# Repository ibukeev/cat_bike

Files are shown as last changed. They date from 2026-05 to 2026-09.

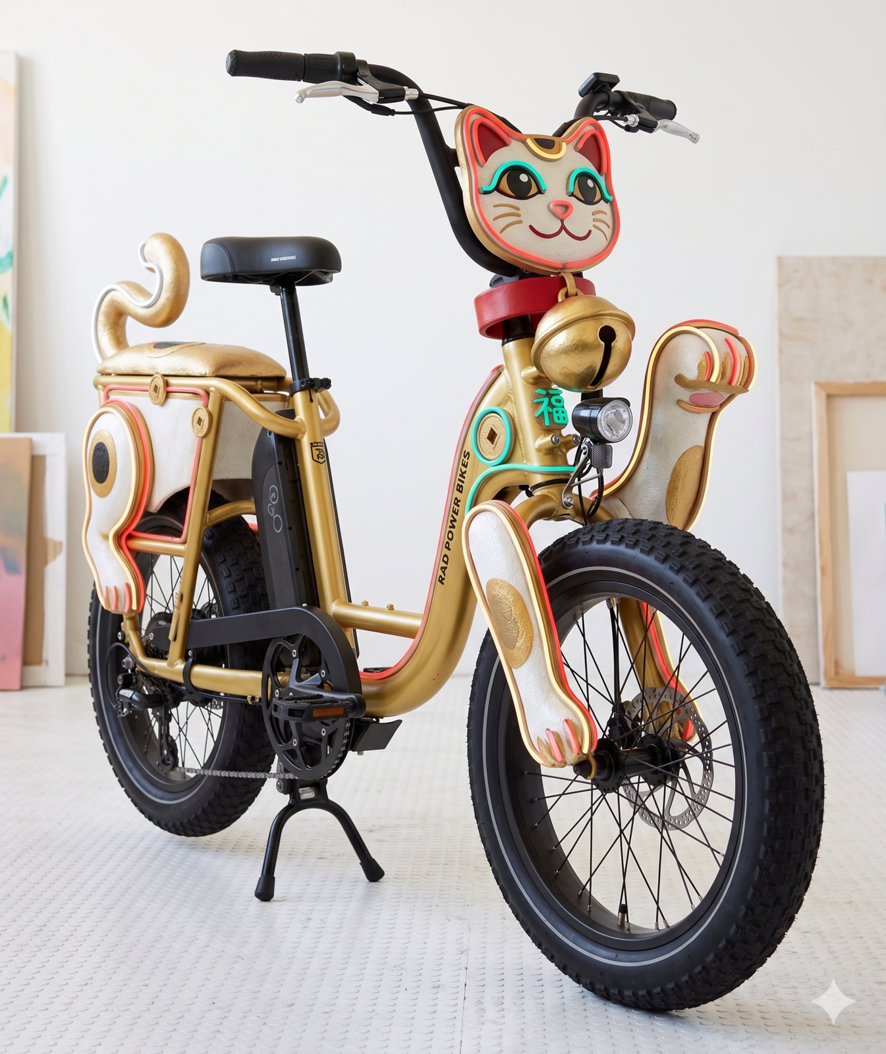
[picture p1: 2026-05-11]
assets/photos/Concepts/Other/Neon Maneki-Neko/Gemini_Generated_Image_xtucf9xtucf9xtuc.png

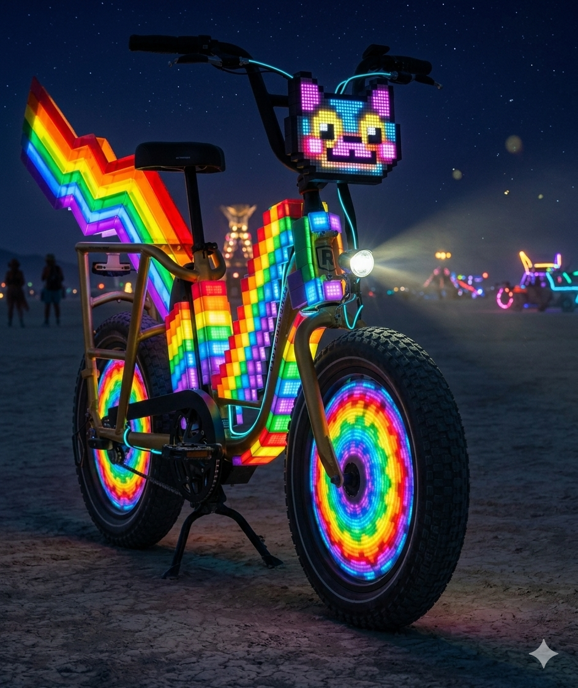
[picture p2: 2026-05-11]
assets/photos/Concepts/Other/16-Bit Nyan Astro-Cat/Gemini_Generated_Image_bhqeyjbhqeyjbhqe.png

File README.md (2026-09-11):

# Cat Bike LED Installation

Hardware project for a Burning Man electric bike LED installation.

## Getting the retained CAD and print files

Install [Git LFS](https://git-lfs.com/) before cloning this repository, then run:

```bash
git lfs install --local
git lfs pull
```

Selected mechanical CAD, meshes and slicer projects are stored with Git LFS.
Most generated output stays ignored; the curated build milestones are explicitly
tracked. A pointer-only checkout is not a usable CAD backup. Git history was not
rewritten when LFS was introduced, and retained working-file bytes are unchanged.

The repository tracks electrical design, Pixelblaze controller patterns, LED layout, battery/power notes, wiring, mechanical mounting ideas, and build documentation.

## Structure

- `hardware/electrical/` - battery, Pixelblaze controller, LEDs, and wiring.
- `hardware/mechanical/` - mounts, enclosures, and bike attachment parts.
- `software/pixelblaze-patterns/` - exported or source Pixelblaze patterns.
- `software/tools/` - helper scripts for mapping, validation, or exports.
- `docs/` - assembly notes, BOM, safety notes, and design logs.
- `assets/` - photos, diagrams, references, and visual documentation.
- `tests/` - manual and automated checks.

## Current build records

- [Lighting: mapper, patterns, setup, and validation](software/pixelblaze-patterns/mvp-bike/README.md).
- [Retained fabrication packages](hardware/mechanical/fabrication/3d-print/README.md): tiny prototypes, midsize Burning Man head, and controller enclosure.
- [Cleanup record and verified GitHub backup](docs/PROJECT_CLEANUP_PLAN.md).
- [Large-head working print files](hardware/mechanical/fabrication/3d-print/cat-head-full-size-v1/working/README.md): selected left/right lower-shell STL and slicer packages.

The large head has been reduced to [selected rebuild references](hardware/mechanical/fabrication/3d-print/cat-head-full-size-v1/README.md).
The rejected-output and cleanup-recovery archives were permanently deleted on
2026-09-10 after verifying the retained files in an independent GitHub download.
Only their inventories remain; deleted archive contents are not in the new backup.
No new whole-head print release was approved. The reports folder is empty.

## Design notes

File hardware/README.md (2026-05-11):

# Hardware

Use this area for electrical and mechanical design files.

- `electrical/battery/` - battery pack specs, charging notes, fuses, switches, and power budget.
- `electrical/controller-pixelblaze/` - Pixelblaze wiring, pinout, configuration, and controller mounting.
- `electrical/leds/` - LED strip or pixel specs, counts, layout, and power injection points.
- `electrical/wiring/` - cable plans, connector pinouts, harness drawings, and routing notes.
- `mechanical/mounts/` - brackets, clips, ties, and bike attachment parts.
- `mechanical/enclosures/` - controller, battery, and weather protection designs.

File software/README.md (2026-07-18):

# Software

Use this area for Pixelblaze patterns and helper scripts.

- `pixelblaze-patterns/` - pattern source, exports, and notes about palette, segment mapping, and controls.
- `tools/` - scripts for LED mapping, pattern export/import, validation, or documentation generation.

The 330 mm head-local pixel map and development patterns are under
`pixelblaze-patterns/cat-head/`.

Keep hardware-specific constants documented near the pattern or tool that uses them.

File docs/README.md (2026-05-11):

# Documentation

Use this area for build instructions, design decisions, safety notes, and field notes.

- `assembly/` - step-by-step installation and maintenance instructions.
- `bom/` - parts lists, vendor links, quantities, and alternates.
- `safety/` - power limits, fusing, waterproofing, strain relief, and Burning Man readiness checks.
- `notes/` - rough notes, measurements, and decision records.

## Current References

- `bom/cat-mask-ready-made-options.md` - ready-made cat mask purchase options and STL leads.

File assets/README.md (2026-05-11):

# Assets

Use this area for project media and reference material.

- `photos/` - installation photos, progress shots, and final build documentation.
- `diagrams/` - wiring diagrams, layout sketches, and exported schematics.
- `references/` - datasheets, vendor screenshots, inspiration, and external build references.

Prefer source files when possible, and export review-friendly images when useful.

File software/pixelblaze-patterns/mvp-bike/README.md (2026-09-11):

# MVP Bike Pixelblaze Pattern Set

This folder contains ten playa-riding patterns for the current 111-pixel bike
installation. Every visual pattern uses the same physical 2D mapper and also
includes a 1D fallback for editor preview.

## One-time Pixelblaze setup

1. Set **Settings > Pixels** to `111`.
2. Open the Mapper editor and paste `mvp-bike-spatial-map.js`.
3. Select **Contain** so the photographed bike proportions are preserved.
4. Save the mapper, then create one Pixelblaze pattern for each `*-2d.js` file.

The current mapper covers only the three established MVP body runs. It does not
yet include the later cat-head, whisker, eye, tail, panel, or wheel zones.

## Suggested saved order

| Order | Pixelblaze name | Source | Feel | Role |
|---:|---|---|---|---|
| 01 | Bike Aurora Front to Back | `aurora-front-to-back-2d.js` | Smooth | Flowing ambient color |
| 02 | Playa Techno Scanner | `playa-techno-scanner-2d.js` | Techno | Bouncing scanner and synthetic kick pulses |
| 03 | Ukrainian Flag Gentle Wave | `ukrainian-flag-gentle-wave-2d.js` | Smooth | Calm flag colors with restrained motion |
| 04 | Bioelectric Fur | `bioelectric-fur-2d.js` | Organic | Fine filaments and rear-to-front nerve impulses |
| 05 | Night Ride Beacon | `night-ride-beacon-2d.js` | Smooth | Continuous riding visibility and spatial orientation |
| 06 | Abyssinian Rosettes | `abyssinian-rosettes-2d.js` | Organic | Signature copper, aqua, and magenta cat identity |
| 07 | Playa Starfield | `playa-starfield-2d.js` | Smooth/show | Twinkling field with front-to-rear comets |
| 08 | Low Power Breath | `low-power-breath-2d.js` | Smooth | Simple continuously visible reserve mode |
| 09 | Neon Circuit Packets | `neon-circuit-packets-2d.js` | Techno | Beat-quantized, lane-switching data packets |
| 10 | Laser Lattice Techno | `laser-lattice-techno-2d.js` | Techno | Sliding laser grid with localized beat punches |

Each source exports its own Pixelblaze sliders. Defaults are starting points,
not calibrated electrical limits.

## Bench and bike testing

- Start physical commissioning with Pixelblaze global brightness at 15-25%.
- Verify the mapper with a one-pixel chase before judging spatial direction.
- Confirm that low `x` is the front and high `x` is the rear.
- Watch the 5 V supply, injection wiring, connectors, and strips for heating.
- Measure actual current before raising the global brightness limit.
- Keep the bike's independent headlight, taillight, and reflectors in service;
  these decorative patterns are not replacements for required safety lighting.

Run the off-device syntax and render-math check from the repository root:

```bash
node tests/automated/validate_mvp_bike_patterns.js
```

The local check catches parse errors, missing render entry points, non-finite
color output, out-of-range RGB/SV output, mapper count errors, and failures at
slider endpoints. Pixelblaze preview, visual quality, current draw, and thermal
behavior still require physical review.

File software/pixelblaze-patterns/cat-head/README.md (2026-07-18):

# Cat Head Pixelblaze Development Files

These files implement the head-local 52-pixel map defined by the formal
cat-head lighting development plan.

## Files

- cat-head-pixel-map.json: machine-readable wiring and optical allocation.
- cat-head-commissioning.js: isolated-head pixel and zone test pattern.
- cat-head-modes.js: riding, parked/show, and reserve behavior scaffold.

## Bench Setup

Configure Pixelblaze for 52 WS2812/SK6812-compatible RGB pixels and connect the
head or coupon as an isolated chain starting at pixel zero.

The physical data order is:

1. Left whisker carrier, including masked pixel H07.
2. Left eye.
3. Fourteen glow panels in Gate 1 pair order, left then right.
4. Right eye.
5. Right whisker carrier, including masked pixel H51.

Power the modules in parallel. Do not route the complete head current through
the first pixel module or through a long strip-copper path.

## Whole-Bike Integration

The patterns in this folder use head-local indices 0-51. When the head is
integrated into the whole-bike S5 range, apply the final S5 start offset before
using the same segment logic. Keep the head last on the initial single
Pixelblaze data output so removing it does not interrupt earlier zones.

The two reserved carrier pixels, H07 and H51, must remain black in every normal
pattern.

## Physical Calibration

These patterns are development scaffolds, not evidence that an optical gate has
passed. After Gate L1:

- Calibrate per-whisker brightness only if measured coupling variation requires
  it.
- Tune eye brightness after diffuser material and setback are locked.
- Tune each facet pair after the production cassettes are installed.
- Record measured current and final brightness caps in the validation report.

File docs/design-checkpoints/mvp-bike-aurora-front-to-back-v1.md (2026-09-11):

# MVP Bike Aurora Front-to-Back v1 Checkpoint

## Current output

- Pattern source: `software/pixelblaze-patterns/mvp-bike/aurora-front-to-back-2d.js`
- Spatial map: `software/pixelblaze-patterns/mvp-bike/mvp-bike-spatial-map.js`
- Reference pattern: `~/Projects/BM_personal_LED-projects /LED Hat Small/LED_hat_small/firmware/patterns/Archive/1D Aurora Borealis.epe`

## Accepted behavior

- Aurora curtains move from the bike front at low normalized `x` toward the rear at high normalized `x`.
- The effect uses both `x` and `y`: `x` controls travel and `y` bends and shimmers the curtains.
- The inherited palette character is green, chartreuse, turquoise, pink, and purple.
- Controls cover speed, curtain width, shimmer, brightness, saturation, palette weighting, and curtain count.
- A faint teal ambient floor maintains nighttime bike readability between curtains.

## Validation

- Source was evaluated in a Pixelblaze-compatible local harness.
- The pattern rendered 111 mapped coordinates across repeated frames without non-finite RGB output.
- Direction was checked against the current spatial-map contract: front is low `x`, rear is high `x`.
- On-device appearance and current draw remain unverified.

## Rejected or unsafe variants

- Do not use `index/pixelCount` as the primary position; it follows wiring rather than bike space.
- Do not run initial commissioning at unrestricted global brightness.
- The ambient floor is intentionally dim and is not a substitute for legally required bicycle lighting.

## Regeneration

The source is hand-authored and authoritative; there is no generator command.

## Next physical review

1. Paste the source into a new Pixelblaze pattern and save it as `01 Bike Aurora Front to Back`.
2. Confirm the mapper is saved and Pixelblaze is configured for 111 pixels.
3. Begin with the Pixelblaze global brightness limit at 15-25%.
4. Verify visible travel begins at the front and reaches the rear.
5. Tune speed, curtain width, shimmer, palette, and brightness with the pattern controls.
6. Observe the 5 V supply, wiring, and connectors for heating before increasing brightness.

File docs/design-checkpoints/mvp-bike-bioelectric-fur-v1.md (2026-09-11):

# MVP Bike Bioelectric Fur v1 Checkpoint

## Current output

- Pattern: `software/pixelblaze-patterns/mvp-bike/bioelectric-fur-2d.js`
- Spatial mapper: `software/pixelblaze-patterns/mvp-bike/mvp-bike-spatial-map.js`
- Target: the current 111-pixel MVP bike installation

## Accepted behavior

- Render fine, organic cyan-to-violet filaments over the whole bike.
- Send periodic electrical impulses from the rear (high x) toward the front
  (low x).
- Keep the effect internally timed; do not require a Sensor Expansion Board.
- Provide controls for motion speed, fur density, fur contrast, impulse rate,
  impulse strength, impulse width, color, and master brightness.
- Include a 1D fallback so the pattern remains visible before a 2D mapper is
  selected.

## Validation

- Static JavaScript syntax check: passed with Node's module parser.
- Render-math harness: passed 79,920 samples across 720 frames and all 111
  normalized mapper coordinates; every HSV output was finite and saturation and
  value remained within 0-1.
- Observed simulated value range with defaults: 0.020329-0.785307.
- 1D fallback render: passed with finite output.
- Pixelblaze 2D preview: pending user review.
- Physical 111-pixel bike review: pending.

## Rejected or deferred variants

- Do not synchronize the cat-head eyes, facets, or whiskers in this version;
  the current output targets only the established 111-pixel MVP bike map.
- Do not require sound input or the Sensor Expansion Board.
- Avoid full-frame white flashes; bright sparks remain localized around the
  traveling impulse.

## Exact regeneration command

This pattern is hand-authored and has no generation step. To perform the local
syntax check from the repository root:

```bash
node --input-type=module --check < software/pixelblaze-patterns/mvp-bike/bioelectric-fur-2d.js
```

## Next physical review

1. Configure Pixelblaze for 111 pixels.
2. Load `mvp-bike-spatial-map.js` as the mapper and select `Contain`.
3. Paste `bioelectric-fur-2d.js` into a new Pixelblaze pattern.
4. Confirm that each impulse travels from the rear toward the front.
5. Start with the default brightness, then tune it against the installed power
   limit and nighttime viewing distance.
6. Report whether the fur should be calmer, sharper, denser, or more colorful
   before starting the next pattern.

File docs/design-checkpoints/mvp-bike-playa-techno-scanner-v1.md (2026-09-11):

# MVP Bike Playa Techno Scanner v1 Checkpoint

## Current output

- Pattern source: `software/pixelblaze-patterns/mvp-bike/playa-techno-scanner-2d.js`
- Spatial map: `software/pixelblaze-patterns/mvp-bike/mvp-bike-spatial-map.js`
- Hat references: `Tunnel Scanner.epe` and `Riot Pulse.epe` in the LED Hat Small archive.

## Accepted behavior

- A hard scanner bounces across normalized bike space.
- Each internally generated techno kick launches an additional pulse from front to rear.
- The effect uses `y` for spatial tilt and moving grit, preventing the three physical runs from behaving as duplicated 1D strips.
- No audio sensor is required.
- Controls cover BPM, scanner speed, width, trail, kick strength, color, spatial tilt, grit, and brightness.
- Beat energy remains spatially localized rather than using continuous full-frame strobing.

## Validation

- Source was evaluated in a Pixelblaze-compatible local harness.
- The pattern rendered 111 mapped coordinates across repeated frames without non-finite color output.
- On-device appearance and current draw remain unverified.

## Rejected or unsafe variants

- The original hat references rely on Sensor Expansion Board data; this MVP version does not.
- Avoid continuous full-frame high-frequency strobing because of rider distraction and photosensitivity risk.
- Do not commission at unrestricted global brightness.

## Regeneration

The source is hand-authored and authoritative; there is no generator command.

## Next physical review

1. Paste the source into Pixelblaze and save it as `02 Playa Techno Scanner`.
2. Start with global brightness limited to 15-25%.
3. Confirm the kick pulse always travels from the bike front toward the rear.
4. Tune BPM near 120-135 for the intended techno feel.
5. Verify wiring and connectors remain cool before increasing brightness.

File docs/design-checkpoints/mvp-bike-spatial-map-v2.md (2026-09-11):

# MVP Bike Spatial Map v2 Checkpoint

## Current output

- Mapper source: `software/pixelblaze-patterns/mvp-bike/mvp-bike-spatial-map.js`
- Review overlay: `software/pixelblaze-patterns/mvp-bike/mvp-bike-spatial-map-review.svg`
- Review generator: `software/tools/generate_mvp_bike_spatial_map_review.js`
- Source photo: `assets/photos/Original_bike/pixed LAYAOUT.jpg`

## Accepted interpretation

- Configure 111 pixels.
- The three numbered red arrows are the centerlines and data directions.
- Section 1 is pixels 1-31, following the upper rear frame toward the rack.
- Section 2 is pixels 32-59, following the lower rear frame from the rear axle toward the crank.
- Section 3 is pixels 60-111, starting at the seat/battery edge, descending through the step-through curve, and rising toward the front stem.
- The handwritten numerals are labels rather than illuminated geometry.

## Validation

- The mapper returns exactly 111 finite 2D coordinates.
- Counts are 31, 28, and 52.
- The SVG overlays every generated pixel on the annotated photograph and labels each section start and end.
- Pixelblaze preview and a physical one-pixel chase remain pending.

## Rejected variants

- V1 reduced the arrows to generic straight runs and omitted important bends.
- V1 incorrectly started section 3 near the crank.
- Do not treat the handwritten numerals or arrowheads as extra LED branches.

## Exact regeneration command

From the repository root:

```bash
node software/tools/generate_mvp_bike_spatial_map_review.js
```

## Next physical review

1. Open the SVG and confirm each colored line follows the corresponding red arrow.
2. Paste the mapper into Pixelblaze with 111 pixels and `Contain` selected.
3. Run a one-pixel chase to confirm starts, ends, and increasing-index direction.
4. Record any installed pixels whose spacing differs from uniform spacing along the arrows.

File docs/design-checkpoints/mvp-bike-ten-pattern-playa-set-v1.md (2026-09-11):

# MVP Bike Ten-Pattern Playa Set v1 Checkpoint

## Current outputs

- Collection guide: `software/pixelblaze-patterns/mvp-bike/README.md`
- Spatial mapper: `software/pixelblaze-patterns/mvp-bike/mvp-bike-spatial-map.js`
- Off-device validator: `tests/automated/validate_mvp_bike_patterns.js`
- Target: current 111-pixel MVP bike body installation

| Pattern source | Character |
|---|---|
| `aurora-front-to-back-2d.js` | Smooth traveling aurora curtains |
| `playa-techno-scanner-2d.js` | Techno scanner and synthetic kick pulses |
| `ukrainian-flag-gentle-wave-2d.js` | Calm blue/yellow fabric motion |
| `bioelectric-fur-2d.js` | Organic filaments and nerve impulses |
| `night-ride-beacon-2d.js` | Restrained continuous riding glow |
| `abyssinian-rosettes-2d.js` | Copper, aqua, and magenta signature rosettes |
| `playa-starfield-2d.js` | Smooth twinkle and traveling comets |
| `low-power-breath-2d.js` | Simple dim reserve breathing |
| `neon-circuit-packets-2d.js` | Beat-quantized circuit lanes and packets |
| `laser-lattice-techno-2d.js` | Crossing laser grid and localized beat punches |

## Accepted behavior and constraints

- Preserve a varied ten-pattern set with smooth, organic, functional, and
  techno choices rather than tuning one effect before hardware review.
- Use the established 111-pixel 2D mapper for physical motion. Low normalized
  `x` is the bike front and high `x` is the rear.
- Keep every source self-contained with Pixelblaze sliders and a 1D editor
  fallback.
- Generate all beat timing internally; no Sensor Expansion Board is required.
- Keep techno impacts spatially localized. Do not add rapid full-frame white
  strobing.
- Treat brightness sliders as visual controls, not calibrated electrical power
  limits.

## Validation performed

- Node module syntax checks passed for all six sources created or recovered in
  this continuation.
- The complete local harness passed the mapper and all ten patterns.
- The mapper returned exactly 111 finite normalized coordinates.
- Each pattern rendered 240 frames at 30 FPS, all 111 mapped pixels, its 1D
  fallback, and every slider at `0`, `0.5`, and `1`.
- Total checked color samples per pattern ranged from 28,749 to 29,748.
- No non-finite colors or out-of-range RGB, saturation, or value outputs were
  detected.
- Pixelblaze preview, physical appearance, current draw, and thermal behavior
  remain unverified.

## Rejected, unsafe, or deferred variants

- No full-frame high-frequency strobe mode was added because it can distract
  the rider and create a photosensitivity hazard.
- No pattern depends on sound input because the current MVP does not require a
  Sensor Expansion Board.
- Cat-head eyes, facets, whiskers, tail, panels, and wheels remain out of this
  mapper; their absolute whole-bike offsets are not yet established.
- These decorative LEDs do not replace the bike's independent headlight,
  taillight, or reflectors.
- No pattern was uploaded to the physical Pixelblaze in this work session.

## Exact validation command

The patterns are hand-authored and have no generation command. From the
repository root, rerun the collection validator with:

```bash
node tests/automated/validate_mvp_bike_patterns.js
```

## Next physical review

1. Configure Pixelblaze for 111 pixels and save the mapper with **Contain**.
2. Run a one-pixel chase to verify all three path directions before evaluating
   the spatial effects.
3. Load the ten sources using the saved names and order in the collection
   README.
4. Start at 15-25% Pixelblaze global brightness.
5. Review the smooth group first, then the three techno patterns, and note which
   effects are too fast, too sparse, or visually confused on the real strip
   geometry.
6. Measure supply current and inspect the converter, injection wiring,
   connectors, and strips for heating before increasing brightness.
7. Record favorite patterns and slider settings for the next tuning pass.

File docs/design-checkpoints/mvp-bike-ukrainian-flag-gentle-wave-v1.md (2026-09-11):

# MVP Bike Ukrainian Flag Gentle Wave v1 Checkpoint

## Current output

- Pattern source: `software/pixelblaze-patterns/mvp-bike/ukrainian-flag-gentle-wave-2d.js`
- Spatial map: `software/pixelblaze-patterns/mvp-bike/mvp-bike-spatial-map.js`
- Hat reference: `Ukrainian Flag.epe` in the LED Hat Small archive.

## Accepted behavior

- The visual remains predominantly a static Ukrainian flag: blue above and yellow below.
- A small boundary ripple and mild fabric shading move from the bike front toward the rear.
- No strobe, blink, or Sensor Expansion Board behavior is included.
- Controls cover band boundary, boundary softness, ripple amount, motion speed, fabric shading, and brightness.
- Default motion is intentionally slow and restrained.

## Validation

- Source was evaluated in a Pixelblaze-compatible local harness.
- The pattern rendered 111 mapped coordinates across repeated frames without non-finite or out-of-range RGB output.
- On-device color appearance and current draw remain unverified.

## Rejected or unsafe variants

- The hat pattern's strobe and blink modes are intentionally omitted.
- Do not use rapid full-frame flashes during riding.
- Do not commission at unrestricted global brightness.

## Regeneration

The source is hand-authored and authoritative; there is no generator command.

## Next physical review

1. Paste the source into Pixelblaze and save it as `03 Ukrainian Flag Gentle Wave`.
2. Start with global brightness limited to 15-25%.
3. Confirm upper spatial pixels are blue and lower spatial pixels are yellow.
4. Confirm the gentle fold motion travels from front to rear.
5. Adjust the blue/yellow boundary if the sparse bike geometry favors one band.

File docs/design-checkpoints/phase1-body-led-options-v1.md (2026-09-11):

# Phase 1 body LED option set — resumable checkpoint

## Current review files

- Comparison: `assets/photos/Concepts/Selected/Bio-Luminescent Abyssinian/Phase_1_LED_References/body-strip-design-options-v1/00-comparison-sheet.jpg`
- Individual options: `01-minimal-feline-silhouette.png`, `02-bioluminescent-dashes.png`, `03-feline-ribcage.png`, and `04-geometric-facet-echo.png` in the same folder.
- Option descriptions and fabrication implications: `body-strip-design-options-v1/README.md`.
- Exact built-in image-generation sequence: `body-strip-design-options-v1/generation-prompts.md`.

## Status and accepted constraints

- No visual direction is selected yet.
- Options use removable 12 V LED strips rather than permanent illuminated panels.
- Fork, wheel, tire, spoke, brake rotor, chain, crank, steering, cable, and moving-component lighting is excluded.
- The cat head should remain the main focal point; body lighting should support rather than overpower it.

## Validation

- Four distinct directions were generated from the real side-profile bike geometry.
- The labeled comparison sheet was visually checked after correcting its original label order.
- Options 1 and 2 mostly use existing tubes; options 3 and 4 require removable backing bars and more fabrication.

## Rejected/unsafe variants

- The earlier fork-mounted strip was rejected.
- Generated strip placement is not clearance proof and must not be used as a cutting template.

## Regeneration

Use the built-in `image_gen` edit flow and follow `body-strip-design-options-v1/generation-prompts.md` in order. The sequence uses the latest image as the sole edit input (`num_last_images_to_include: 1`).

## Next physical review

1. User selects option 1–4 or names elements for a hybrid.
2. Produce a refined selected-side visual, then a mirrored opposite-side visual.
3. Measure only the selected paths and create the cut-length, connector, data-direction, power-injection, and zip-tie map.

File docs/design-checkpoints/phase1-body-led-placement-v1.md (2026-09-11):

# Phase 1 body LED placement — resumable checkpoint

## Current review output

- `assets/photos/Concepts/Selected/Bio-Luminescent Abyssinian/Phase_1_LED_References/phase1-body-strip-placement-proposal-v1.png`
- Base geometry reference: `assets/photos/Original_bike/front_back/02-bike-side-profile-wide.jpg`
- Aesthetic reference: `assets/photos/Concepts/Selected/Bio-Luminescent Abyssinian/Gemini_Generated_Image_5en5a65en5a65en5.png`

## Proposed decisions shown

- Phase 1 uses exposed/removable 12 V addressable strips rather than illuminated body panels.
- The strongest visual line follows the fixed lower frame and step-through/belly curve.
- Secondary strips describe the upper rear haunch/rack, one rear support, the forward edge of the battery/torso area, and the underside of the basket.
- Cyan/teal is illustrative; Pixelblaze color and animation remain programmable.
- The proposal is a visual-placement study, not yet a cut-length or pixel-index drawing.

## Validation performed

- Compared the concept, the existing Phase 1 reference, and the real side-profile photograph.
- Corrected the first generated variant after it incorrectly placed LEDs on the front fork.
- Confirmed the retained routes visually sit on fixed frame/rack members and avoid wheels and spokes in this side view.

## Rejected or unsafe variants

- No LED strips on front fork legs, wheels, spokes, tires, or brake rotors.
- No fabricated glowing side panels in Phase 1.
- Do not treat the generated glow as proof of clearance; chain, crank, battery-removal, cable, and tire clearances require physical measurement before cutting.

## Exact regeneration recipe

Built-in `image_gen` edit flow:

1. Load the real side-profile photograph, the current Phase 1 LED reference, and the selected bioluminescent concept.
2. Generate a dusk placement mockup with narrow cyan/teal LED-node strips on the fixed lower belly/frame, upper rear haunch/rack, rear support, forward torso/battery edge, and basket underside.
3. Run a correction edit with the latest generated image as the only input and this instruction:

   `Remove the entire cyan LED strip from the front fork leg. There must be no LEDs on either fork leg, wheel, spokes, tire, brake rotor, or steering/moving component. Preserve the strips on the fixed lower frame and step-through belly curve, lower horizontal frame tube, rear upper haunch/rack tube, rear support strut, forward torso/battery edge, and basket underside. Preserve everything else unchanged.`

## Next physical-review steps

1. User reviews the silhouette and chooses which proposed lines to keep or remove.
2. Measure retained paths directly on the bike with a flexible tape.
3. Record segment lengths, LED counts, data directions, connectors, power injection, and zip-tie locations.
4. Produce left/right/front/rear fabrication overlays before cutting the waterproof strip.

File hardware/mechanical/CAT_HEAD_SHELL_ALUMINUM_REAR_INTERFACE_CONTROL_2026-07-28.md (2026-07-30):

# Cat Head Shell / Aluminum Rear Interface Control

**Date:** 2026-07-28
**Status:** V0.5-M2 rear-interface digital correction passed; receipt, coupon,
complete-head correction, fabrication, final ASA-print, and riding release
gates remain held
**Integration authority:** User

## 1. Purpose

This document coordinates the separate cat-head shell and aluminum-mount work
sessions. It is the authority for geometry or behavior shared by those two
workstreams. It does not replace either workstream checkpoint:

- Shell defects and required validation:
  `hardware/mechanical/CAT_HEAD_MOUNT_AND_SHELL_PHYSICAL_FIT_REVIEW_2026-07-28.md`
- Aluminum V0.5-M2 coordinated interface state:
  `hardware/mechanical/fabrication/metal/cat-head-frame-fixed-mount-v0/V05_M2_COORDINATED_BOTTOM_M5_CHECKPOINT_2026-07-29.md`

The aluminum V0.5-M2 files are the tracked handoff authority. V0.4-M2 remains immutable history. The shell session must consume but not edit the aluminum-owned config, generator, summary, or checkpoint. The aluminum session must not edit Gate 3,
Gate 5, or Gate 8 shell sources while their existing partial state is under
review.

## 2. Coordination rule

No session may independently change or release a shared-interface parameter.
A proposed change must be recorded here with its affected shell and metal
files, reviewed in both workstreams, and approved by the user before either
session regenerates shared geometry or releases material for fabrication.

This coordination freeze is not a fabrication approval. It preserves a common
reference while the physical-feedback pass remains open.

## 3. Workstream ownership

| Area | Primary workstream | Coordination requirement |
|---|---|---|
| Bike boss plate, side webs, compact adapter, metal tether | Aluminum mount | May not move the head rear plane without shared approval. |
| Aluminum head backplate and lower angle connectors | Aluminum mount | M2 owns the retained plate centers, angle bases, uprights, cheeks, plugs, taper pads, compound rail cuts, and lower M5 stack; the shell must consume their exact envelope. |
| Exterior head shape, shell partitioning, reinforcement, mirror-panel seats | Printed shell | Must preserve the coordinated rear plane and rail system unless a shared change is approved. |
| Upper/front printed rail sockets and M4 retention paths | Shared | Must be generated from the same rail-axis and socket-roll revision as the aluminum backplate and rails. |
| Rear ASA frame, rear shell facets, removable rear cassette | Printed shell | Proposed architecture only; attachment and load transfer are shared. |
| Backplate perimeter fasteners, rail pass-throughs, wiring, drainage, tool access | Shared | Neither session may finalize independently. |
| Final assembly and service sequence | Shared | Must be validated with complete shell, aluminum, rail, fastener, and tool envelopes. |

## 4. Retained shared geometry baseline

The following values are the current V0.2 coordination baseline. They are
frozen against unilateral changes but remain review-only and are not released
for cutting:

**Active aluminum integration review artifact:**
`hardware/mechanical/fabrication/metal/cat-head-frame-fixed-mount-v0/output/review-model/frame-fixed-mount-v02-review.blend`

The user is currently reviewing this BLEND and confirmed that the aluminum
work remains review-only. No physical backplate has been ordered or cut. The
parallel aluminum work began under the assumption that the printed ASA rear
structure would not be redesigned; that assumption is now explicitly open
because physical findings F-04 and F-29 require a rear-interface and
printability correction.

The user accepts the overall V0.2 aluminum architecture as the direction to
retain. This is concept acceptance, not a cutting release. The current printed
ASA rear base conflicts with that metal envelope and must be revised. Possible
movement of the lower rail targets toward center remains TBD.

| Interface parameter | Provisional baseline |
|---|---|
| Mount architecture | Frame-fixed, no weld, and no printed polymer in the primary bike-connector load path. |
| Head coordinate bounds | X `-151.915..151.915`, Y `0..269.345`, Z `0..330` mm. |
| Rear interface plane center | Head coordinates `[0, 264.01125, 171.74025]` mm. |
| Rear interface outward normal | `[0, 0.990996, 0.133894]`. |
| Rear-plane mating pitch | `-18.894665°` relative to the estimated boss plane. |
| Aluminum head backplate | 3 mm 6061 trapezoid; 60 mm top, 120 mm bottom, 79.663819 mm high. |
| Adapter-to-backplate pattern | Four 6.6 mm paths at X `±22` mm and local V `±20` mm. |
| Internal rail stock | Nominal 19.05 mm square aluminum tube. |
| Lower rail targets | Head coordinates `[-40, 267.336, 147.132]` and `[40, 267.336, 147.132]` mm. |
| Rail orientation | Pitch `17.662°`, yaw `5.595°`; upper M4 axes approximately `5.333°` from head-horizontal. |
| Upper retention | One transverse M4 bolt per blind printed upper socket. |

Any need to change one of these values must be raised here before either model
is edited.

### 4A. Lower rail-target inward-shift assessment

At the current lower target, local backplate V is approximately `-24.832` mm
and the trapezoid half-width is approximately `54.351` mm. With a 19.05 mm
tube centered at X `±40`, the nominal tube/pass-through envelope leaves about
`4.826` mm to the sloped plate edge. The nearest lower 6.6 mm adapter-hole
center is about `18.637` mm away.

Moving a rail center to X `±35` improves nominal edge clearance to about
`9.826` mm, but reduces center distance to the lower adapter hole to about
`13.869` mm. The raw tube half-width plus M6-hole radius already consume about
`12.825` mm of that distance, leaving only about `1.044` mm before accounting
for the rail shoe, bolt head, washer, nut, manufacturing tolerance, or tool
access.

Therefore a simple inward shift is not approved. The user accepted X `±40` as
the baseline for the first coordinated ASA rear-structure revision. If rail
movement is still needed after full collision review, optimize rail X/V
position, adapter holes, backplate outline, lower-shoe envelope, and upper
socket axes as one shared interface change.

## 5. V0.4-M2 historical baseline and open shared interfaces

The V0.4-M2 baseline below remains immutable history. Its bottom shell M5 pair is superseded by the coordinated V0.5 delta in Section 5A; do not fabricate from V0.4.

The user ordered Randall Manufacturing `1.5 x 1.5 x 0.125 inch` 6063-T6
equal angle and authorized the aluminum workstream to incorporate it without
changing the accepted rail axes, X `+/-40` targets, 21 mm sockets, backplate
outline, adapter holes, or six-plus-six M5 plate-hole centers. The M2 authority
is `hardware/mechanical/interfaces/cat-head-shell-aluminum-interface-v04.json`
and the M2 checkpoint dated 2026-07-29. No plate is ordered or cut. The angle
is ordered but not yet received or measured.

Historical V0.4 details, superseded only where Section 5A says so and never released for fabrication:

1. six backplate-to-shell M5 centers: local X/V `(-10,30)`, `(10,30)`,
   `(-20,0)`, `(20,0)`, `(-10,-30)`, and `(10,-30)` mm;
2. six angle-base M5 centers, three per side, using right centers `(36,-30)`,
   `(47.4,-30)`, `(38,-9)` mm and mirrored left X;
3. one 45 mm primary angle per rail with full 38.1 mm upright and 29 mm
   trimmed base, plus one `45 x 25 x 3.175 mm` outer cheek per rail;
4. a matched 14.7 mm nominal solid plug, two hand-fit aluminum taper pads, and
   two M5 x 40 lower crossbolts per rail at 14 and 29 mm from the compound
   bearing centerline;
5. rail centerline length `152.476123 +/-0.25 mm`, 160 mm rough cuts,
   compound edge range `147.0677..157.8845 mm`, and upper M4 station
   133.776123 mm from the lower bearing datum; and
6. no backplate rail cutout and no external shell pass-through; service remains
   through the open rear aperture.

The M1 monolithic CNC shoes and 149.672 mm square-ended rails are superseded.
The generator plate-local V basis was also corrected to match the shared
interface; the earlier reversed M1 visualization must not be used for shell
integration.

Still open and held:

1. receipt inspection of the ordered angle's leg widths, thickness, inside
   radius, straightness, and alloy/temper marking;
2. actual rail inside dimensions/corner radii and fitted-plug machining;
3. one physical rear-interface/angle coupon proving flush countersinks,
   compound bearing contact, taper pads, M5 access, clamp behavior, and repeatable
   assembly;
4. shell/rear-cassette and six ASA pad integration around the exact M2 metal
   and tool envelope, followed by complete A-39 validation;
5. rear cassette seam, overlap, sealing, removal, wiring, and drainage;
6. actual headlight housing, beam, steering, and cable clearance; and
7. tether, proof-load, vibration, and progressive ride validation.

The regenerated M2 collision matrix records no intersection between the nine
checked metal parts and the current V6.1 fixed shells, bezel, or bottom keel.
This is a useful baseline, not a shell release: any new shell revision must
preserve or improve that clearance and rerun the complete assembly/service
matrix.

### 5A. V0.5 coordinated bottom-center delta

Shell coordination commit `0077da2330c0eeae403ab8698c6c1db58bd1b22f` proved that the V0.4 bottom shell M5 centers at X `+/-10`, V `-30` cannot carry a safe printed boss through the required preassembled-M2 motion: the largest clear circular boss was 11 mm, leaving only 0.5 mm outside the 10 mm washer. No plate had been ordered or cut, so the shared change was accepted.

V0.5 changes only the bottom pair to X `+/-7.4`, V `-30` and specifies `14 x 36 x 12 mm` bottom ASA pads. The top and middle shell centers, all six angle-base holes, plate outline, adapter holes, rail axes, X `+/-40` targets, 21 mm sockets, M4 retention, rail lengths, and compound datums are unchanged. The authoritative shared file is `hardware/mechanical/interfaces/cat-head-shell-aluminum-interface-v05.json`.

The V0.5 aluminum generator passes every check. Recorded margins are 7.0819 mm hole-to-plate edge, 4.8319 mm washer-to-edge, 2.8319 mm 14 mm tool-to-edge, 0.8 mm between opposing 14 mm tools, and 7.3963 mm from a bottom tool envelope to the nearest adapter-hole edge. The coordinated bottom pads also pass washer bearing, tool containment, opposing-pad, seated-metal, and pad-specific sampled-motion checks.

The full V7 shell candidate is not released. Its coordinated rerun still finds non-bottom blockers: middle-M5 nut-tool interference with lower crossbolts, preassembled lower-crossbolt sweep into the upper shells, socket-cap overlap with the receiver shells, and a root-recess validator sign/definition defect. These are recorded in `hardware/mechanical/fabrication/3d-print/cat-head-full-size-v1/review/gate9-v7-v05-coordinated-interface-validation.json`.

### 5B. V0.5 shell-consumer correction

The Gate 9 V7 shell consumer has now closed all four non-bottom failures from
the historical coordinated rerun without changing aluminum-owned CAD or any
locked V0.5 datum. The correction uses pre-installed shell-side captive M5
nylocs, exact 31 mm lower-crossbolt service tunnels cut only through new
internal truss material, 0.3 mm-relieved removable socket-cap receivers, and a
root validator that separately measures controlled shell overlap and cavity
reach.

All 15 rear-interface geometry checks pass. The complete M2 module clears 14
sampled socket-withdrawal positions and four rear-clearance positions, and
insertion is the exact reverse. All eight modified printed parts also have real
Prusa MK4 Generic ASA support/brim slices with at least 10 mm XY margin; the
minimum is 11.935 mm on `left_lower_face`.

This is a digital rear-interface pass, not a complete-head or fabrication
release. Physical angle/rail receipt, a rear-interface coupon, the remaining
F-07 through F-29 shell/insert/eye/panel work, lamp and steering clearance, and
physical safety validation remain held. The authoritative closure record is
`hardware/mechanical/fabrication/3d-print/cat-head-full-size-v1/review/gate9-v7-v05-shell-correction-validation.json`.

## 6. Rear cassette proposal C-001

**Status:** Proposed for coordinated evaluation; not accepted and not modeled.

To correct physical-fit findings F-04 and F-29 without shrinking the complete
head, evaluate a removable rear cassette that:

- moves the lower-face shell seams forward and transfers the aft shell facets
  to a rear-loaded printed module;
- incorporates or attaches to the shallow printed rear frame around the
  aluminum backplate;
- preserves the current rear plane, adapter hole pattern, and rail targets if
  practical;
- installs and removes from behind after the front and side shells are joined;
- makes each lower-face STL comfortably printable with its required brim and
  supports;
- leaves the aluminum backplate and rail structure as the primary mount load
  path; and
- treats the exterior rear facets as replaceable shell/finish parts rather
  than primary bike-mount structure.

The preferred implementation is not a permanent fusion of cosmetic ASA to the
aluminum plate. It is a mechanically attached printed rear module that may be
removed with, or separately from, the aluminum backplate according to the
approved service sequence.

## 7. Required comparison before accepting C-001

After the user closes the feedback pass, compare at least these three variants
without releasing fabrication:

| Variant | Required evidence |
|---|---|
| Existing lower-face partition and difficult rotation | Saved PrusaSlicer orientation, brim/support footprint, support volume, print time, and surface-risk review. |
| Uniform head scale reduction | Smallest scale that creates an acceptable orientation, plus impact on every mount, fastener, eye, insert, panel, and rear-plane interface. |
| Rear cassette / moved seam | Lower-face and cassette bed margins, support volumes, complete assembly collision test, backplate/rail integration, and service sequence. |

Acceptance of a variant requires the user to review the exterior appearance,
assembly sequence, printer evidence, and aluminum-interface impact together.

## 8. Shared release gates

No rear-interface metal or replacement structural shell is released until:

1. the user declares the physical-feedback pass complete;
2. both workstreams use the same rear-plane and rail-target revision;
3. the full shell and aluminum assembly has zero collision through insertion,
   seated, fastened, and removal states;
4. the rear cassette or retained partition passes the complete build-plate test
   in A-37;
5. all backplate, angle-connector, cassette, washer, nut, and tool envelopes are validated;
6. a physical rear-interface and angle-connector coupon passes;
7. actual headlight and steering clearance is validated;
8. an independent metal safety tether is specified; and
9. the stationary proof-load, vibration, and progressive ride-test plan is
   approved.

## 9. Cross-session change log

| ID | Date | Proposal or change | Status | Affected workstreams |
|---|---|---|---|---|
| C-001 | 2026-07-28 | Evaluate rear-loaded cassette incorporating aft shell facets to improve lower-face printability and rear service. | Proposed; no CAD action | Shell and aluminum |
| C-002 | 2026-07-28 | Use `frame-fixed-mount-v02-review.blend` as the active aluminum integration-review artifact. | User review in progress; no fabrication approval inferred | Shell and aluminum |
| C-005 | 2026-07-28 | Record aluminum fabrication commitment state: no plates ordered; only rectangular aluminum rail stock purchased. | Confirmed by user; rail dimensions still require physical verification | Shell and aluminum |
| C-003 | 2026-07-28 | Preserve the V0.2 aluminum rear-plane pose, plate outline, adapter pattern, and rail targets where practical while redesigning the printed ASA rear structure around that baseline. | Preferred coordination target; integrated validation required | Shell and aluminum |
| C-004 | 2026-07-28 | Rebuild the upper/front printed sockets to the coordinated V0.2 compound rail axes and socket roll; do not reuse pre-correction upper-shell G-code. | Required shared correction; regeneration held until feedback closes | Shell and aluminum |
| C-006 | 2026-07-28 | Retain the overall V0.2 aluminum architecture and redesign the conflicting printed ASA rear base/shell around its complete envelope. | Concept accepted by user; interface details and fabrication remain open | Shell and aluminum |
| C-007 | 2026-07-28 | Keep lower rail targets at X `±40` for the first ASA rear redesign; evaluate inward movement only if the complete collision review still requires it, including adapter-hole, backplate-edge, shoe/tool, upper-socket, and shell impacts. | Accepted baseline; conditional study deferred | Shell and aluminum |
| C-008 | 2026-07-29 | Authorize the aluminum workstream to finalize lower shoes, anti-crush paths, rail cut/drill stations, and backplate perimeter/shoe holes from V0.4 without changing the 21 mm socket geometry. | Authorized and completed as V0.4-M1 | Aluminum, then shell integration |
| C-009 | 2026-07-29 | Adopt the V0.4-M1 six-plus-six plate pattern and CNC-shoe handoff. | Superseded by C-010 before metal fabrication | Shell and aluminum |
| C-010 | 2026-07-29 | Use the ordered Randall 38.1 x 38.1 x 3.175 mm 6063-T6 angle for hand-fabricated M2 lower connectors; retain the six-plus-six plate centers, frozen axes/targets/sockets, add compound-cut 152.476123 mm rails, solid plugs, taper pads, outer cheeks, and matched M5 x 40 crossbolts. | M2 digital preflight passed; angle ordered but not received; no plate ordered or cut; coupon and shell A-39 pending | Aluminum, then shell integration |
| C-011 | 2026-07-29 | Move only the bottom shell M5 pair from X `+/-10` to X `+/-7.4` at V `-30` and use `14 x 36 x 12 mm` bottom ASA pads. | Accepted and generated as V0.5-M2; aluminum PASS; bottom pads PASS; full V7 shell candidate held on non-bottom issues; no fabrication or ASA-print release | Shared |
| C-012 | 2026-07-29 | Resolve the four non-bottom V7 shell-consumer failures with pre-installed captive M5 nylocs, service tunnels through only new truss material, relieved removable socket-cap receivers, and corrected root-overlap semantics. | Digital rear-interface PASS; real Prusa ASA feasibility PASS; physical coupon, complete-head correction, fabrication, and final ASA release held | Printed shell consuming locked V0.5 |

## 10. Next synchronization action

No backplate is ordered or cut. The rectangular 19 x 19 x 2 mm rail stock is
purchased. The Randall 6063-T6 equal angle is ordered but not received; its
actual section remains a receipt gate.

The shell workstream now has a digital PASS for the V0.5-M2 rear interface and
its complete modeled A-39 insertion, seated, fastened, tool, and removal phases.
Its next action is to preserve that locked interface while correcting the
remaining complete-head physical-fit findings, then validate an
angle/rail/rear-interface coupon with the received hardware. The final ASA head
print remains prohibited until those broader gates pass.

When the angle arrives, the aluminum workstream records the received dimensions
before cutting even a coupon. Final plate or bracket cutting remains held until
the receipt inspection, shell integration review, and physical angle-interface
coupon plan are accepted.

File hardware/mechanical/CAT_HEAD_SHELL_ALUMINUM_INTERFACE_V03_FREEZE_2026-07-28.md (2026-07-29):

# Cat Head Shell / Aluminum Interface V0.3 Freeze

**Date:** 2026-07-28
**Revision:** `CAT-HEAD-SHELL-ALUMINUM-V0.3`
**Status:** Frozen for coordinated rear-architecture comparison; not a print,
cut, drilling, or riding release
**Supersedes:** the unmeasured nominal-rail assumption in C-005 and the active
shared dimensions duplicated in the Gate 8 and aluminum V0.2 configs

## 1. Authority

The machine-readable authority is:

`hardware/mechanical/interfaces/cat-head-shell-aluminum-interface-v03.json`

Both new workstreams resolve that file rather than treating their historical
configs as shared-interface authorities:

- shell:
  `hardware/mechanical/fabrication/3d-print/cat-head-full-size-v1/config/gate9-coordinated-asa-candidate-v1.json`
- aluminum:
  `hardware/mechanical/fabrication/metal/cat-head-frame-fixed-mount-v0/config/frame-fixed-mount-v03-interface.json`

Gate 8 and aluminum V0.2 remain immutable historical/review baselines. Their
generated outputs are not relabeled as V0.3.

## 2. Measured rail stock

The user physically measured and confirmed:

| Property | V0.3 value |
|---|---:|
| Outside width | 19.0 mm |
| Outside height | 19.0 mm |
| Wall thickness | 2.0 mm |
| Derived inside width/height | 15.0 x 15.0 mm |
| Available stock length | 36 in = 914.4 mm |
| Dimensional consistency | Reported the same along the stock |
| Corner radius | Not measured |
| Alloy/temper | Not confirmed |

Final rail cut lengths remain deferred until the lower shoes, solid plugs,
socket seating depth, rear cassette, and complete fit-up are fixed.

## 3. Frozen comparison interface

- Preserve the 330 mm full-size head exterior for the primary comparison.
- Rear plane center: `[0, 264.01125, 171.74025]` mm.
- Rear plane outward normal: `[0, 0.990996, 0.133894]`.
- Aluminum backplate: 3 mm 6061-T6 trapezoid, 60 mm top, 120 mm bottom,
  79.663819 mm high.
- Adapter pattern: four 6.6 mm paths at X `±22` and local V `±20` mm.
- Lower rail targets: X `±40`, Y `267.336`, Z `147.132` mm.
- Accepted rail axes:
  - left `[-0.09294, -0.94874, 0.30208]`;
  - right `[0.09294, -0.94874, 0.30208]`.
- Rail pitch `17.662°`; yaw `5.595°`.
- Socket roll: head X projected perpendicular to each rail axis.
- Socket opening: 20.5 x 20.5 mm.
- Nominal clearance from measured stock: 1.5 mm total, 0.75 mm per side.
- Socket insertion depth: 30 mm.
- Upper retention: one 4.5 mm M4 clearance path 10 mm inside the mouth.
- Expected M4-axis deviation from head X: `5.333°`.
- Primary bike connector load path remains metal only.
- Rear service direction remains rear-loaded after joining the main shells.

Changing any frozen value requires one coordinated revision affecting the
shell, backplate, lower shoes, rails, sockets, validation, and checkpoints.

## 4. Validation performed

The standalone interface validator passed:

- rear-plane normal unit error within `0.0001`;
- lower-target plane error `0.0000831` mm, below the `0.01` mm limit;
- rail-axis unit and symmetry checks;
- measured-wall derivation of the 15 x 15 mm inside profile;
- 0.75 mm nominal socket clearance on every side, within the frozen 0.5–1.0
  mm review range;
- 914.4 mm stock covers two 158.172 mm modeled routes before final fit/cut
  allowance;
- raw 19 mm tube envelope leaves approximately 4.851 mm to the sloped
  backplate edge at each X `±40` lower target.

The 4.851 mm value covers only the raw tube. It is not clearance approval for
the lower shoe, flange, bolt, washer, nut, manufacturing tolerance, hand, or
tool envelope.

Both consumer preflights passed and reported the identical revision:

- `PASS - GATE 9 SHARED INTERFACE PREFLIGHT`;
- `PASS - METAL V0.3 SHARED INTERFACE PREFLIGHT`.

Python compilation and JSON parsing passed. Blender, STL export, drawing
export, rendering, PrusaSlicer, and physical coupon tests were intentionally
not run.

## 5. Generation holds

V0.3 geometry generation remains disabled because:

1. the rear cassette, retained partition, and scale alternatives have not been
   compared and selected;
2. Gate 8 append-only structural mesh joins still violate the required
   single-body topology contract;
3. lower shoes and anti-crush plugs are not detailed;
4. rail pass-throughs and backplate perimeter/shoe holes are not released;
5. the complete shell/aluminum/hardware/tool collision matrix does not exist;
6. a matching Gate 9 shell validation report does not exist; and
7. physical rear-interface and socket coupons have not passed.

## 6. Rejected or unsafe variants

- Do not restore the nominal 19.05 mm active-stock assumption.
- Do not resize the 20.5 mm socket solely from nominal catalog dimensions; use
  a full-scale coupon to account for ASA shrinkage and printer variation.
- Do not move the X `±40` rail targets independently.
- Do not treat raw tube-to-plate edge clearance as lower-shoe clearance.
- Do not overwrite or relabel Gate 8 or aluminum V0.2 outputs as V0.3.
- Do not cut rails to the 158.172 mm modeled reference length.
- Do not release backplate or shoe holes before the rear architecture and
  complete service sequence are selected.

## 7. Exact preflight commands

Run from the repository root:

```bash
python3 hardware/mechanical/interfaces/cat_head_interface.py
python3 hardware/mechanical/fabrication/3d-print/cat-head-full-size-v1/source/prepare_gate9_shared_interface.py
python3 hardware/mechanical/fabrication/metal/cat-head-frame-fixed-mount-v0/source/prepare_frame_fixed_mount_v03_interface.py
```

There is intentionally no V0.3 Blender regeneration command yet. The next
versioned generators must consume the preflight loaders, write the V0.3
revision and interface hash into their validation reports, and use the new
Gate 9/V0.3 output namespaces before generation is enabled.

Historical commands remain documented in the Gate 8 and aluminum V0.2
checkpoints but are not V0.3 release commands.

## 8. Next review steps

1. Build review-only geometry for the retained partition, smallest-useful
   uniform scale, and full-size rear-cassette/moved-seam alternatives.
2. Include complete backplate, rail, raw lower-shoe allowance, hardware, and
   tool envelopes in every comparison.
3. Slice each alternative with the required brim/support policy and record
   actual bed margin, support volume, time, supported exterior area, and
   removal risk.
4. User selects the architecture and service sequence.
5. Repair the single-body topology and validation foundation before detailed
   subsystem geometry or any full structural print.

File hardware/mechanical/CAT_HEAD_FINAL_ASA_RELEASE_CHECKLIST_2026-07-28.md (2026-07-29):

# Cat Head Final ASA Candidate Release Checklist

**Date:** 2026-07-28
**Status:** Draft execution checklist; awaiting physical-feedback closure and
rear-architecture decision
**Target:** One production-candidate black-ASA structural head set for the
Prusa MK4S, followed by full physical acceptance before riding

## 1. Authority and scope

This is the execution and go/no-go checklist for the next full structural
print. It consolidates, but does not replace:

- `hardware/mechanical/CAT_HEAD_MOUNT_AND_SHELL_PHYSICAL_FIT_REVIEW_2026-07-28.md`
  — authoritative findings F-01 through F-29 and tests A-01 through A-39;
- `hardware/mechanical/CAT_HEAD_SHELL_ALUMINUM_REAR_INTERFACE_CONTROL_2026-07-28.md`
  — authoritative shared shell/aluminum interface and decisions C-001 through
  C-007; and
- the relevant Gate 3, Gate 5, Gate 8, mirror-panel, and aluminum resumable
  checkpoints.

Checking an item here does not override a more specific acceptance condition
in either authority document. This checklist does not itself authorize CAD
regeneration, metal cutting, or a full ASA print.

## 2. Current decisions and holds

- [x] Use black ASA for the final opaque structural head shell.
- [x] Retain the overall frame-fixed, no-weld V0.2 aluminum architecture.
- [x] Keep the lower rail targets at X `±40` for the first coordinated shell
  revision.
- [x] Keep printed polymer out of the primary bike-connector load path.
- [x] No aluminum plate has been ordered or cut; only rectangular rail stock
  has been purchased.
- [x] Treat current Gate 8 generated outputs and pre-correction upper-head
  G-code as potentially stale or obsolete.
- [x] Do not regenerate while physical feedback remains open.
- [ ] User explicitly declares the physical-feedback pass complete.
- [ ] User selects the rear-shell architecture for the next version.

**Recommended rear-shell choice:** preserve the approved full head scale and
evaluate a rear-loaded cassette/moved rear seam around the V0.2 aluminum
envelope. Do not accept the existing difficult lower-face orientation as the
production solution. Use global scaling only if a documented slicer comparison
shows that a genuinely small reduction solves the problem without compromising
the complete interface set.

## 3. Gate 0 — Close requirements and freeze the shared interface

- [ ] Confirm there are no additional physical defects to record.
- [ ] Select rear cassette/moved seam, retained partition, or uniform scaling.
- [ ] Record the selected architecture in the interface-control change log.
- [ ] Physically measure purchased rail outside width, wall thickness, length,
  corner radius, straightness, and alloy/temper if known.
- [ ] Freeze one shared interface revision containing:
  - rear plane center and normal;
  - aluminum-backplate outline and thickness;
  - adapter-to-backplate hole pattern;
  - lower rail targets and axes;
  - upper socket pitch, yaw, roll, depth, and M4 retention path;
  - rail stock dimensions; and
  - intended assembly and service direction.
- [ ] Give that revision one identifier used by both shell and aluminum
  validation reports.
- [ ] Confirm that neither session is about to order, cut, drill, or regenerate
  shared-interface parts independently.

**Gate 0 pass:** feedback is closed, rear architecture is selected, actual rail
stock is measured, and both sessions share one frozen interface revision.

## 4. Gate 1 — Recover and freeze a trustworthy source state

- [ ] Inventory every current Gate 3, Gate 5, and Gate 8 uncommitted change.
- [ ] Map each retained change to one or more findings F-01 through F-29.
- [ ] Identify the source/config revision and command that produced every
  existing STL, BLEND, report, render, and G-code intended for comparison.
- [ ] Mark outputs with unknown or mismatched provenance as stale; do not use
  them as regeneration inputs or acceptance evidence.
- [ ] Review the incomplete rear-base work and failed regeneration without
  resetting or discarding user/session changes.
- [ ] Select one traceable source baseline for the corrective iteration.
- [ ] Select a new versioned output location for the final-ASA candidate so
  Gate 8 physical-test artifacts remain available for comparison.
- [ ] Record exact generation, rendering, validation, and slicing commands in
  the resumable checkpoint before geometry edits begin.

**Gate 1 pass:** every retained source change and comparison output has known
provenance, and the corrective iteration starts from one traceable state.

## 5. Gate 2 — Lock the global shell and rear architecture

- [ ] Import the accepted V0.2 aluminum review geometry and unchanged approved
  exterior shell into one integration assembly.
- [ ] Generate a collision map for aluminum plate, adapter hardware, lower
  shoes, rails, upper sockets, rear base, and all adjacent shells.
- [ ] Produce review-only comparisons for:
  - existing lower-face partition and difficult orientation;
  - smallest useful uniform scale reduction; and
  - rear cassette/moved rear seam at unchanged exterior scale.
- [ ] For each comparison, report shell part count, bed margin including brim,
  support volume, print time, seam count, assembly order, service access, and
  aluminum-interface changes.
- [ ] User approves the selected exterior scale, shell partition, rear seam,
  rear service opening, and assembly sequence.
- [ ] Verify that the selected rear module itself fits the MK4S bed in a stable,
  support-efficient orientation.
- [ ] Preserve X `±40` lower rail targets unless the collision study proves a
  coordinated rail/plate/socket change is required.

**Gate 2 pass:** the shell architecture is approved visually and mechanically,
and every production section has a credible print orientation before detailed
connectors or reinforcement are added.

## 6. Gate 3 — Repair the geometry-generation foundation

- [ ] Replace append-only overlapping structural meshes with true dependable
  unions or an equivalent single-body construction.
- [ ] Reject every production STL with more than one connected component unless
  a removable part is deliberately exported separately.
- [ ] Retain closed-manifold, boundary-edge, and nonmanifold-edge checks.
- [ ] Add finished-exterior deviation checks against the approved clean faceted
  baseline.
- [ ] Clip all ribs, gussets, pads, flange roots, and connectors to the interior
  envelope before union.
- [ ] Add complete seated-state and insertion-path collision checks.
- [ ] Add slicer checks for floating islands, unsupported first extrusions,
  brim/support boundary fit, and saved production orientation.
- [ ] Fail generation when any required check fails; no report-only warnings
  for production blockers.

**Gate 3 pass:** validation can no longer accept the disconnected, protruding,
colliding geometry classes seen in the PLA prototype.

## 7. Gate 4 — Correct every subsystem

### 7A. Rear shell and aluminum interface

- [ ] Rear structure installs from behind after the main shells are joined.
- [ ] No rail, plate, shoe, bolt, washer, nut, tool, or insertion envelope
  intersects the ASA rear structure or adjacent shells.
- [ ] Backplate holes have real bolt, washer, nut, finger, and tool clearance.
- [ ] Structural pads have broad shell roots and adequate bearing area.
- [ ] Wiring and drainage paths are defined and remain serviceable.
- [ ] Upper sockets match the frozen V0.2 rail axes and socket roll.
- [ ] Requirements A-01 through A-06 and A-38 through A-39 pass digitally.

### 7B. Main shell seams, reinforcement, and exterior

- [ ] Opposing shell reinforcements have complementary non-overlapping
  envelopes.
- [ ] Every shell pair closes to its intended gap without cutting, melting,
  bending, or force.
- [ ] No internal connector or reinforcement protrudes through an exterior or
  mirror-cap landing plane.
- [ ] Each body-shell export is one connected printable component.
- [ ] Requirements A-33 through A-36 pass digitally.

### 7C. Lower-face printability

- [ ] Lower-face or replacement sections use a stable orientation with required
  brim and support entirely inside the printable area.
- [ ] At least 10 mm remains to each XY printable boundary after required brim,
  unless the user approves a different margin from a physical printer test.
- [ ] Support volume, print time, supported exterior area, and removal access
  are reviewed before release.
- [ ] Requirement A-37 passes in the saved PrusaSlicer project.

### 7D. Eyes

- [ ] Eye front frame, bezel, chamber, and structural roots form one dependable
  connected body.
- [ ] No front-frame feature begins as a floating printable island.
- [ ] Remove the long thin eye-mount cantilever and use short broadly rooted
  supported attachments.
- [ ] Eye installs and removes without colliding with any shell, reinforcement,
  glow panel, skirt, fastener, or tool envelope.
- [ ] Retain the eye at separated upper and lower locations.
- [ ] Place one eye back-plate connector high and one low.
- [ ] Requirements A-23 through A-26 and A-28 through A-32 pass digitally.

### 7E. Ears and under-ear insert

- [ ] Replace opposing printed ear pins with two accessible M3 bolt paths using
  one round clearance hole and one tolerance slot.
- [ ] Under-ear insert clears both upper corners and lower center and seats by
  hand without scraping or bending.
- [ ] Insert planes align before fastener tightening and do not slide under
  clamp load.
- [ ] Use two or three short tolerance-friendly retention points.
- [ ] Enlarge and broadly root under-ear flanges with direct hardware/tool
  access.
- [ ] Add the outer anti-flap ear tie without loading an illuminated region.
- [ ] Requirements A-07 through A-12, A-18, and A-27 pass digitally.

### 7F. Glow panels and skirts

- [ ] Preserve useful light-control skirts while relieving every real shell,
  reinforcement, corner, flange, and fastener collision.
- [ ] Central panel has at least three separated retention points, including a
  strong lower connection on the vertical nose-side structure.
- [ ] Front nose-side and side panels each use two larger connectors broadly
  rooted into the panel body, not the skirt.
- [ ] All fasteners and tools remain accessible in the documented sequence.
- [ ] Requirements A-13 through A-22 pass digitally.

## 8. Gate 5 — Digital production-candidate release

- [ ] All findings F-01 through F-29 have an implemented disposition.
- [ ] All acceptance tests A-01 through A-39 have recorded digital results.
- [ ] Every production STL is single-component, closed manifold, and free of
  unintended internal loose bodies.
- [ ] Complete assembly and insertion collision matrices report zero unintended
  intersections.
- [ ] Exterior-deviation report shows zero unintended positive protrusions.
- [ ] Review renders show exterior, interior, seams, eyes, ears, glow panels,
  rear cassette, rails, backplate, hardware, tools, and service sequence.
- [ ] Every production STL has a named saved PrusaSlicer orientation.
- [ ] Slicer preview contains no floating islands or unsupported first
  extrusions.
- [ ] Required brim and supports fit on the bed with the approved margin.
- [ ] Support volumes, print times, filament estimates, and supported visible
  areas are documented.
- [ ] User approves the review package before any full structural part is
  printed.

**Gate 5 pass:** the complete digital candidate is approved and only targeted
physical coupons are authorized.

## 9. Gate 6 — Full-scale physical coupons before the full ASA set

- [ ] Actual rail in revised upper-socket coupon: insertion, clearance, rattle,
  drilling, M4 retention, bridge quality, and removal.
- [ ] Rear interface coupon: aluminum plate, rail pass-through, lower shoe,
  representative ASA structure, M5/M6 hardware, and tool access.
- [ ] Representative upper/lower shell seam coupon: closure, reinforcement
  clearance, round/slot alignment, and fastener access.
- [ ] Ear two-bolt round/slot coupon.
- [ ] Eye bezel/chamber/frame coupon: print continuity and hand-load strength.
- [ ] Under-ear retention and corner-clearance coupon.
- [ ] Representative glow-panel skirt/connector corner coupon.
- [ ] Black-ASA exterior and mirror-cap landing coupon.
- [ ] PETG cap to black-ASA adhesion coupon using selected 3M 9474LE/300LSE:
  surface preparation, 72-hour dwell, heat exposure, and peel/shear check.
- [ ] Repeat or revise every failed coupon; do not waive a failure because the
  full print is expensive or time-sensitive.

**Gate 6 pass:** all high-risk interfaces pass at full scale in production
materials with actual stock and hardware.

## 10. Gate 7 — Final ASA print authorization

- [ ] Black ASA is received, dry, and qualified on the enclosed MK4S.
- [ ] Build sheet, adhesive/release practice, enclosure, ventilation, nozzle,
  and slicer profile are documented and proven by the coupons.
- [ ] All exact fasteners, rails, inserts/nuts, washers, and tools are on hand.
- [ ] Final STLs, 3MFs, validation reports, renders, BOM, and assembly sequence
  share the same version identifier.
- [ ] No source/config file is newer than the released STL/3MF/report package.
- [ ] No known stale G-code is present in the release package.
- [ ] Print the smallest or least expensive structural section first and verify
  dimensions before starting the longest lower/upper section.
- [ ] Inspect every completed part before authorizing the next expensive print.

**Gate 7 pass:** user authorizes the versioned production-candidate ASA print.

## 11. Gate 8 — Physical assembly and ride release

- [ ] Complete shell assembles with no cutting, melting, bending, or forced
  fastener alignment.
- [ ] Eyes, ears, inserts, glow panels, mirror caps, rear cassette, rails, and
  backplate install and remain serviceable in the documented order.
- [ ] All seams close and exterior mirror-panel seats remain clean.
- [ ] Complete head mounts to the bike without steering, lamp, beam, cable,
  control, or rider-sightline interference.
- [ ] Independent metal safety tether is installed.
- [ ] Stationary multidirectional proof load passes with no slip, crack, creep,
  permanent deformation, or fastener movement.
- [ ] Vibration test and progressive low-speed rides pass before normal use.

The first ASA print is a production candidate, not ride approval. Gate 8 must
pass before the assembly is treated as final.

## 12. Exact next step

The next step is **Gate 0**, not CAD regeneration.

The user must confirm:

1. the physical-feedback pass is complete; and
2. the rear cassette/moved-rear-seam direction at unchanged head scale is
   approved for the comparison study.

After those confirmations, the shell session performs Gate 1 as a read-only
audit, then produces the Gate 2 collision and printability comparison package.
No production geometry is edited until the audit establishes a trustworthy
source baseline and the aluminum session confirms the same interface revision.

## 13. Resume checkpoint

Current review files:

- `hardware/mechanical/CAT_HEAD_MOUNT_AND_SHELL_PHYSICAL_FIT_REVIEW_2026-07-28.md`
- `hardware/mechanical/CAT_HEAD_SHELL_ALUMINUM_REAR_INTERFACE_CONTROL_2026-07-28.md`
- `hardware/mechanical/CAT_HEAD_FINAL_ASA_RELEASE_CHECKLIST_2026-07-28.md`

Accepted decisions are recorded in Section 2. No corrective CAD, STL, G-code,
or metal fabrication change was made while creating this checklist.

Next physical-review action: finish any remaining observations, declare the
feedback pass closed, and approve or reject the recommended rear-cassette
comparison direction.

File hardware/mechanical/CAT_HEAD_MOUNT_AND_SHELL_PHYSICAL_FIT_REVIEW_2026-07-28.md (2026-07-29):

# Cat Head Mount and Shell Physical-Fit Review

**Review date:** 2026-07-28
**Status:** Open — physical feedback collection in progress; corrective CAD and
regeneration on hold
**Review basis:** Physical bike measurements, bike photographs, printed-part test
fitting, and direct user feedback
**Affected designs:** Gate 8 full-size cat head and frame-fixed aluminum bike
mount V0.2

## 1. Purpose

This document is the formal source of truth for the user’s feedback on the
current cat-head body shells, seams and reinforcement, rear base,
under-left-ear translucent insert, ear attachment, glow panels, eye assemblies,
and bike connector. It distinguishes measured inputs from observed physical
failures and from proposed engineering responses. This merged revision records
findings F-01 through F-29 and acceptance tests A-01 through A-39.

No affected STL, G-code, or fabrication drawing is approved for another
production print or metal cut until the user closes the feedback pass and the
applicable acceptance tests in Section 11 pass.

## 2. Accepted interface decisions and measured inputs

| ID | Requirement or measurement | Status |
|---|---|---|
| D-01 | The cat head is frame-fixed and does not rotate with handlebar steering. | Accepted |
| D-02 | A purchased front rack is not required. The frame connector may be custom manufactured. | Accepted |
| D-03 | Retain the existing fork-mounted front light; relocation is not assumed. | Accepted |
| D-04 | Use a no-weld aluminum mount. | Accepted |
| D-05 | Head-tube boss pattern is 30 mm horizontal center-to-center and 90 mm vertical center-to-center. | User measured |
| D-06 | Boss outside diameter is 18 mm. | User measured |
| D-07 | Available bolt dimension under the head is 14 mm. | User measured |
| D-08 | Raise the head approximately 60 mm relative to the earlier concept to clear the existing light. | User direction; final lamp-envelope check still required |

## 3. Bike-to-head connector feedback

### F-01 — Rail path is blocked by the head shell

**User observation:** The proposed rails cannot connect to the front/top head
portals because the plastic shell lies in the path.

**Failure:** The concept showed a load path that was not physically insertable
through the finished shell.

**Required correction:** The rail/socket interface must be accessible from
inside the shell or through a deliberately modeled opening. The finished shell
must not require cutting to reach or install the rail ends.

### F-02 — Portal axis is not aligned with the conceptual rail axis

**User observation:** The portal angle is visibly unusual and must be rotated or
explicitly accounted for.

**Failure:** A nominal straight or orthogonal rail assumption does not match the
actual portal direction.

**Required correction:** Derive and document the socket pitch and yaw from the
head geometry. Validate rail insertion along the complete socket axis, not only
at the endpoint. The final upper/front sockets must match the coordinated V0.2
aluminum baseline: lower rail targets at head X `±40`, Y `267.336`, Z `147.132`
mm, rail pitch `17.662°`, yaw `5.595°`, and socket roll that leaves the M4 axes
approximately `5.333°` from head-horizontal. These are shared interface values
and may not be changed by the shell or aluminum session independently.

**Output-state warning:** Gate 8 source contains the V0.2 portal revision, but
the current source/configuration are newer than the generated upper-shell STLs.
Upper-head G-code produced before the socket-axis and roll correction is
explicitly obsolete. No existing STL or G-code is approved as the final shared
portal geometry until both sessions regenerate and validate from one frozen
interface revision.

### F-03 — Existing light interference

**User observation:** The earlier head/mount concept interfered with the front
light.

**Required correction:** Preserve the existing light and raise the head by
roughly 60 mm as the initial correction. Final approval requires a measured
three-dimensional light-housing envelope and steering-sweep check.

## 4. Rear base and aluminum backplate feedback

### F-04 — Rear base is not installable without cutting printed material

**User observation:** Flanges and reinforcement connecting the upper and lower
head sections blocked the rear base. Printed material had to be cut away to
install it. The later full-shell assembly confirmed the same failure:
`rear_base.stl` collided with surrounding reinforcement and could not seat
until reinforcement material was cut away.

**Severity:** Blocking.

**Failure:** The rear base was modeled as a deep undercut component whose
installation sequence conflicts with the already assembled shell and internal
reinforcement.

**Required correction:** The rear base must load from the rear after the four
main body shells are assembled. Installation and removal must not require
cutting, bending, or destructive modification of the shell, flanges, or ribs.
The complete rear-base insertion sweep must include all adjacent shell
reinforcement, not only the nominal rear opening.

**Cross-session update:** The user accepts the V0.2 aluminum mount concept but
observes that its backplate/rail assembly conflicts with the current printed
rear base and may conflict with adjacent shell geometry. The printed ASA rear
structure must be redesigned around the coordinated aluminum envelope. Moving
the lower rail targets inward remains a shared TBD and is not an approved
substitute for correcting the shell.

### F-05 — Horizontal backplate holes are too close to corners

**User observation:** The holes in the horizontal pieces are too close to the
corners, preventing the bolt from being fitted. This clearance problem had been
reported previously and must not recur.

**Severity:** Blocking.

**Failure:** Hole-center placement was checked geometrically but not against the
real bolt-head, washer, nut, finger, and tool envelope.

**Required correction:** Move the lower horizontal attachment holes away from
the corners and validate the complete hardware/tool envelope. The current
engineering response moves the lower pair from `x = ±30 mm` to `x = ±15 mm`;
this remains subject to physical-fit approval.

### F-06 — Rear-base mounting flanges are too small and flimsy

**User observation:** The mounting flanges are too small to place a nut and are
too weak for a primary structural connection.

**Severity:** Blocking and structural.

**Failure:** The original tabs did not provide adequate bearing area, nut
seating area, washer clearance, wrench/socket access, or load distribution.

**Required correction:** Replace the small tabs with large structural pads
sized around the actual fastener and tool envelope. The current engineering
response uses six rear-loaded M5 paths, a minimum 14 mm nut/tool envelope, and
nominal 28 × 36 × 10 mm shell-side pads. These dimensions are provisional until
CAD validation and a physical coupon pass.

## 5. Under-left-ear translucent insert feedback

**Likely affected part:** `glow_insert_left_ear_root_cluster.stl`, also described
in the print set as the left under-ear panel. Confirm against the physical part
label or a photo before releasing a replacement print.

### F-07 — Upper corner collisions

**User observation:** Both corners of the translucent piece fight shell
material, including reinforcement.

**Failure:** The insert perimeter and/or hidden return occupies the same volume
as the shell rim, reinforcement, or flange-root geometry.

**Required correction:** Add explicit local relief at both reported corner
regions and validate the insert against the final reinforced shell, not against
the nominal exterior surface alone.

### F-08 — Lower-center collision

**User observation:** The lower center of the translucent piece also fights the
head.

**Failure:** The lower insert body, cap, flange, or connector does not have a
valid insertion/seating path.

**Required correction:** Add local lower-center relief and verify the complete
insertion sweep. The visible illuminated area should be preserved where
possible, but assembly clearance takes priority over a hidden overlap.

### F-09 — Insert is globally too snug

**User observation:** The translucent piece is too snug to the head and cannot
be seated reliably.

**Failure:** Nominal CAD clearance does not cover printed-part tolerance, shell
distortion, reinforced-edge variation, and the non-planar insertion path.

**Required correction:** Increase the deep-body perimeter clearance while
keeping any tight visual seam limited to a shallow, non-structural cap. Do not
use force-fitting as the assembly method.

### F-10 — Plane mismatch and lateral sliding under flange clamping

**User observation:** When the connecting flanges are brought together, the
overall planes of the translucent piece do not align with the rest of the head
and the part slides to one side. The lower part appears misaligned and fights
the head.

**Severity:** Blocking.

**Failure:** The current retention geometry over-constrains a multi-plane part
and converts fastener clamping into lateral displacement/twist.

**Required correction:** The seated exterior planes must be defined by broad,
repeatable datum surfaces. Fasteners must retain the already seated part rather
than pull it into position. Add lead-in and lateral tolerance so tightening
cannot cam the insert sideways.

### F-11 — One long connector over-constrains the insert

**User observation:** Two or three smaller connectors would be preferable to
one connector that prevents force fitting.

**Required correction:** Replace any continuous or long constraining connector
with two or three short, spatially separated retention points. Each point must
permit assembly tolerance; together they must prevent rattle without forcing
the insert out of plane.

### F-12 — Under-ear flange access and structural weakness

**User observation:** The under-ear connecting flanges are difficult to access
with the bolt and are too flimsy.

**Failure:** A nominally aligned fastener hole is not sufficient when the bolt,
washer, nut, fingers, or installation tool cannot approach and engage it. The
small flange body and narrow shell connection also create a likely flexing and
breakage point.

**Required correction:** Enlarge the under-ear flange body, connect it to the
main printed piece with a broad continuous root, and reposition the fastener as
needed to provide a direct installation path. Validate the complete bolt,
washer/nut, hand, and tool-access envelope against the final reinforced shell.

## 6. Left ear attachment feedback

### F-13 — Outer ear remains unsupported and flaps

**User observation:** After the main connecting flanges are screwed together,
the outside portion of the ear flaps and appears partly disconnected.

**Failure:** The existing ear flange concentrates restraint near one region and
does not control rotation at the outer ear root.

**Required correction:** Add a small, separated anti-flap connection near the
outer edge of the under-ear translucent region.

### F-14 — Requested outer grounding point through the under-ear insert

**User request:** Add a relatively small connector to the semi-transparent
piece to ground the ear on the outer side, because adding another direct
connection to the main head shell is difficult.

**Engineering interpretation:** Add a reinforced hidden lug beneath the opaque
border of the translucent insert and a matching short tab inside the ear shell,
retained by one internal M2.5 bolt with washers and a nyloc nut. This is an
anti-flap locator only; the primary ear loads must remain on the larger M3 ear
flange connection. The illuminated 1.5 mm diffuser skin must not be treated as
the primary structural load path.

## 7. Central glow-panel feedback

**Affected part:** Central translucent/glowing panel, including its continuous
rear skirt and shell-side retention features.

### F-15 — Continuous back-skirt collides with the head interior

**Positive feedback:** Adding a continuous rear skirt is a good design
direction because it closes the former holes/gaps.

**User observation:** The skirt fights the head interior, including
reinforcement pieces and other surrounding shell material. Installation
required cutting both the printed head and the skirt.

**Severity:** Blocking.

**Failure:** The back-skirt was evaluated as an isolated panel feature rather
than against the final reinforced head and its real insertion path. A
closed-manifold or visually gap-free result does not establish physical
installability.

**Required correction:** Preserve the useful continuous back-skirt concept, but
reshape and locally relieve it against the final shell, reinforcement, flange,
and fastener geometry. Validate the entire insertion sweep and final seated
position. Installation must not require cutting either the head or the panel.

### F-16 — Two upper connecting flanges do not prevent panel flapping

**User observation:** The central panel has only two connecting flanges at the
top and remains free to flap.

**Failure:** Two retention points concentrated along the same upper region do
not adequately constrain the lower portion of the panel.

**Required correction:** Add at least one spatially separated lower retention
point. The preferred location is the lower vertical piece near the nose. The
adjacent horizontal piece is too small and must not be used merely for
geometric convenience.

**Engineering interpretation:** The additional point should retain an already
seated panel rather than pull it into shape. Its flange, nut/washer area, tool
access, and surrounding shell clearance must be checked against the final
reinforced assembly.

**Additional structural requirement:** Make the new flange substantially larger
and connect it to the main printed piece through a broad, continuous root. It
must not be a small cantilevered tab or depend on a narrow neck.

**Failure risk:** An undersized or weakly rooted flange is likely to crack or
tear away during tightening, vibration, panel movement, or repeated service.

## 8. Front nose-side glow-panel feedback

**Affected part:** Front translucent/glowing panel near the nose. Confirm the
exact STL identifier against the physical part before revising or releasing a
replacement.

### F-17 — Skirt interference and immediate connector detachment

**Positive feedback:** The rear-skirt concept is useful and should be preserved
because it closes unwanted openings and light gaps.

**User observation:** The skirt does not physically fit the surrounding head
geometry. The attachment is also flimsy and detached almost immediately.

**Severity:** Blocking and structural.

**Failure:** The connector load appears to enter through a thin skirt or another
weak secondary feature rather than the main structural body of the glow panel.
The skirt is simultaneously over-sized for its available internal envelope and
under-strength for use as an attachment root.

**Required correction:** Treat the skirt only as a non-structural light-control
feature. Root the attachment geometry directly into the main structural body of
the glow panel. Use two larger, spatially separated connectors instead of one
small or weakly rooted connector.

**Fit requirement:** Reshape and locally relieve the skirt against the complete
final head, reinforcement, flange, and fastener geometry. Validate both the
insertion path and final seated position without cutting or force-fitting.

**Structural requirement:** Each connector must have a larger load-bearing body
and broad continuous root into the main glow-panel structure. Connector
tightening must not bend, peel, or load the skirt.

## 9. Side glow-panel feedback

**Affected part:** Side translucent/glowing panel. The exact side and STL
identifier must be confirmed against the physical part before revision.

### F-18 — Single weak connector and skirt collision around the perimeter

**User observation:** The side glow panel has one flimsy connector. Its skirt
fights the head around all corners and collides with reinforcement and flange
geometry.

**Severity:** Blocking and structural.

**Failure:** One small attachment point does not adequately constrain the panel
or distribute service loads. The skirt was not validated against the complete
internal corner, reinforcement, flange, and fastener envelope.

**Required correction:** Use two larger, spatially separated connectors rooted
directly into the main structural body of the side glow panel. The skirt must
remain non-structural. Add local relief at every affected corner and around all
reinforcement and flange regions.

**Validation requirement:** Check the complete insertion path and final seated
position against the finished reinforced shell. The panel must install without
cutting, scraping, bending, force-fitting, or using connector tension to pull it
into position.

## 10. Eye socket and eye back-plate feedback

**Affected parts:** Eye socket/module, its head-side mounting flanges, and its
back plate/rear cap. Confirm the eye side and exact STL identifiers against the
physical parts before revision.

### F-19 — Eye assembly collides with multiple internal head elements

**User observation:** The eye fights multiple elements inside the head and
cannot be installed without severe cutting.

**Severity:** Blocking.

**Failure:** The eye was not validated against the complete final internal
assembly or through its real insertion path. Shell reinforcement, flange roots,
glow-panel skirts/connectors, or other internal features occupy the required
installation and seated envelopes.

**Required correction:** Validate the complete eye assembly, not only its visible
front boundary, against every final internal head feature. Reshape or relocate
the conflicting hidden features and verify a non-destructive insertion path.
Installation must not require cutting the eye or head.

### F-20 — Eye-to-head retention lacks an upper connection

**Positive feedback:** The existing lower connecting flange is acceptable in
principle.

**User request:** Enlarge the lower flange for improved strength and add a
separate connection between the upper side of the eye and the head.

**Failure:** A lower-only attachment leaves the upper eye edge free to separate,
rotate, or flap. An undersized lower flange also concentrates load at its root.

**Required correction:** Retain the lower attachment location but enlarge its
load-bearing body and structural root. Add a spatially separated upper
eye-to-head connector with usable fastener and tool access. The connectors must
retain an already seated eye rather than pull it through interference.

### F-21 — Both eye back-plate connectors are on the lower side

**User observation:** The eye back plate is connected by two connectors, but
both sit on the lower side.

**Required correction:** Relocate one of the two back-plate connectors to the
top so the back plate is retained at separated upper and lower positions. Keep
both connectors attached to structurally substantial portions of the eye
module, with usable fastener and tool access.

**Failure risk:** Two lower connectors provide poor rotational and peel
restraint at the top of the back plate even when both fasteners are tight.

## 10A. Additional full-size PLA shell findings from the active review

The following findings merge the physical feedback captured in the active
full-size PLA assembly review. They are requirements only; they do not
authorize regeneration while the user is still providing feedback.

### F-22 — Ear connector presents printed pin against printed pin

**User observation:** On the printed left-side ear connection, both mating
parts carry male alignment pins. Assembly therefore presents pin against pin
rather than pin into a receiving hole.

**Severity:** Blocking.

**Failure:** The two sides of the interface are not complementary. No print
tolerance or assembly force can make two opposing solid pins occupy the same
space.

**Required correction:** Remove the printed alignment pins and use two
accessible M3 bolt paths through the mating flanges. Use one nominal 3.4 mm
round clearance hole and one short nominal 3.4 × 5 mm tolerance slot, subject
to a printed coupon, so the joint is constrained without over-constraining
normal print variation. Use washers and either locking nuts or captive threaded
hardware. Audit the mirrored ear interface before release.

### F-23 — Eye front frame is a disconnected printable island

**User observation:** The top/front eye frame disintegrated during printing.
PrusaSlicer preview showed the front frame disconnected from the rest of the
eye bucket and beginning in mid-air.

**Severity:** Blocking and printability-critical.

**Failure:** The STL can be manifold while still containing multiple closed,
disconnected components. The current generation path appends overlapping
objects without creating a true boolean union, and validation did not reject
multiple connected components. Inspection reported six slicer parts for each
of the left and right eye-bucket exports.

**Required correction:** Rebuild the eye bucket as one true geometric union.
The selected print orientation must provide layer-by-layer support from the
build plate into the entire front frame; no front-frame extrusion may begin as
a floating island. Manifold status alone is not an adequate pass condition.

### F-24 — Eye head-mount tab is a long, fragile, interfering cantilever

**User observation:** A thin flying connector on `left_lower_face` immediately
fought the neighboring pieces, had to be cut off to assemble the shells, and
was visibly too flimsy for Burning Man service. The mirrored side must be
treated as suspect until checked.

**Severity:** Blocking and structural.

**Failure:** The head-side eye attachment uses an approximately 21 mm bridge
with a nominal 4 × 2 mm section. It is simultaneously inside the neighboring
assembly envelope and cantilevered far enough to flex or snap under assembly
and vibration loads.

**Required correction:** Remove the long cantilever. Carry the eye load through
a short, broad, supported ledge or flange rooted directly into substantial
shell structure. The complete eye must install and be serviced without cutting
the mount, colliding with adjacent shells, or using a fastener to pull the eye
through interference.

### F-25 — Internal connectors and reinforcement protrude through the exterior

**User observation:** Connector and reinforcement features visibly stick out
on the exterior surface of `left_lower_face`. The same exterior contamination
is present on `left_upper_head`.

**Severity:** Blocking for appearance, mirror-panel fit, and shell assembly.

**Failure:** Geometry intended to remain internal crosses the approved faceted
outer surface. It creates visible bumps and obstructs the landing surface for
wrapped mirror panels. Mathematical offsets in the generator were not
validated against the actual finished exterior mesh.

**Required correction:** Restore the original clean faceted exterior. Clip all
ribs, flange roots, pads, and connectors to the interior envelope before true
union with the shell. Audit the right-side mirror parts as well. No hidden
feature may create an unintended positive deviation on a visible or panel-seat
surface.

### F-26 — Production shell exports contain many disconnected components

**Observed evidence:** PrusaSlicer reported 61 parts in `left_lower_face`, 61
in `right_lower_face`, and 41 in `left_upper_head`. This is consistent with
ribs, gussets, tabs, or pads being appended as separate closed meshes instead
of becoming one printable shell body.

**Severity:** Blocking and systemic.

**Failure:** Existing validation can accept boundary-clean meshes without
checking that each production STL is one connected body. Disconnected internal
objects can print poorly, detach, poke through an exterior plane, or occupy a
mating part envelope.

**Required correction:** Each production shell STL must contain exactly one
connected printable component unless a removable part is deliberately exported
as its own separately named STL. Boolean-union reinforcement into its parent
shell and add connected-component count to generation validation.

### F-27 — Opposing shell reinforcements occupy the same assembly volume

**User observation:** The left lower and left upper shell sections could not be
joined because reinforcement on the opposing shells collided before the
flanges met. Considerable PLA had to be cut or melted away. The rear-base joint
showed the same class of conflict, as recorded in F-04.

**Severity:** Blocking.

**Failure:** Both sides of a mating seam were reinforced independently without
reserving complementary, non-overlapping envelopes for the other side or for
the assembly motion.

**Required correction:** Assign one explicit reinforcement envelope to every
seam and build complementary geometry on the opposite shell. Digitally assemble
every pair and the complete shell at final coordinates, then test both the
seated state and the actual insertion path for collision. No seam may require
cutting, bending, or melting printed structure.

### F-28 — Eye bezel and chamber have an inadequate structural connection

**User observation:** The eye-socket front section separated completely from
the lower chamber/body because the connection surface between them was very
small.

**Severity:** Blocking and structural.

**Failure:** The nominal front bezel is only weakly overlapped with the chamber
geometry and was not made into a dependable continuous union. A tiny local
intersection is not an acceptable structural root even after the floating-part
failure in F-23 is corrected.

**Required correction:** Join the bezel to the chamber with a broad continuous
perimeter shoulder and a true boolean union. Provide enough overlap depth and
root thickness, with fillets or gussets where appropriate, to survive printing,
handling, assembly, and vibration. Validate the joint as both a single
connected body and a physical structural coupon.

### F-29 — Lower-face shell sections leave inadequate build-plate margin

**User observation:** One of the full-size shell pieces barely fit the Prusa
build plate and was extremely difficult to place and print successfully.

**Severity:** Blocking for repeatable fabrication.

**Observed evidence:** The existing automated orientation report marks both
lower-face sections as fitting, but reports a limiting-envelope utilization of
approximately 97.0% for `right_lower_face` and 96.9% for `left_lower_face`.
That binary result does not reserve practical space for the required brim,
supports, placement tolerance, slicer exclusion zones, or a safe distance from
the plate edge.

**Failure:** Printer-envelope validation treated a barely contained bounding
box as a fabrication pass. It did not validate the complete sliced job in its
documented orientation or require a usable XY margin after brim and support
generation. A part that fits only with exact edge placement is not a robust
production part.

**Required correction:** Repartition the affected lower-face shell geometry or
move its structural seam without changing the approved full-head exterior
scale. Every resulting production STL must have a documented PrusaSlicer
orientation in which the complete object, brim, supports, and travel-safe
placement fit comfortably inside the printable area. Target at least 10 mm
clearance from every XY printable-area boundary after the required brim unless
a later physical printer test establishes a different approved margin.

**Cross-session dependency:** A rear-cassette solution would change the shared
shell/aluminum interface and must follow
`hardware/mechanical/CAT_HEAD_SHELL_ALUMINUM_REAR_INTERFACE_CONTROL_2026-07-28.md`.
It is a coordinated proposal, not an accepted CAD change.
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

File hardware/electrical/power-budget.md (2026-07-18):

# Power Budget

## Purpose

Estimate LED current, battery needs, fuse sizing, and runtime for the Cat Bike LED installation.

## Current Assumptions

- Controller: Pixelblaze or Pixelblaze-compatible setup.
- Main visual palette: cyan/aqua/magenta/violet with brightness limits.
- Bike use case: Burning Man night riding with a lower-power riding mode and brighter parked/show mode.
- Electrical decision: use 5 V addressable RGB LEDs as the primary LED system.
- Electrical decision: use a dedicated LED battery only. Do not tap or modify the bike traction battery.
- Phase 1 should include independent LED zones and reserved interfaces for later head, tail, panel, and wheel zones.
- Battery and power distribution should be sized for the likely whole-bike build, not just the first installed Phase 1 zones.
- Phase 1 should reserve fused branch capacity and connectors for later cat head, tail, and body panel loads.
- The 330 mm cat head uses fourteen individually controlled side-glow fibers, eight eye pixels, and twenty-eight facet pixels; see the [formal lighting development plan](leds/cat-head-lighting-development-plan.md).

## Phase 1 LED Count Estimate

| Zone | Estimated Pixels | Notes |
|---|---:|---|
| Lower frame segmented spine | 60-120 | Main Phase 1 visual zone. |
| Fork gill accents | 24-60 | Short segments on both fork legs. |
| Rear rack rib accents | 40-100 | Repeated short segments on rack supports. |
| Basket underside glow | 30-80 | Hidden glow under basket bottom edge. |
| Ground underglow | 30-80 | Downward-facing visibility/glow; may share physical LEDs with lower frame/rack zones. |

Initial Phase 1 installed planning range: 184-440 pixels before cat head, tail, body panels, or wheels. This is intentionally broad until actual LED density and measured path lengths are selected.

## Future Whole-Bike LED Count Estimate

The power system should support later expansion without rebuilding the main battery, fuse, switch, and distribution architecture.

| Phase | Zone | Low Pixels | Nominal Pixels | High Pixels | Notes |
|---|---|---:|---:|---:|---|
| Phase 1 | Lower frame segmented spine | 60 | 90 | 120 | Active first build. |
| Phase 1 | Fork gill accents | 24 | 40 | 60 | Active first build. |
| Phase 1 | Rear rack rib accents | 40 | 70 | 100 | Active first build. |
| Phase 1 | Basket underside glow | 30 | 50 | 80 | Active first build. |
| Phase 1 | Ground underglow | 30 | 50 | 80 | Active first build; may overlap with frame/rack LEDs. |
| Phase 2A | Cat head facets | 28 | 28 | 28 | Locked: two pixels behind each of fourteen approved facets. |
| Phase 2A | Eyes | 8 | 8 | 8 | Locked: four pixels behind each uniform eye diffuser. |
| Phase 2A | Fiber-optic whisker light engines | 16 | 16 | 16 | Locked: two eight-pixel sticks, fourteen direct-coupled fibers, two masked pixels. |
| Phase 2B | Tail | 30 | 80 | 160 | Depends on length and density. |
| Phase 3 | Body panels | 80 | 180 | 360 | Depends heavily on panel geometry and diffuser strategy. |
| Phase 4 | Optional wheels | 0 | 0 | 240 | Deferred; do not size baseline requirement around this unless explicitly included. |

| Scenario | Included Scope | Total Pixels |
|---|---|---:|
| Phase 1 low | Installed starter zones only | 184 |
| Phase 1 nominal | Installed starter zones only | 300 |
| Phase 1 high | Installed starter zones only | 440 |
| Whole bike low, no wheels | Phase 1 + head + eyes + fiber whiskers + tail + modest panels | 346 |
| Whole bike nominal, no wheels | Phase 1 + locked 52-pixel head + tail + panels | 612 |
| Whole bike high, no wheels | Phase 1 + locked 52-pixel head + tail + dense panels | 972 |
| Whole bike high, with wheels | High whole-bike build plus optional wheels | 1,212 |

## Current Estimate Formula

For WS2812-style 5 V pixels, worst-case current is commonly estimated as:

```text
max_current_amps = pixel_count * 0.06
```

For practical animation use, plan a brightness-limited estimate:

```text
typical_current_amps = max_current_amps * brightness_limit * pattern_factor
```

Initial planning values:

- `brightness_limit`: 0.25 to 0.50
- `pattern_factor`: 0.35 to 0.70
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

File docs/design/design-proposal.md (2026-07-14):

# Design Proposal

## Purpose

Define how the Bio-Luminescent Abyssinian concept should translate into a real, rideable bike build.

The concept images are the visual north star, not literal fabrication drawings. The build should preserve the strongest identity cues while simplifying anything that would make the first version fragile, heavy, hard to mount, or impossible to finish iteratively.

## Design Position

Build toward a polished faceted bio-luminescent cat bike, but do not copy the AI concept exactly.

The concept is strongest when it reads as:

- A gold/yellow utility bike transformed into a cat.
- A faceted copper or rose-gold cat face at the front.
- Bright cyan/aqua eyes.
- Fiber-optic whiskers.
- Cyan, aqua, magenta, and violet glow.
- A curled illuminated tail at the rear.
- Organic body glow that can become more sculptural in later phases.

The concept is weakest where it invents impractical or over-busy details:
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

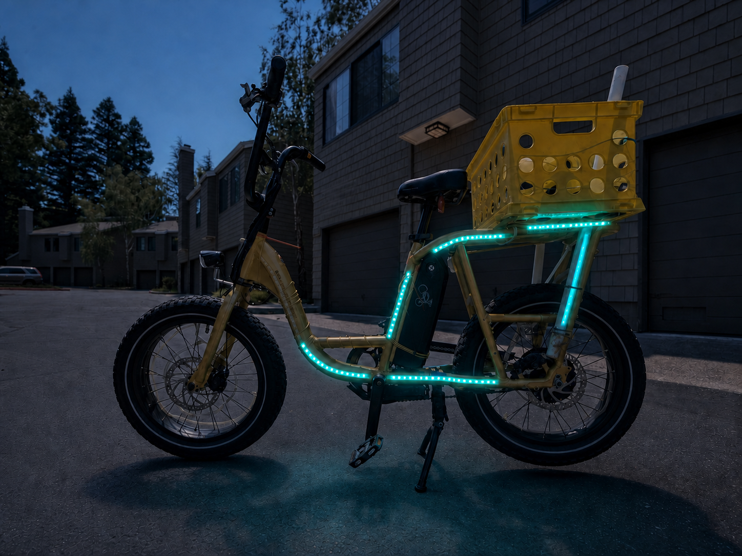
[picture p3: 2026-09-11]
assets/photos/Concepts/Selected/Bio-Luminescent Abyssinian/Phase_1_LED_References/phase1-body-strip-placement-proposal-v1.png

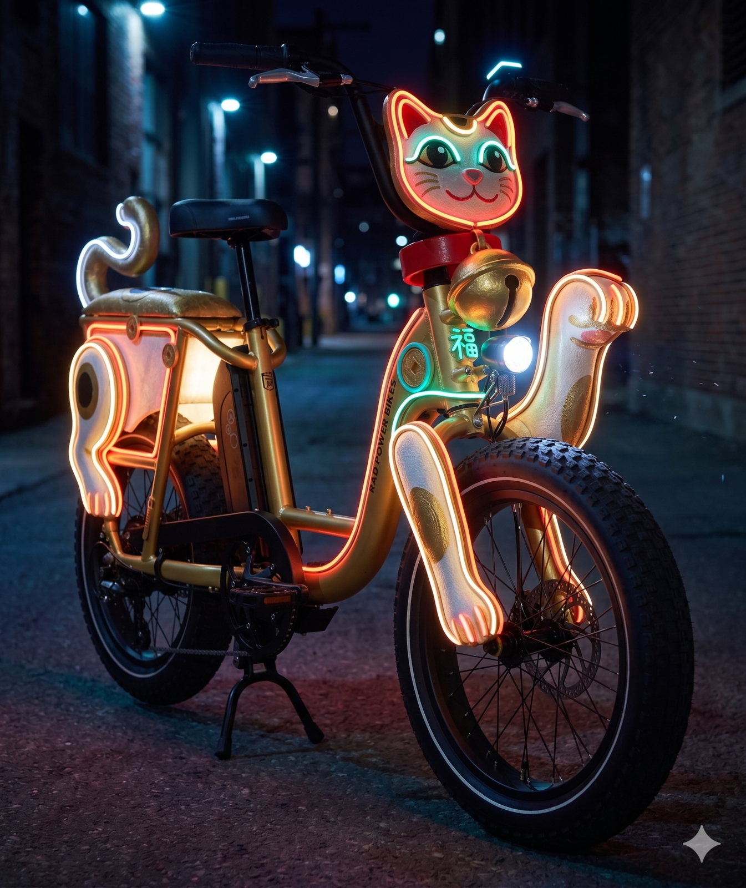
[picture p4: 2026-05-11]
assets/photos/Concepts/Other/Neon Maneki-Neko/Gemini_Generated_Image_x2ytbtx2ytbtx2yt.png

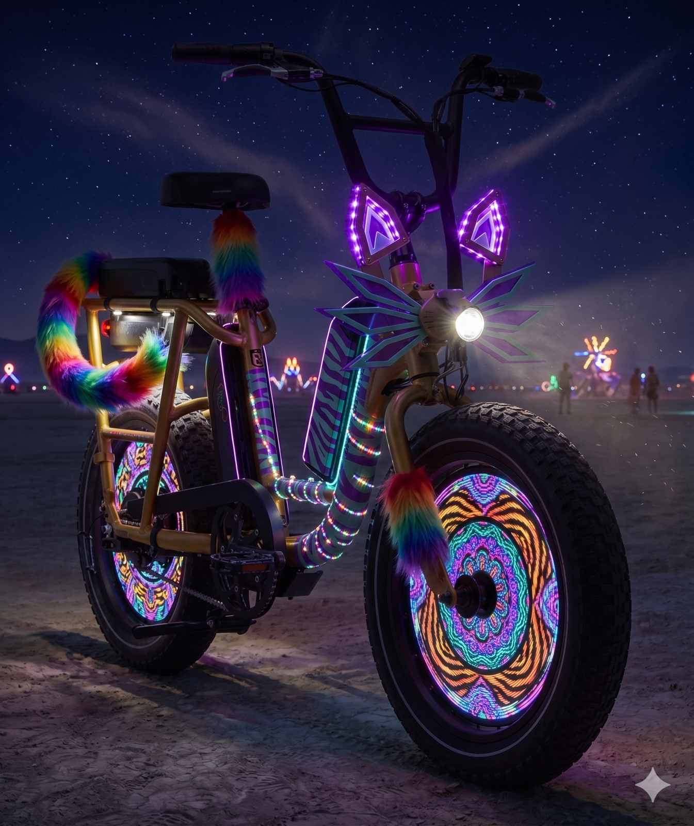
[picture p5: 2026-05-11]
assets/photos/Concepts/Other/Galactic Tiger/Gemini_Generated_Image_89b02b89b02b89b0.png

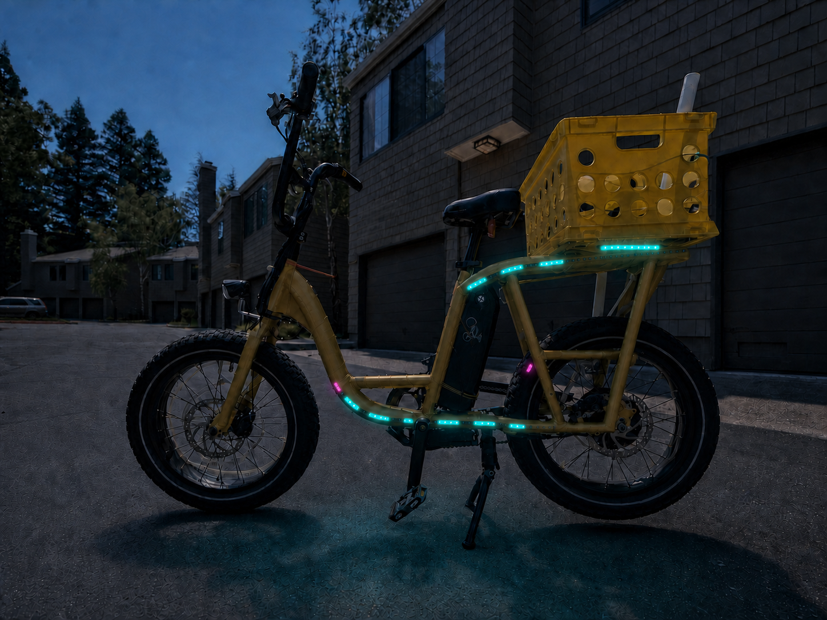
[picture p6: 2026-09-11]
assets/photos/Concepts/Selected/Bio-Luminescent Abyssinian/Phase_1_LED_References/body-strip-design-options-v1/02-bioluminescent-dashes.png

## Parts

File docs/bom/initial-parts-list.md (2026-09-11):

# Initial Parts List

## Purpose

Track candidate parts for the Bio-Luminescent Abyssinian Cat Bike. This is a planning list, not a final purchase list.

## Electronics

| Item | Qty | Status | Notes |
|---|---:|---|---|
| Pixelblaze V3 Pico plus V3 Standard spares | 1 + 2 | Pico in hand; Standards ordered | Use Pico for Phase 1. Universal box fits either model; one central controller and one data output. |
| Cat-head addressable LEDs | 52 | Inventory check | 5 V RGB WS2812/SK6812-compatible: 16 whisker, 8 eye, and 28 facet pixels. Existing parts may be used when protocol and voltage match. |
| 12 V LiFePO4 battery | 1 | Recommended | Baseline: 20 Ah / about 256 Wh. Consider 30 Ah / about 384 Wh if mounting works. |
| 12 V LiFePO4 charger | 1 | Recommended | Use charger intended for 12 V / 4S LiFePO4 batteries, typically 14.4-14.6 V output. 5 A is a practical default for 20 Ah. |
| Magnolora 12 V to 5 V, 3 A converter | 1 controller unit plus spares | In hand | Dedicate one unit to controller power. Do not power 12 V body LEDs through it or parallel converter outputs. Use a separate head converter/branch. |
| Fuse holder and fuses | TBD | Needed | Size after power estimate. |
| Master switch or emergency disconnect | 1 | Needed | Must be reachable. |
| XT60 connector pair | TBD | Needed | Battery/main 12 V connector decision. |
| Cat-head M12 A-coded 4-pin connector pair and cap | 1 set | Selected / buy after coupons | IP67 and at least 4 A/contact; temporary connectors are acceptable for bench work. |
| Wire | TBD | Needed | Gauge depends on current and run length. |
| Heat shrink and sleeving | TBD | Needed | Dust and strain relief. |

## Sculpture and Lighting Materials

| Item | Qty | Status | Notes |
|---|---:|---|---|
| Cat mask/head base | 1 | Needed | Ready-made or fabricated. |
| Copper/rose-gold finish material | TBD | Needed | Paint, film, or metallic panels. |
| Frosted PETG diffuser samples | 1.0 and 1.5 mm | Needed for Gate L1 | Compare sheet and printed samples at 20, 25, and 30 mm setback. |
| Bare 2.0 mm side-emitting PMMA fiber | 9 m | Ordered; due 2026-07-16 | User-confirmed order. Reserve one sacrificial coupon length before cutting fourteen 320 mm development strands. |
| Eight-pixel RGB whisker light engines | 2 | Inventory check | One 5 V WS2812/SK6812-compatible stick per cheek; seven direct-coupled fibers and one masked pixel. |
| Tail structure material | 1 | Needed | Flexible or rigid TBD. |
| Mounting brackets | TBD | Needed | For cat head, tail, controller, battery, LEDs. |

## Cat Head Lighting Prototype

Use existing parts when they meet the listed interface. Record manufacturer,
part number, measured dimensions, and quantity before Gate L1 approval.

| Prototype Item | Qty | Timing | Notes |
|---|---:|---|---|
| Bare 2.0 mm side-glow PMMA fiber | 9 m | Ordered; due 2026-07-16 | Critical-path material secured for the first one-pixel/one-fiber coupon, cheek coupon, final strands, and repair stock. |
| Optional 1.5 mm and 3.0 mm side-glow samples | 1 m each | Optional now | Compare flexibility and brightness without delaying the 2.0 mm baseline. |
| 5 V addressable RGB pixel modules or strip | At least 16 pixels | Verify now | Existing WS2812/SK6812/NeoPixel parts are acceptable for whisker coupons. |
| Dense 5 V RGB eye pixels | 8 pixels | Verify before eye coupon | Four pixels per eye. |
| 5 V RGB facet pixels | 28 pixels | Verify before facet cassettes | Two pixels per approved glow panel. |
| Current-limited 5 V bench supply | 2 A coupon / 5 A full head | Verify now | Temporary USB or bench power is acceptable for the first optical coupon. |
| 1,000 uF capacitor, at least 10 V | 1 plus spare | Before full-head wiring | Install across 5 V and ground at the head entrance. |
| Temporary 3-wire connectors | As needed | Use existing | Bench-only 5 V, ground, and data connections; M12 is not required for Gate L1. |
| Black heat-shrink or opaque coupling tube | Assorted | Before fiber arrives | Blocks light leakage around temporary LED-to-fiber couplers. |
| Fresh razor or POF cutter and fine abrasive | 1 set | Before fiber arrives | Produce square input faces and safely rounded external tips. |
| TPU/silicone grommet and clear tip-cap samples | Assorted | During Gate L1 | Validate port abrasion protection and non-pokey external tips. |
| IP67 M12 A-coded 4-pin connector and cap | 1 set | After optical coupons | Purchase only after confirming cable gauge, routing, and panel-mount geometry. |
## Mechanical and Safety

| Item | Qty | Status | Notes |
|---|---:|---|---|
| Rubber-lined clamps | TBD | Needed | Protect frame paint and reduce vibration. |
| Zip ties or reusable cable ties | TBD | Needed | Use with strain relief. |
| Fasteners | TBD | Needed | Stainless preferred. |
| Safety tether material | TBD | Needed | For cat head and other removable sculpture. |
| Weather/dust enclosure | TBD | Needed | Controller and power distribution. |

## Spares and Repair Kit

| Item | Qty | Status | Notes |
|---|---:|---|---|
| Spare LEDs | TBD | Later | Match final LED type. |
| Spare connectors | TBD | Later | Match final harness. |
| Spare fuses | TBD | Later | Match final fuse rating. |
| Tape and heat shrink | TBD | Later | Field repairs. |
| Small tools | TBD | Later | Bike and electrical repair basics. |

## Decisions Needed Before Purchase

- Final LED type and voltage.
- Dedicated LED battery vs bike battery tap. Decision: dedicated LED battery only; do not touch bike battery.
- Battery type. Recommendation: standalone 12 V LiFePO4, one main battery, 20 Ah baseline or 30 Ah if mounting works.
- Battery/main connector. Decision: XT60.
- Cat-head connector. Decision: IP67 M12 A-coded four-pin, at least 4 A/contact; purchase after optical coupons and routing confirmation.
- Cat head construction method.
- Whisker lighting method. Decision: fourteen individually addressable 2.0 mm side-glow fibers, one pixel per fiber.
- Whether wheel lighting is first phase or deferred.

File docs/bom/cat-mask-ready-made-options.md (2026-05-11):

# Ready-Made Cat Mask Options

Reference list for buying a cat mask instead of fabricating the mask body from scratch. Prices, availability, shipping, and customization options can change; re-check before ordering.

## Shortlist

| Option | Vendor | Approx. price seen | Why it may fit | Fit / integration notes |
| --- | --- | ---: | --- | --- |
| [Hexa Cat Mask - Masquerade Macabre Collection](https://fusionlayer3d.com/products/hexa-cat-mask-masquerade-macabre-collection-3d-printed-geometric-cat-halloween-cosplay-mask-with-glow-sticks-in-3-sizes) | Fusion Layer 3D | $69.99 | Strongest match for a geometric/futuristic cat face. Already includes glow-stick whisker accents, so the shape is LED-friendly. | 3D printed PLA, available in small/medium/large. Confirm face fit, strap/mounting method, and whether glow-stick channels can be reused for LED tubing or fiber optic whiskers. |
| [White Cat Mask / Cosplay Mask for Woman](https://3dplanet-props.com/products/white-cat-mask) | 3D Planet Props | $69.00+ | Full cat-mask silhouette with ears and whiskers; available as raw, finished, or painted variants. | Good candidate if we want a clean base to repaint or add LEDs. Confirm dimensions, finish option, lead time, and whether drilling/modification is acceptable. |
| [Low Poly Mirror Plastic Cat Mask](https://www.etsy.com/listing/1737040361/1-pc-low-poly-mirror-plastic-cat-mask) | MirrorLEDCostumes on Etsy | $300.00 + shipping | Ready-to-wear geometric full-head mask in gold or silver mirror plastic. Strong visual match for a Burning Man night-bike theme without needing paint. | Listed as waterproof, adjustable, and made from two layers of durable plastic. High cost and ships from Ukraine; confirm eye visibility, ventilation, shipping date, return policy, and whether the mirror surface will fight or enhance nearby LEDs. |
| [Low Poly Mirror Plastic Cat Mask with Smart LED](https://www.etsy.com/listing/4368752479/1-pc-low-poly-mirror-plastic-cat-mask) | MirrorLEDCostumes on Etsy | $550.00 + shipping | Same general mirror-cat concept, but with built-in smart LED option. Directly relevant if we want to buy the face effect instead of integrating LEDs ourselves. | Power bank not included. Listed as gold/silver mirror plastic with smart LED, optional mesh, adjustable internal head ring, waterproof plastic, and 3-4 week production. Confirm controller type, LED serviceability, runtime, brightness, power input, and whether the built-in LEDs can sync with the bike system. |
| [Black Leather Cat Mask](https://www.etsy.com/listing/598117531/black-leather-cat-mask-masquerade-mask) | StarSightMasks on Etsy | $32.00 | Lightweight, flexible masquerade-style option with a simple cat profile. | Better as a wearable costume accent than a structural LED mount. Could work if LEDs are mounted on a separate frame or around the bike rather than on the mask. |
| [Handmade Leather Cat Mask](https://www.etsy.com/listing/1567467538/handmade-leather-cat-mask-masquerade) | NeDlyaSkuki on Etsy | $24.00+ | Leather cat mask with color choices; lower-cost ready-made option. | Check shipping timing and actual color/finish. Likely needs a separate rigid backer if attaching electronics. |
| [Handmade Paper Mache Cat Mask](https://www.etsy.com/listing/1008694698/handmade-paper-mache-cat-mask-fantasy) | MacheAnimalMasksFX on Etsy | $38.33+ | More sculptural, theatrical cat face. | Paper mache is easy to modify but less weather/dust resistant. Would need sealing and careful reinforcement for Burning Man use. |
| [Handmade Caracal Cat Mask](https://www.etsy.com/listing/497103221/cat-caracal-cat-mask-neko-animal-costume) | HawkEyeMasks on Etsy | $242.34+ | High-detail animal mask, closer to an art-piece look. | Expensive and likely overkill for a base part, but useful as a visual reference for feline proportions and ears. Confirm fit and customization before considering purchase. |

## Nearby Visual References

These are not cat masks, but the form language, reflective materials, or construction may be useful for the cat-bike direction.

| Option | Vendor | Approx. price seen | Why it may fit | Fit / integration notes |
| --- | --- | ---: | --- | --- |
| [Mirror Husky Mask: 3D Geometric Rave Costume](https://www.etsy.com/listing/1744881588/mirror-husky-mask-3d-geometric-rave) | CraftsByXiaoxiao on Etsy | $253.97 + shipping | Full-head geometric mirror animal mask with a rave/festival visual language close to the project. Useful reference for faceted chrome/gold surface treatment even though it is canine rather than cat. | Custom made; seller requests head circumference, face width, face length, and cutout needs. Listed production is 7-14 days plus 5-7 days shipping within the US. Consider only if the husky/fox silhouette can be acceptable or customized toward feline. |

## Papercraft / Low-Poly Build Leads

These are closer to DIY templates than ready-made purchases. They may still be useful for quick visual prototyping, shape tests, or a low-cost base if we reinforce and seal the finished mask.

| Option | Source | Approx. price seen | Notes |
| --- | --- | ---: | --- |
| [3D Papercraft Cat Mask](https://www.papercraft-3d.com/en/produit/3d-papercraft-cat-mask/) | Papercraft-3D | $8.00 | Original collected link appears to redirect or has moved; current matching listing is a 3D origami cat mask digital kit. Search result describes a 250 mm high x 200 mm wide x 150 mm deep finished mask with 15 pages to assemble. |
| [Papercraft Cat Mask in 3D Origami](https://papercraft-3d.com/en/produit/papercraft-cat-mask-halloween/) | Papercraft-3D | $8.00 | Similar Papercraft-3D cat mask listing. Search result describes a 30 cm tall mask requiring 12 sheets, with digital kit or complete box options. |
| [Cat Mask Digital PDF - Low Poly Papercraft Animal Mask Template](https://www.etsy.com/listing/689042206/cat-mask-digital-pdf-low-poly-papercraft) | IVYpaperArt on Etsy | $5.50 PDF | Instant digital download with 4 PDF files / 16 pages. Requires printer, paper or cardstock, tape/glue, scissors, ruler, and scoring tool. Compatible with A4 and US letter paper; seller recommends 180-200 gsm paper. |
| [Big Cat Low Poly Mask Pattern for Cardboard or EVA Foam](https://www.etsy.com/listing/727280868/big-cat-low-poly-mask-pattern-for) | PaleoPanthera on Etsy | $9.00 PDF | Digital pattern for a low-poly big-cat mask, with printable PDF instructions and at-size pieces. Supports cardboard or EVA foam and includes paw-glove pattern notes. | Personal-use-only listing. Moderately difficult; finished back opening is listed around 7.5-8 inches wide. Needs cardboard or EVA foam, elastic, hot glue/contact cement, and paint. Good candidate for a stronger DIY prototype than paper-only papercraft. |

## STL / Print-Service Leads

These are not ready-to-wear purchases by themselves, but may be useful if we decide to outsource printing instead of modeling from scratch.

| Option | Source | Approx. price seen | Notes |
| --- | --- | ---: | --- |
| [Masquerade Half Cat Mask](https://cults3d.com/en/3d-model/fashion/masquerade-half-cat-mask) | Cults | $1.99 STL | Maine Coon-inspired half-mask STL. Would still need print, finish, straps, and any LED integration. |
| [Cat Masquerade Mask Fantasy 3D Model](https://cults3d.com/en/3d-model/fashion/cat-masquerade-mask-fantasy-3d-model-for-party-cosplay-and-3d-printing) | Cults | $1.67 STL | Fantasy cat mask STL/OBJ. Useful if we want to print locally or send to a print service. |
| [Cat Masquerade Mask - Perihelion Prints](https://3dgo.app/models/cults3d/cat-masquerade-mask-perihelion-prints/) | 3D Go / Cults listing mirror | STL listing | Adult-scaled mask file reference. Verify original source/license before using. |

## Decision Criteria

- **Best buy-first candidate:** Fusion Layer 3D Hexa Cat Mask. It already has a geometric cat shape and glow-accent concept close to the project direction.
- **Best showpiece ready-made option:** MirrorLEDCostumes Low Poly Mirror Plastic Cat Mask, if the budget and shipping risk are acceptable.
- **Best buy-the-LED-effect option:** MirrorLEDCostumes smart LED mirror cat mask, if its controller, runtime, and power setup work with the bike.
- **Best modifiable rigid base:** 3D Planet Props White Cat Mask, especially if the raw or primed option is available.
- **Best cheap shape prototype:** Papercraft PDF options, but only for mockups unless reinforced and sealed.
- **Best stronger DIY template:** PaleoPanthera big-cat low-poly pattern in cardboard or EVA foam.
- **Lowest-cost wearable fallback:** Etsy leather cat masks, but treat them as costume pieces rather than electronics mounting surfaces.
- **Avoid unless intentionally building around it:** paper mache or high-detail art masks, because dust, weather, and repairability may become project risks.

## Questions Before Ordering

- Does the mask fit the rider comfortably with goggles, dust mask, and helmet/hat setup?
- Is there enough rigid surface for LED diffusion, wiring strain relief, and serviceable attachment points?
- Can it survive playa dust, bumps, UV, and transport without cracking or delaminating?
- Are there existing channels, whiskers, holes, or edge features that can hide LED wires?
- What is the real shipping lead time and return policy?

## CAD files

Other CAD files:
hardware/mechanical/fabrication/3d-print/cat-head-full-size-v1/output/10-design-gates/gate7-glow-panel-inserts/small-model-100mm/gate7_grouped_glow_inserts_visual_assembly.stl
hardware/mechanical/fabrication/3d-print/cat-head-full-size-v1/output/10-design-gates/gate7-small-test-print-100mm/cat_head_100mm_visual_assembly.stl
hardware/mechanical/fabrication/3d-print/cat-head-full-size-v1/output/FINAL_PRINT_SET/02-lower-right-connectors/lower-right-connector-integration-v4/LOWER_RIGHT_COMPLETE_OPAQUE_INTEGRATION_PRINT_PART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
hardware/mechanical/fabrication/3d-print/cat-head-full-size-v1/output/FINAL_PRINT_SET/03-lower-left-connectors/left-lower-manual-master-v1/LEFT_LOWER_COMPLETE_OPAQUE_UNION_WITH_CONNECTORS_V1-Compound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

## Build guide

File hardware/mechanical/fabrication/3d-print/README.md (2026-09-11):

# Retained fabrication packages

Use these entries to find the useful prototypes and Burning Man build records.

| Package | Retained milestones |
| --- | --- |
| [Tiny cat-head prototypes](cat-head-tiny-prototypes/README.md) | The 100 mm single shell and 100 mm modular assembly. |
| [Midsize Burning Man head](cat-head-midsize-bm-2026/README.md) | The 190 mm head, eyes, merged mouth, user-edited source, and slicer projects. |
| [Large-head rebuild references](cat-head-full-size-v1/README.md) | V6/V5/V2 working assemblies, selected print records, manual masters and frozen shape references. |
| [Controller V1 printed base](controller-box-v1-printed-base/README.md) | Physically successful base, saved 3MF, and CAD. Its historical generator depends on the user-deleted V0 package. |

The 2026-09-09 cleanup excluded the large-head tree, its rejected-work archive,
metal interfaces, scale projections, whisker carrier, and shared template
inputs. The user later authorized large-head cleanup for a rebuild on 2026-09-10.
Only selected states and shared dependencies remain inside cat-head-full-size-v1;
The separate rejected-work archive and cleanup-recovery folder were subsequently
permanently deleted after the retained work was backed up and independently
download-verified from GitHub. The other excluded packages remain unchanged.

The old `cat-head-small-v1/` directory contains compatibility links. All
`reports/` contents and its four aliases were retired on 2026-09-10.
Midsize contracts now use the retained package directly. Original generator
authorization pins intentionally fail closed after those path-only edits;
regeneration needs a fresh authorized preflight and reviewed pin update.

Cleanup details, verified backup and preserved inventories are in
[the cleanup record](../../../../docs/PROJECT_CLEANUP_PLAN.md).

The user deleted controller-box-v0 and controller-box-v1-complete-enclosure-proposal
on 2026-09-10. They were not restored. The printed base was renamed without
changing its CAD or slicer bytes; original internal filenames remain historical.

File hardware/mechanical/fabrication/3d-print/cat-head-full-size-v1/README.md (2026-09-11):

# Large head — rebuild references

Cleaned on 2026-09-10 at the user's request: the large head will be rebuilt.
Only selected working states, physical-print records, frozen shape references,
and shared/tested tooling remain. Retention is not approval to print or a choice
of the next canonical CAD baseline. No geometry was opened, resaved, or regenerated.

## Start here

| Need | Retained files |
| --- | --- |
| Latest documented working snapshot | [Working assembly V6](output/70-freecad-pilots/opposite-side-flange-pilot-v1/right-upper-as-printed-working-assembly-v1/RIGHT_UPPER_AS_PRINTED_WORKING_ASSEMBLY_V6.FCStd) |
| Missing-socket recovery source | [Working assembly V5](output/70-freecad-pilots/opposite-side-flange-pilot-v1/right-upper-as-printed-working-assembly-v1/RIGHT_UPPER_AS_PRINTED_WORKING_ASSEMBLY_V5.FCStd) |
| Editable source for selected lower prints | [Working assembly V2](output/70-freecad-pilots/opposite-side-flange-pilot-v1/right-upper-as-printed-working-assembly-v1/RIGHT_UPPER_AS_PRINTED_WORKING_ASSEMBLY_V2.FCStd) |
| Selected left/right lower STL and 3MF packages | [Working print records](working/README.md) |
| Eye release and manual lower masters | [Selected print set](output/FINAL_PRINT_SET/README.md) |
| Separate manual lower-front states and sector recovery | [User-edited lower-front files](output/70-freecad-pilots/review-only/lower-front-bilateral-feedback-cleanup-review-v4/) |
| Latest right-upper slicer setup | [10 mm brim layout](output/50-slicer-projects/right-upper-as-printed-10mm-brim-layout-v1/README.md) |
| Frozen original whole-head visual reference | [Blender V10](output/00-current-review/ear-root-marked-relocation-m3-through-bolt-review-v10.blend) |
| Accepted fit-body reference | [Ear fit V3](output/60-ear-root-reviews/ear-root-insertion-fit-review-v3/ear-root-insertion-fit-review-v3.blend) |
| Rear-cassette ownership reference | [Rear cassette V5](output/20-rear-cassette/current-baseline-v5/rear-cassette-lossless-repartition-review-v5.blend) |
| Earlier frozen recovery context | [FreeCAD V34](output/70-freecad-pilots/opposite-side-flange-pilot-v1/right-upper-c009-deletion-review-v34/CAT_HEAD_RIGHT_UPPER_C009_DELETION_REVIEW_V34.FCStd) |

Original filenames and retained output paths are intentional: shared inputs,
existing contracts and tiny/midsize links depend on them. The old review trees
are not being retained as another active archive.

## Rebuild cautions

- V6 is unfinished working CAD, not a print-ready whole head. V5 is important
  because a prior V6 cleanup lost the right socket/root; see the
  [recovery checkpoint](REAR_INTERFACE_V06_V8_RIGHT_SOCKET_RECOVERY_CHECKPOINT_2026-08-23.md).
- RIGHT_TOP_PRINT.3mf was the stopped missing-socket trial and has been retired.
  RIGHT_TOP_PRINT_2.3mf and assembly.3mf remain as user records with unconfirmed status.
- The selected lower meshes retain their recorded multi-shell and slicer-repair
  limitations. Do not infer structural validation from a saved STL or 3MF.
- Reuse the measured fit feedback and aluminum interface records; do not
  reconstruct a new baseline by mixing objects from these historical versions.

## Shared dependencies and backup

Gate 1–7 inputs and the modular 100 mm prototype remain under output/10-design-gates/
because the separate [tiny prototype package](../cat-head-tiny-prototypes/README.md)
uses them. Final midsize Rev112/113 tooling and its runtime manifest remain at
their pinned paths. Existing generation holds were not changed or bypassed.

One-off scripts/configs, intermediate reviews, caches, backups, rejected print
versions and trial G-code were retired; their local recovery archives were later
permanently deleted after independent GitHub download verification of retained
work. Only the inventories remain. Remaining source includes reusable checks and
code still read by existing tests; old generators may require unavailable inputs
and are not a supported one-command rebuild pipeline. Do not bypass their guards.

See [the checkpoint](REBUILD_CHECKPOINT_2026-09-10.md),
[retained geometry hashes](RETAINED_FILES.json), and
[project cleanup record](../../../../../docs/PROJECT_CLEANUP_PLAN.md).

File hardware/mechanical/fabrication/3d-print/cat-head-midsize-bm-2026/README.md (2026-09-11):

# Midsize cat head — Burning Man 2026

The user confirmed that this midsize head was printed for Burning Man. The
saved CAD is 190 mm tall. The saved pane project combines Rev112 eyes with the
Rev113 one-piece mouth.

## Current build files

| Purpose | Location |
| --- | --- |
| Head CAD, head/eye STLs, and head slicer projects | [Head Rev112](releases/head-rev112/) |
| CAD with the merged mouth, mouth STL, and its validation | [Mouth Rev113](releases/mouth-rev113/) |
| Combined eye and mouth slicer project | [Eyes_and_Mouth.3mf](releases/head-rev112/Eyes_and_Mouth.3mf) |
| User-edited source CAD and earlier manual inputs | [User final edits](source/user-final-edits/) |
| Original release manifest | [Rev112 manifest](releases/final-mvp-v2/release-manifest.json) |

The head folder contains both `CAT_HEAD_MEDIUM_ILYA_FINAL_HEAD_CUT_HOLES_REV112.3mf`
and `CAT_HEAD_MEDIUM_ILYA_FINAL_HEAD_CUT_HOLES_REV112_Build_plateOnly.3mf`.
They differ in support, perimeter, and infill settings; both are retained because
the exact job used for the physical print has not yet been identified.

Rev113's head and eye STL filenames link to the byte-identical Rev112 exports.
The original two mouth-pane STLs remain with Rev112 because its validator uses
them. The one-piece mouth is
`releases/mouth-rev113/CAT_HEAD_MEDIUM_MERGED_MOUTH_TRANSLUCENT_PANE_REV113.stl`.
The separate `REVIEW_ONLY__MOUTH_CENTER_SEAM_BRIDGE_REV113.stl` is validation
evidence and is not an assembly part.

## Source, validation, and regeneration

The final user-edited input is
`source/user-final-edits/CAT_HEAD_MEDIUM_Ilya_FINAL_EDITS.FCStd`.
Keep it with the final CAD and exports. The older `Final MVP.3mf`, `HEAD.stl`,
and `Cutter1.stl` beside it are preserved manual inputs.

[Head tooling](tooling/head-rev112/) and [mouth tooling](tooling/mouth-rev113/)
link to the original pinned scripts inside the excluded large-head directory.
Geometry, construction code, preflight reports in `validation/`, and the shared
FreeCAD runtime manifest retain their original bytes and hashes. Contracts in
`config/v2/` received filesystem-path-only edits on 2026-09-10. Their byte
hashes changed; original preflight evidence and authorization pins did not.

Historical generation/validation commands and fit observations remain in
the [head checkpoint](releases/head-rev112/CHECKPOINT.md) and
[mouth checkpoint](releases/mouth-rev113/CHECKPOINT.md). The one-shot generators
refuse existing output directories; no generator was run during cleanup.

Run the off-device final contract checks from the repository root:

```bash
PYTHONDONTWRITEBYTECODE=1 python3 -m unittest tests.automated.test_small_v1_final_user_cutter_holes_rev112_contract tests.automated.test_small_v1_merged_mouth_pane_rev113_contract
```

Legacy review links outside `reports/` remain. The reports folder is empty,
with no aliases; contracts and the evidence renderer use this package directly.

Generation hold: both one-shot wrappers intentionally reject their changed
contract hashes before generation. A fresh authorized no-output preflight and
reviewed pin update are required before regeneration. Do not rewrite old PASS
records or overwrite retained release folders. Design values, source geometry,
and historical release flags are unchanged.

Next physical documentation: identify the head slicer profile actually used
and record pane fit, mounting behavior, and Burning Man wear or failures.

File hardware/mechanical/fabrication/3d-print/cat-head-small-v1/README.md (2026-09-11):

# Legacy small-head paths

The retained models now have separate entry points:

- [Tiny prototypes: single shell and modular, both 100 mm](../cat-head-tiny-prototypes/README.md).
- [Midsize Burning Man head, 190 mm](../cat-head-midsize-bm-2026/README.md).

This directory contains compatibility links for the original generator,
contracts, release manifest, and final review paths. Keep these links while
the existing pinned tools use the old paths.

Superseded iterations are recoverable through
[the cleanup record](../../../../../docs/PROJECT_CLEANUP_PLAN.md).

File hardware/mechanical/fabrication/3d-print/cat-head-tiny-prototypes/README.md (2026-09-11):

# Tiny cat-head prototypes

Both 100 mm versions are retained as useful design milestones.

| Prototype | Files |
| --- | --- |
| [Single shell](single-shell-100mm/README.md) | One hollow shell, Blender model, STL/OBJ, validation, previews, and two saved print jobs. |
| [Modular assembly](modular-100mm/) | Twenty separate shell, glow-insert, and eye-module parts, a Blender assembly, and three slicer projects. |

The modular entry links to the original Gate 7 package inside the large-head
tree. Its files and dependencies were left in place for the separate large-head
review. [Assembly and regeneration notes](../cat-head-full-size-v1/GATE7_SMALL_TEST_PRINT.md)
describe the seven shell parts, seven glow inserts, and six eye-module parts.

The larger head printed for Burning Man is documented separately in
[the midsize package](../cat-head-midsize-bm-2026/README.md).

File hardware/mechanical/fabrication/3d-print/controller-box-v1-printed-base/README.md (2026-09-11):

# Controller Box V1 — Printed Base

This base was physically approved and printed successfully on 2026-08-18,
as recorded in [its checkpoint](V1_PROPOSAL_CHECKPOINT.md). Keep the saved
print project in `output/Printing/`.

The user deleted the V0 and complete-enclosure proposal folders on 2026-09-10.
This package was renamed from controller-box-v1-flat-base-proposal to
controller-box-v1-printed-base. All CAD, slicer, configuration and generator
files retain their original bytes and historical filenames.

The saved [successful print project](output/Printing/controller-box-v1-flat-base-proposal-PROPOSED__FlatBottomBase.3mf)
and [FreeCAD model](output/controller-box-v1-flat-base-proposal.FCStd) are intact.
The historical generator still requires V0 source, configuration and base STL;
regeneration is unavailable until those dependencies are explicitly recovered.
The cleanup did not restore the folders you deleted.

The printed revision changed only the base and mounting-ear edge construction:

- flat bed datum at Z = 0;
- zero bottom-edge bevel;
- 4 mm XY-only base corner radius;
- 2 mm XY-only mounting-ear corner radius;
- unchanged 132 x 92 x 42 mm enclosure envelope;
- unchanged 132 x 116 mm maximum footprint, mounting slots, wall, floor,
  bosses, connector opening, and lid interface.

Retained build files are under `output/`. No CAD or slicer was run during cleanup.

Historical regeneration command (requires the missing V0 dependencies):

```bash
blender --background --python hardware/mechanical/fabrication/3d-print/controller-box-v1-printed-base/source/generate_controller_box_v1_flat_base_proposal.py
```

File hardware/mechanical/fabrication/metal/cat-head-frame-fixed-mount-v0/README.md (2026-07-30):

# Cat head frame-fixed aluminum mount V0.5

Status: **V0.5-M2 coordinated bottom-center aluminum handoff generated; not released for metal fabrication, final ASA printing, or riding**.

## Current V0.5-M2 handoff

V0.5 retains the accepted rail axes, X `+/-40` lower targets, socket roll, 21 mm
straight socket opening, 1 mm lead-in, 30 mm insertion depth, M4 upper
retention, plate outline, adapter holes, and six angle-base M5 centers. Only
the two bottom shell M5 centers move from X `+/-10` to X `+/-7.4` at V `-30`;
the top and middle shell centers remain unchanged. V0.5-M2 retains the hand-fabricated architecture that superseded the CNC-only M1 shoes, using parts that can be hand-cut
from the user's ordered Randall Manufacturing 6063-T6 equal angle:

- Ordered stock is nominally `38.1 x 38.1 x 3.175 mm`, 914.4 mm long. It is
  ordered but not received or dimensionally verified.
- Per rail: one 45 mm primary angle with its base trimmed to 29 mm, one
  `45 x 25 x 3.175 mm` outer cheek cut from a second segment, two fitted metal
  taper pads, one fitted 14.7 mm nominal solid plug, and two M5 x 40
  crossbolts.
- The compound-cut rail and plug bear directly on the 3.175 mm angle base,
  which bears on the 3 mm 6061 backplate. The rail is not suspended from the
  upright leg.
- Rail centerline length is `152.476123 +/-0.25 mm` (shop callout 152.5 mm),
  with a 160 mm rough cut. Compound finished edges range from 147.0677 to
  157.8845 mm.
- Lower M5 stations are 14 and 29 mm from the bearing-plane centerline. Upper
  M4 is 133.776123 mm from that datum and 18.7 mm from the square upper end.
- Three flush M5 x 16 through-bolts attach each angle base at the retained
  plate centers. Clamp the primary angle to the drilled plate and transfer the
  holes; do not lay them out from an arbitrary angle edge.
- The complete angle/spacer/rail/plug/cheek stack is transfer-drilled. Two
  hand-fit aluminum taper pads and matching metal head seats compensate the
  4.8178 degree roll mismatch between the stock 90-degree angle and the frozen
  rail crossbolt axis.
- There is no backplate rail cutout or exterior shell pass-through. Service is
  through the open rear aperture.
- The shell consumer uses `14 x 36 x 12 mm` bottom ASA pads. Metal margins are
  7.0819 mm hole-to-edge, 4.8319 mm washer-to-edge, 2.8319 mm tool-to-edge,
  0.8 mm opposing-tool gap, and 7.3963 mm tool-to-adapter-hole clearance.

All V0.5 metal geometry, compound-cut, plate-edge, hole-ligament, sequential tool-access, stock, socket, and current V6.1 collision-matrix checks pass. The coordinated bottom pads pass, but the full V7 shell candidate remains held on the tracked non-bottom tool/service/cap/validator issues. This is not permission to cut the plate or final brackets.

Current sources and tracked summary:

- `config/frame-fixed-mount-v05-final.json`
- `source/generate_frame_fixed_mount_v05.py`
- `review/frame-fixed-mount-v05-final-summary.json`
- `hardware/mechanical/interfaces/cat-head-shell-aluminum-interface-v05.json`
- `V05_M2_COORDINATED_BOTTOM_M5_CHECKPOINT_2026-07-29.md`

Generated review outputs live under `output/v05-m2-coordinated-centers/` and include
the backplate DXF/SVG, rail cut/drill drawing, four-face compound wrap
template, angle/cheek plan, BLEND, five renders, and validation JSON. They are
reproducible local review artifacts and remain ignored by Git.

Run from the repository root:

```bash
python3 hardware/mechanical/fabrication/metal/cat-head-frame-fixed-mount-v0/source/prepare_frame_fixed_mount_v05_interface.py

blender --background hardware/mechanical/fabrication/3d-print/cat-head-full-size-v1/output/gate9-socket-portals-candidate-v6/gate9-socket-portals-candidate-v6.blend \
  --python hardware/mechanical/fabrication/metal/cat-head-frame-fixed-mount-v0/source/generate_frame_fixed_mount_v05.py

python3 -m unittest \
  tests.automated.test_cat_head_shared_interface \
  tests.automated.test_gate9_socket_portals_v6_summary
```

## V0.2 architecture history

The remainder of this document preserves the V0.2 concept history. Statements that its lower shoes, rail lengths, or backplate holes are deferred are superseded by the V0.5-M2 handoff above; the physical fabrication and riding gates are not superseded.

This is the no-weld connector between the four RadRunner 2 head-tube bosses
and the 330 mm Gate8 cat head. The head stays fixed to the bicycle frame while
the fork, handlebar, and existing headlight steer below it.

## Corrected architecture

The earlier V0.1 concept incorrectly continued the aluminum rails through the
exterior plastic shell. Gate8 has blind sockets inside the upper shells, not
exterior portals. V0.2 separates the two systems at a removable aluminum rear
backplate:

1. A 4.75 mm 6061 rear plate bears on all four factory bosses.
2. Two formed 3.18 mm 5052 side webs place a compact adapter 60 mm forward and
   75 mm above the boss-pattern center.
3. The 90 x 80 x 4.75 mm 6061 adapter bolts to a 3 mm 6061 trapezoidal
   backplate fitted to the head rear service plane.
4. Inside the head, two independent 19.05 mm square rails start at mirrored
   machined lower shoes and end in the blind integral upper-shell sockets.
5. Each upper socket retains its rail with one transverse M4 bolt. The planned
   lower shoe uses a solid plug and two M5 cross-bolts; its exact geometry is
   intentionally deferred.
6. A separate metal safety tether connects the bike-side rear plate to the
   frame.

There is no weld and no printed polymer in the bike-connector primary load
path. The printed socket shells still require physical coupon and load testing.

## Selected dimensions

| Feature | V0.2 value |
| --- | ---: |
| Factory boss pattern | 30 mm horizontal x 90 mm vertical, center-to-center |
| Boss face diameter | 18 mm |
| Existing blank bolt under-head length | 14 mm; thread and blind depth unverified |
| Rear boss plate | 60 x 115 x 4.75 mm 6061-T6 |
| Rear frame holes | 4 x 6.6 mm at X +/-15, Z +/-45 mm |
| Twin side-web centerline | 60 mm forward, 75 mm upward, 96.047 mm long |
| Side webs | 3.18 mm 5052-H32, 64 mm bend-line height, 15 mm end flanges |
| Compact bike adapter | 90 x 80 x 4.75 mm 6061-T6 |
| Adapter to backplate | 4 x 6.6 mm at X +/-22, V +/-20 mm |
| Head rear backplate | trapezoid, 60 mm top, 120 mm bottom, 79.664 mm high, 3 mm 6061 |
| Rear-plane mating pitch | -18.894665 degrees relative to estimated boss plane |
| Internal rails | nominal 19.05 mm square aluminum tube |
| Modeled rail reference length | 158.172 mm; not a final cut length |

## Portal angle verification

The visible socket angle was genuinely wrong in V0.1. The old straight axes
missed the rear backplate plane by 14.179 mm and rolled the M4 cross-bolt axes
54.831 degrees away from head-horizontal.

The revised Gate8 sockets and rails use a full compound orientation:

| Quantity | Revised value |
| --- | ---: |
| Lower rail targets in head coordinates | X +/-40, Y 267.336, Z 147.132 mm |
| Height above rear-plane lower edge | 15 mm |
| Rail pitch above head-forward | 17.662 degrees |
| Rail yaw away from centerline | 5.595 degrees |
| M4 axis deviation from head-horizontal | 5.333 degrees |
| Minimum socket recess behind exterior plane | 8.205 mm |

Socket roll is defined by head X projected perpendicular to each rail axis.
This makes the M4 paths nearly horizontal while preserving socket recess and
shell integration. There are no new exterior openings.

## Fabrication and review files

The rear boss plate and compact bike adapter profiles are suitable for 1:1
paper checking and quote discussion:

- `output/flat-plates/rear-boss-plate.dxf`
- `output/flat-plates/rear-boss-plate-1to1.svg`
- `output/flat-plates/bike-adapter-plate.dxf`
- `output/flat-plates/bike-adapter-plate-1to1.svg`

These remain **review-only** and must not be sent for cutting yet:

- `output/flat-plates/head-rear-backplate-review-only.dxf`
- `output/flat-plates/head-rear-backplate-review-only.svg`
- `output/formed-parts/lower-rail-shoe-concept-review.svg`

The backplate perimeter holes, rail-shoe holes, rear-base pass-throughs, and
machined shoe dimensions are not defined. The side-web drawing specifies formed
geometry only; the selected shop must calculate bend allowance for its tooling:

- `output/formed-parts/side-web-formed-drawing.svg`

Review assets:

- `output/review-model/frame-fixed-mount-v02-review.blend`
- `output/review-model/frame-fixed-mount-v02-review.glb`
- `output/renders/v02-assembly-front-oblique.png`
- `output/renders/v02-assembly-side.png`
- `output/renders/v02-rear-backplate-handoff.png`
- `output/renders/v02-internal-rails.png`
- `output/review-drawings/v02-side-integration-review.svg`
- `output/validation/frame-fixed-mount-v02-validation.json`

## Headlight and steering status

The user confirmed that handlebar turning does not enter the four-boss
connector area. The existing fork-mounted headlight remains.

The reported 60 mm distance from the upper boss center to the top of the light
is only a vertical datum. The actual 330 mm Gate8 shell overlaps that elevation
in side projection, so the former 30.02 mm clearance claim is invalid. Housing
and beam clearance cannot be approved until the real lamp position and size are
added to the 3D model or checked with an accurate full-size mockup through the
complete steering sweep.

## Provisional hardware

- Four frame M6 bolts; length is not released. Verify thread pitch, blind depth,
  factory engagement, washer stack, and non-bottoming first.
- Eight M5 bolts, washers, and locknuts for the two formed side webs.
- Four M6 bolts, washers, and locknuts for the removable adapter/backplate
  interface.
- One M4 transverse bolt per upper printed socket.
- Lower rail-shoe, solid-plug, cross-bolt, and backplate-perimeter hardware are
  not released.
- One independent metal safety tether and positive-lock attachment hardware.

Use verified torque guidance for the selected fastener grade and interface.
Control stainless-on-aluminum galling and galvanic corrosion with an appropriate
assembly compound or isolation system.

## Release gates

Before metal ordering:

1. Print the boss and adapter SVGs at 100 percent and verify a ruler scale.
2. Confirm all four boss centers, complete 18 mm boss-face support, plate
   flatness, cables, M6 pitch, and every blind-hole depth.
3. Print the revised integrated socket coupon and test the actual square tube,
   M4 drilling, socket bridge, fit, and rattle.
4. Design and coupon-test the rear-base pass-through, mirrored lower shoes,
   backplate perimeter fasteners, drainage, and wiring route.
5. Put the actual lamp housing and Gate8 head into one full-size 3D or cardboard
   mockup. Check the complete steering sweep, beam, rider sightline, cables, and
   control access.
6. Have the fabricator return bend radii, deductions, material, and drawings for
   approval before cutting the 5052 webs.

Before riding, install the safety tether and proof-load the complete stationary
assembly in forward, rearward, up, down, and torsional directions to the greater
of 60 N or five times installed head weight. Follow with vibration testing and
progressive low-speed rides away from traffic. Stop for slip, noise, fretting,
cracks, permanent bend, cable contact, steering interference, or beam blockage.

## Regeneration

From this directory:

```bash
blender --background --python source/generate_frame_fixed_mount_v0.py
```

The authoritative inputs are `config/frame-fixed-mount-v0.json` and
`source/generate_frame_fixed_mount_v0.py`.

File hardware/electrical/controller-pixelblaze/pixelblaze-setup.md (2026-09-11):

# Pixelblaze Setup

## Purpose

Define the draft Pixelblaze controller setup for the Cat Bike LED installation.

## Current Decisions

- Use the in-hand Pixelblaze V3 Pico as the Phase 1 controller.
- Keep the ordered Pixelblaze V3 Standard boards as hot spares/future upgrades.
- Do not use multiple controllers for this bike unless future complexity forces it.
- Mount the controller near the battery/power distribution enclosure, protected from dust, moisture, vibration, and cargo impacts.
- Use one data output initially.
- Keep the Pixelblaze Output Expander available as a future option, but do not include it in Phase 1.
- Power either controller from one dedicated Magnolora 12 V to 5 V, 3 A converter.
- Reserve a Standard-sized tray area; the insulated Pico may lie loose for the MVP.
- Keep all LED load current out of the Pixelblaze power path.

## Physical Location

Preferred controller location:

- In or near the rear power distribution area.
- Protected enclosure near the under-rack / behind-seat / basket-area power box.
- Close to the protected 12 V distribution and dedicated 5 V controller converter.
- Accessible enough for service, reset, and Wi-Fi setup.

Avoid:

- Front/head tube area as the main controller location.
- Exposed mounting on the frame.
- Locations that block battery removal, rider movement, cargo use, or future tail/head mounting.

## Segment Concept

Pixelblaze sees LEDs as one indexed pixel chain:

```text
pixel 0, pixel 1, pixel 2, ... pixel N
```

A segment map documents which index ranges correspond to physical bike zones.

Example:

```text
pixels 0-89    = lower frame spine
pixels 90-129  = fork accents
pixels 130-199 = rear rack/basket
```

This allows patterns to treat physical zones differently even when the LEDs are wired as one data chain.

## Initial Output Strategy

Use one Pixelblaze data output for Phase 1.

Initial physical data order can be chosen for clean wiring, not visual order. For example:

```text
Pixelblaze data out
  -> rear rack/basket
  -> lower frame spine
  -> fork/front accents
```

The final order must be documented in the LED segment map before writing zone-specific patterns.

## Draft Logical Segments

| Segment | Physical Zone | Phase | Status |
|---|---|---|---|
| S0 | Lower frame segmented spine | Phase 1 | Draft |
| S1 | Fork gill accents | Phase 1 | Draft |
| S2 | Rear rack rib accents | Phase 1 | Draft |
| S3 | Basket underside glow | Phase 1 | Draft |
| S4 | Ground underglow | Phase 1 | Draft |
| S5 | 52-pixel cat head: whiskers, eyes, and fourteen glow facets | Phase 2A | Local map locked; absolute offset pending |
| S6 | Tail | Phase 2B | Reserved |
| S7 | Body panels | Phase 3 | Reserved |
| S8 | Optional wheels | Phase 4 | Deferred |

## Output Expander

An output expander is available in-house, but it is not part of the Phase 1 plan.

Use it later only if:

- The physical data wiring becomes awkward with one output.
- Body panels need separate data paths.
- A measured full-harness test shows that the terminating 52-pixel cat head cannot run reliably on the initial output.
- Refresh rate or pixel count becomes a real limitation.

## Mode Plan

| Mode | Intent | Brightness Cap |
|---|---|---:|
| Riding | Clear visibility with restrained motion | 25-35% |
| Parked/show | Brighter bioluminescent effects | 50-60% |
| Low-power reserve | End-of-night safe visibility | 10-15% |

## Open Items

- Identify the Pico antenna end and insulate the board without covering it.
- Measure a Standard board when it arrives and finalize its interchangeable carrier.
- Configure the Pico and verify the dedicated 5 V controller power connector polarity.
- Assign the absolute S5 start offset after preceding whole-bike zones are measured.
- Integrate the locked head-local 0-51 map into the whole-bike segment map.
- Bench test current draw and brightness caps before bike installation.

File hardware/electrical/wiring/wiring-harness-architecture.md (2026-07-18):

# Wiring Harness Architecture

## Purpose

Define the draft power and data wiring architecture for the Cat Bike LED installation. This is a planning document; final wire gauges and fuse ratings must be verified against actual parts, measured current, and physical routing.

## Current Electrical Decisions

- LED system uses a dedicated battery only; do not tap the bike battery.
- Primary LED system is 5 V addressable RGB LEDs.
- Battery chemistry target is standalone 12 V LiFePO4.
- Battery/main 12 V connector is XT60.
- Preferred converter is a 12 V to 5 V buck converter, 5 V 30 A class if quality and mounting are acceptable.
- Use fused 5 V branch distribution.
- Use removable connectors for serviceable LED zones.

## System Flow

```text
12 V LiFePO4 battery
  -> XT60 connector
  -> main fuse near battery
  -> master switch / emergency disconnect
  -> 12 V to 5 V buck converter
  -> fused 5 V distribution
  -> removable LED branch connectors
  -> LED zones
```

Keep the 12 V section short where practical. Put the buck converter near the distribution enclosure, not at a random LED zone.

## Draft Wire Gauges

| Run | Tentative Wire Gauge | Notes |
|---|---:|---|
| Battery to main fuse / switch / converter input | 12-14 AWG | Size for converter input current and main fuse. |
| Converter 5 V output to distribution block | 12-14 AWG | Higher current than 12 V side; keep short. |
| Lower frame branch | 16-18 AWG | Final choice depends on measured length/current. |
| Fork/front branch | 18 AWG | Modest current; keep protected around steering/fork movement. |
| Rear rack/basket branch | 16-18 AWG | May carry multiple rack/basket zones. |
| Cat head branch | 18 AWG | Locked 52-pixel, 3.12 A maximum load on a 4 A fused branch. |
| Tail reserved branch | 18 AWG | Future removable tail. |
| Body panel reserved branch | 16-18 AWG | Final choice depends on panel pixel count. |
| Data lines | 22-26 AWG typical | Route with ground; avoid long noisy runs without planning. |

Fuses protect wires. Final fuse values must match actual wire gauge and branch load.

## Branch Layout

| Branch ID | Branch | Phase | Power | Data | Notes |
|---|---|---|---|---|---|
| B1 | Lower frame spine | Phase 1 | Active | Active | Main visual Phase 1 branch. |
| B2 | Fork/front | Phase 1 + Phase 2A reserve | Active / reserved | Active / reserved | Fork accents now; cat head interface later. |
| B3 | Rear rack/basket | Phase 1 | Active | Active | Rack rib accents and basket underside glow. |
| B4 | Cat head | Phase 2A | 5 V / 4 A fused | S5 terminating range | M12 four-pin removable interface; head-local indices 0-51. |
| B5 | Tail reserved | Phase 2B | Reserved | Reserved | Removable tail connector near rear rack/basket. |
| B6 | Body panels reserved | Phase 3 | Reserved | Reserved | Capped branch connector near future panel zones. |

## Power Injection Policy

- Inject power at the start of each active branch.
- Inject at both ends for longer or higher-current LED runs.
- Do not rely on LED strip copper as the only long power path.
- Keep power and ground paired physically where practical.
- Share a solid ground reference between Pixelblaze/data and LED power.
- Use brightness limits in Pixelblaze so normal current remains below fuse and converter limits.

## Connector Policy

- XT60 for battery/main 12 V connection.
- Candidate removable LED branch connectors:
  - 3-pin 18 AWG waterproof LED pigtails for normal modest-current branches.
  - IP67 M12 A-coded four-pin connector, at least 4 A/contact, for the cat head.
- Avoid exposed JST-SM connectors on the final bike.
- Use capped connectors for reserved future branches.
- Add strain relief at every removable connector.

## Open Checks

- Measure actual under-rack and behind-seat mounting space.
- Choose exact battery size and physical battery dimensions.
- Choose exact converter model and enclosure.
- Record the purchased cat-head M12 part number and choose connector families for remaining removable zones.
- Confirm wire routing paths on the physical bike.
- Measure actual current draw during bench testing.

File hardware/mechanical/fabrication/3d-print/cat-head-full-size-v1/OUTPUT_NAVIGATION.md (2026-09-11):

# Large-head output navigation

The historical chronological ledger was retired on 2026-09-10. Its local recovery
archive has since been permanently deleted. Old entries labelled Current are not
live instructions; use this curated index and the verified retained-file backup.

- [Selected working states and frozen references](README.md).
- [Lower-shell working print files](working/README.md).
- [Eye release and manual lower masters](output/FINAL_PRINT_SET/README.md).
- [Rebuild checkpoint and verification](REBUILD_CHECKPOINT_2026-09-10.md).
- [Immutable retained geometry hashes](RETAINED_FILES.json).

The large head is to be rebuilt. No new canonical baseline or whole-head print
release was selected by this filesystem cleanup. Read AGENTS.md and the CAD
change-control workflow before any geometry work.

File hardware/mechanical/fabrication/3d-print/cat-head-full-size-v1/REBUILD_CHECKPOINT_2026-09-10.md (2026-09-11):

# Large-head rebuild checkpoint — 2026-09-10

Subsequent archive retirement: both _archive_admin/ and .cleanup-recovery/ were
permanently deleted. Retained tracked files were independently downloaded from
GitHub and hash-verified before the final recovery deletion. Current proof is in
[the retirement record](../../../../../docs/cleanup/2026-09-10/README.md).
The cleanup verifiers below describe earlier snapshots and are not current
whole-repository verification commands after that later deletion.

The user authorized maximum large-head cleanup because it will be rebuilt.
This was filesystem cleanup only. No CAD, geometry generation, rendering,
slicing, geometry dimensions, contract pins or print approvals changed.

## Retained state

Use [the rebuild index](README.md) and [167 geometry hashes](RETAINED_FILES.json).
V6 is the latest documented working snapshot; V5 is missing-socket recovery;
V2 is the editable lower-print source. Manual lower-front states/masters, the
bilateral V3 eye release, V34/V10 context, accepted ear-fit V3 and rear-cassette
V5 remain. None collectively establishes a new baseline or whole-head release.

The tiny modular 100 mm package and its Gate 1–7 inputs remain. Final midsize
Rev112/113 tooling and its existing fail-closed guards are unchanged.
Lower-print voxel size remains 0.25 mm, with 27 right and 16 left connected
shells; the old right slicer handoff reported eight auto-repaired errors.
No new structural or physical validation was performed.

## Removed history — recovery subsequently deleted

Removed 2,956 obsolete files/links: old review trees, staging, caches, backups,
unnamed copies, withheld lower V1–V3 prints, trial G-code and one-off tooling.
Active disk usage fell from 2.2 GiB to about 506 MiB, roughly 77%.
Assets, templates, electrical/lighting files, sibling CAD packages and the
separate historical _archive_admin tree were not pruned.

RIGHT_TOP_PRINT.3mf was the stopped missing-socket trial: do not resume it.
RIGHT_TOP_PRINT_2.3mf and assembly.3mf are user records with unconfirmed print
status. Existing output names and validation files do not approve later edits.

The former large-head recovery archive (1,392,631,518 bytes) was permanently
deleted after verifying the retained-file GitHub backup. It is no longer a
restore source. Its original manifest is preserved byte-for-byte as
docs/cleanup/2026-09-10/large-head-manifest.json at repository root, alongside
the final retirement proof. Inventories cannot recreate deleted geometry.

## Verification

- 2,179 protected original repository files/links unchanged; all retired paths absent.
- Broad suite: 372 tests; identical 10 failures, 13 errors and 36 skips before/after.
  Failing test IDs, error types and persistent large-head inputs read match.
- Existing failures include stale/rejected CAD contracts, retired report fixtures,
  two missing-FreeCAD imports, and the old lighting-map test expecting glow_pairs.
  No contracts, validation pins or safety guards were changed to mask failures.
- The 17 final-head/tooling tests pass. Mapper and all 10 lighting patterns pass.

Retained-file checks from repository root:

```bash
git lfs pull
git lfs fsck --dry-run HEAD
env -u CAT_HEAD_FREECAD_APPDIR PYTHONDONTWRITEBYTECODE=1 python3 -m unittest discover -s tests/automated
PYTHONDONTWRITEBYTECODE=1 python3 -m unittest tests.automated.test_small_v1_final_user_cutter_holes_rev112_contract tests.automated.test_small_v1_merged_mouth_pane_rev113_contract tests.automated.test_cat_head_visible_freecad_review_copy
node tests/automated/validate_mvp_bike_patterns.js
```

The broad-suite command still exits nonzero. Its historical before/after match
proved cleanup preservation, not all-green CAD tooling. The old cleanup scripts
were permanently deleted; do not try to rerun prepare/apply/verify from recovery.
Earlier manifests describe historical snapshots. The final retirement proof records
the later independent GitHub download and retained-file hash checks.

## Regeneration and next physical review

There is no single regeneration command for manually edited V6/V5/V2 or the
manual lower masters. Begin a rebuild in a new, user-approved design document.
Historical lower-mesh commands remain in [the working record](working/README.md);
the exact tiny command is in [GATE7_SMALL_TEST_PRINT.md](GATE7_SMALL_TEST_PRINT.md).
Do not run them to overwrite retained evidence. Midsize regeneration still needs
a fresh authorized preflight and reviewed pins after the earlier path migration.

Review actual BM parts, record fit/failures, confirm which shell, eyes, ears,
rail and aluminum dimensions carry forward, then ask the user to select one
canonical source and a bounded numeric design contract before CAD work.

## GitHub backup — verified before final recovery deletion

Git LFS 3.8.0 is installed user-locally and configured only for this repository.
Root .gitattributes defines the mechanical large-file policy. Selected source,
docs, tests and retained build packages are committed and pushed, including all 167 geometry
files in RETAINED_FILES.json; their LFS SHA-256 values match the original bytes.
The complete LFS selection has 209 paths / 187 unique objects.
Archive payloads, tmp diagnostics and unselected historical tests are excluded.

The user explicitly approved ibukeev/cat_bike main and the selected payload.
Backup commit bd84d8449205c2828a92f32adfedc204fe48b4f8 was independently
downloaded; all 952 tracked files/links matched local bytes, Git LFS fsck passed,
and the 17 focused tests plus all 10 lighting patterns passed in that checkout.
Only then was .cleanup-recovery/ permanently deleted. Existing history was not
rewritten. The backup protects retained work, not deleted archive payloads.
Workflow revision is still pending user alignment; no CAD rules or approvals
were relaxed by this filesystem cleanup and backup.

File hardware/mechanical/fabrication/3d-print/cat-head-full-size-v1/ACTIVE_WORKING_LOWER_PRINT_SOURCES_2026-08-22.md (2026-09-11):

# Active working lower print sources

Status date: 2026-08-22

## User decision

The operator approved the following two working lower-shell STLs for the
current physical print run. They are the source of truth for this active print
iteration and any physical-fit feedback from it.

## Active print artifacts

| Side | Active STL |
| --- | --- |
| Right lower | `hardware/mechanical/fabrication/3d-print/cat-head-full-size-v1/working/right-lower/right-lower-final-review-voxel-union-025mm.stl` |
| Left lower | `hardware/mechanical/fabrication/3d-print/cat-head-full-size-v1/working/left-lower/left-lower-final-review-voxel-union-025mm.stl` |

## Active editable CAD source

`output/70-freecad-pilots/opposite-side-flange-pilot-v1/right-upper-as-printed-working-assembly-v1/RIGHT_UPPER_AS_PRINTED_WORKING_ASSEMBLY_V2.FCStd`

The FreeCAD document contains the working source collections:

- `RIGHT_LOWER_PRINT_SOURCE_COMPOUND`
- `LEFT_LOWER_PRINT_SOURCE_COMPOUND`

## Known validation state

Both artifacts are 0.25 mm voxel-union review meshes. They are watertight but
are not validated as monolithic structural solids:

| Side | Connected shells | Other known condition |
| --- | ---: | --- |
| Right lower | 27 | PrusaSlicer reported auto-repair of 8 errors during handoff. |
| Left lower | 16 | No single-solid claim has been made. |

These print artifacts supersede earlier lower-shell preview exports for the
current physical iteration only. They do **not** replace frozen canonical
context, create a general fabrication release, or waive future geometry,
load-path, slicer, or physical-fit verification.

## Next physical-review action

After printing, record fit, seam closure, mounting clearance, and any
shell-to-shell movement. Use that evidence to decide which remaining gaps need
explicit bridge geometry before the next source-of-truth print iteration.

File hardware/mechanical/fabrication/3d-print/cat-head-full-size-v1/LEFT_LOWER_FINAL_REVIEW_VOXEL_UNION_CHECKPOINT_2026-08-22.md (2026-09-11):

# Left lower final-review voxel-union checkpoint

Date: 2026-08-22

## In-document source collection

`LEFT_LOWER_PRINT_SOURCE_COMPOUND` was created in the active mutable FreeCAD
derivative from 41 objects:

- `WORKING_LEFT_LOWER_STRUCTURAL_V1`
- `LEFT_LOWER_3MM_INWARD_PREVIEW_001` through `_038`
- visible local cut results `Cut003` and `Cut004`

Hidden seam-fill source previews were excluded because the visible cut results
supersede them. Frozen context and right-side work were excluded.

## Review outputs

- input compound STL:
  `hardware/mechanical/fabrication/3d-print/cat-head-full-size-v1/working/left-lower/input-overlap-compound.stl`
- voxel-unioned review STL:
  `hardware/mechanical/fabrication/3d-print/cat-head-full-size-v1/working/left-lower/left-lower-final-review-voxel-union-025mm.stl`
- health report:
  `hardware/mechanical/fabrication/3d-print/cat-head-full-size-v1/working/left-lower/mesh-health.json`
- voxel size: 0.25 mm

## Validation

- boundary edges: 0
- non-manifold edges: 0
- wire edges: 0
- connected components: 16
- watertight single component: false

This is a watertight review mesh suitable for slicer inspection as one job, but
it is not a verified monolithic left structural solid. Further bridge geometry
is required before claiming a one-piece load path.

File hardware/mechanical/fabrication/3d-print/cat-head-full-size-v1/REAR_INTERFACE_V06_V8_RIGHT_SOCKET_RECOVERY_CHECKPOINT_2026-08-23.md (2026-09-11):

# Rear-interface V0.6 — V8 right rail-socket recovery checkpoint — 2026-08-23

## Current state

`V8_REVIEW_ONLY__UNSAVED__NOT_PRINT_RELEASED`

The prior V6 cleanup removed the V34 right rail-socket/root context from the
working document.  The earlier V7 right-top print trial must therefore remain
**on hold**: it was sliced but its physical print was stopped because this
socket/root geometry was missing.

The live V6 session now contains a replacement review package:

- `PROPOSED_TOP_RIGHT_PRINT_PACKAGE_V8_SOCKET_CONTEXT_COMPOUND`
- 70 valid solids total.
- It keeps the existing 63-solid V7 package unchanged and adds seven valid
  V34 socket-context solids (C002+C042 are locally joined as one solid).
- This is a compound for positional review only. It is not a globally fused
  solid, not exported, and not approved for slicing or printing.

## Files and preservation

- Active working file: `output/70-freecad-pilots/opposite-side-flange-pilot-v1/right-upper-as-printed-working-assembly-v1/RIGHT_UPPER_AS_PRINTED_WORKING_ASSEMBLY_V6.FCStd`
- Preserved recovery source: `output/70-freecad-pilots/opposite-side-flange-pilot-v1/right-upper-as-printed-working-assembly-v1/RIGHT_UPPER_AS_PRINTED_WORKING_ASSEMBLY_V5.FCStd`
- V5 SHA-256: `5c7de806142b1955c692def5717ed5b46a40ffcbe6db07fad078fbacca730c3e`
- The V8 proposal was created after the last manual V6 save and is **not yet
  saved**. V5 was opened read-only as a geometry source and was not changed.

## Recovered frozen V34 context

Each item was copied by exact V5 object name and validated as one closed solid
with matching volume and bounding box:

1. `WORKING_RIGHT_UPPER_C002_V34_BASELINE`
2. `WORKING_RIGHT_UPPER_C022_V34_BASELINE`
3. `WORKING_RIGHT_UPPER_C023_V34_BASELINE`
4. `WORKING_RIGHT_UPPER_C033_V34_BASELINE`
5. `WORKING_RIGHT_UPPER_C034_V34_BASELINE`
6. `WORKING_RIGHT_UPPER_C037_V34_BASELINE`
7. `WORKING_RIGHT_UPPER_C038_V34_BASELINE`
8. `WORKING_RIGHT_UPPER_C042_V34_BASELINE`

`C002` and its true V34 root `C042` overlap by `638.793197 mm3`; their local
fuse is valid. All rail datums remain frozen and untouched.

Explicit exclusions:

- `C020` — omitted at the user's instruction.
- `C032` — rejected: it has zero common volume with C002 and is not its root.

## Rejected implementation

`fuse_v6_right_top_v7_with_recovered_socket_context_v8_v2.py` attempted one
global Boolean fuse of the V7 compound plus every recovered member. FreeCAD
reported `V8 fusion produced an invalid shape`; do not use that output path.
The invalid fuse did not create a saved or released artifact.

## Exact regeneration command

With V6 as the active FreeCAD document:

```python
exec(compile(open(r"/home/bsk/Projects/BM_personal_LED-projects /cat_bike/hardware/mechanical/fabrication/3d-print/cat-head-full-size-v1/source/cad-change-control/compose_v6_right_top_v7_with_recovered_socket_context_v8_v3.py", encoding="utf-8").read(), "compose_v6_right_top_v7_with_recovered_socket_context_v8_v3.py", "exec"))
```

The script directly reads V5 (no transient GUI selection), copies/validates
the eight named sources, locally fuses only C002+C042, then makes the valid
70-solid review compound. It never changes a rail datum, V5, V7, or any source
solid; it never saves, exports, or print-releases.

## Required next review

1. Inspect V8 at close range and confirm the recovered C002 socket and C042
   root meet the visible top-right shell exactly where expected.
2. Confirm the surrounding recovered C022/C023/C033/C034/C037/C038 context
   has no unintended duplicate or collision with the V7 trial geometry.
3. Only after explicit user approval, decide whether a slicer-safe union or a
   multi-body 3MF handoff is required. Do not restart `RIGHT_TOP_PRINT.3mf`
   from the earlier V7-only geometry.

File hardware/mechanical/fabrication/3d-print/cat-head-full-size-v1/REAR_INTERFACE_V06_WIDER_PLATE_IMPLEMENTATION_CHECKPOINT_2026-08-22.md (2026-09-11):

# Rear Interface V0.6 Wider-Plate Implementation Checkpoint — 2026-08-22

## Status

`PLAN_APPROVED__IMPLEMENTATION_NOT_STARTED__INTERACTIVE_FREECAD_HANDOFF`

The user approved the coordinated architecture and numeric first proposal in
this checkpoint. Continue interactively in the exact working FreeCAD document
listed below. No rear-interface geometry, mirroring, Boolean integration, STL,
G-code, or fabrication release was created in the planning chat.

The repository V2 recovery rules still require a six-view baseline pack and
explicit visual approval before geometry mutation. After that baseline is
approved, collect and approve structured right-side FreeCAD face/edge anchors
before creating the isolated proposal.

## Active interactive FreeCAD document

Full path:

`/home/bsk/Projects/BM_personal_LED-projects /cat_bike/hardware/mechanical/fabrication/3d-print/cat-head-full-size-v1/output/70-freecad-pilots/opposite-side-flange-pilot-v1/right-upper-as-printed-working-assembly-v1/RIGHT_UPPER_AS_PRINTED_WORKING_ASSEMBLY_V2.FCStd`

SHA-256 recorded on 2026-08-22:

`f58d0428fe75030820cfea14f29dcca4da13415b9bf10e626285f6fb7dcf4a86`

This hash supersedes the older V1 working-assembly checkpoint hash for this
interactive session. Recompute it before resuming; stop if it differs unless
the user confirms that the newer saved document is intentional.

Relevant editable/working objects already recorded in the document include:

- `RIGHT_LOWER_PRINT_SOURCE_COMPOUND`
- `LEFT_LOWER_PRINT_SOURCE_COMPOUND`
- the user's current right-upper working objects in the same assembly

Frozen context objects must remain unchanged. Do not reconstruct a baseline
by mixing objects from older review documents.

## Protected current print evidence

The active lower-shell physical print iteration remains unchanged until a
later V0.6 review is approved:

| Side | Artifact | SHA-256 |
| --- | --- | --- |
| Right | `hardware/mechanical/fabrication/3d-print/cat-head-full-size-v1/working/right-lower/right-lower-final-review-voxel-union-025mm.stl` | `7b25103f37bdf5aba3c0a35cf866eab0622a60afaf73b28b82013a266893282f` |
| Left | `hardware/mechanical/fabrication/3d-print/cat-head-full-size-v1/working/left-lower/left-lower-final-review-voxel-union-025mm.stl` | `572cb4c3c58cca2ca88e596e55b8b1263ad154108526ddecebd9c99dc20064a2` |

These are physical-print SOT artifacts for the current iteration, not
monolithic-solid or complete-head releases.

## Approved physical architecture

1. Preserve the existing visible rear ASA form.
2. The rear ASA piece installs last and remains removable for service.
3. The removable piece is a shear-stiffening cover only; it does not carry the
   aluminum/backplate primary load.
4. Add the structural ASA material to the hidden rear-facing side of the
   permanent upper/lower head shells as broad pads and webs.
5. All service fasteners are accessible from the exterior/rear.
6. Keep the complete rail system fixed. Do not move rail axes, `X +/-40` lower
   targets, sockets, upper M4 stations, angle bases, angle-base holes, compound
   rail datums, or rail lengths.
7. No rear-cover gasket, seal, or drainage geometry is in scope.
8. Reserve a later drillable cable route through the widened aluminum plate;
   the cable hole is not allowed to weaken a structural pad or enter a rail,
   adapter, angle, hardware, or tool envelope.

## Approved V0.6 numeric first proposal

Create a new coordinated interface revision. Preserve V0.5 as immutable
history.

### Aluminum plate

- material: `3.0 mm` 6061-T6 aluminum;
- rear plane center: unchanged from V0.5;
- rear plane outward normal: unchanged from V0.5;
- height: `79.663819 mm`;
- top width: `90.0 mm`;
- bottom width: `160.0 mm`.

The larger plate grows around the frozen rail system. It must not cause any
rail, socket, angle, adapter, or rear insertion datum to move.

### Frozen metal holes and datums

- four adapter M6 paths remain at local `X +/-22`, `V +/-20`;
- right angle-base M5 centers remain `(36,-30)`, `(47.4,-30)`, `(38,-9)`;
- left angle-base centers remain their exact X mirror;
- all rail/socket/crossbolt geometry remains at V0.5-M2.

### Proposed shell-to-plate M5 pattern

Use six mirrored rear-normal M5 paths:

| Pair | Local plate coordinates, mm |
| --- | --- |
| Upper | `(-38,+30)`, `(+38,+30)` |
| Middle | `(-52,0)`, `(+52,0)` |
| Lower | `(-63,-30)`, `(+63,-30)` |

Hardware:

- `5.5 mm` aluminum clearance holes;
- rear-loaded `M5 x 20` bolts;
- `10 mm` OD washers;
- shell-side captive M5 nylocs;
- `14 mm` straight tool envelope.

Analytic first-pass margins that exact CAD must reproduce or improve:

- minimum M5 center-to-plate-edge distance: approximately `9.83 mm`;
- minimum 14 mm tool-to-plate-edge margin: approximately `2.83 mm`;
- minimum shell-tool to neighboring angle-hardware tool gap: approximately
  `2.6 mm`.

Fail closed below any of these gates:

- M5 cut-hole edge ligament: `5.0 mm`;
- tool-to-plate-edge clearance: `2.0 mm`;
- cut-hole-to-cut-hole ligament: `4.0 mm`;
- distinct hardware/tool-envelope clearance: `2.0 mm`.

### Permanent ASA pads and roots

- build the right side only for first review;
- upper and middle pads belong to the permanent right-upper shell owner;
- lower pad belongs to the permanent right-lower/rear shell owner;
- nominal pad: `24 x 36 x 12 mm`, rear-normal;
- current V7 captive-nyloc pocket basis: `8.2 mm` across flats,
  `9.47 mm` across corners, `5.5 mm` deep;
- connect every pad through two broad triangular webs;
- minimum continuous owner-root area: `720 mm2`;
- minimum true volumetric overlap into its owner: `1.0 mm`;
- no narrow single cantilever;
- zero outward change to the approved visible faceted exterior.

Do not place these pads or webs on the removable service cover.

### Removable rear shear cover

- preserve the current exterior and outline;
- rear-loaded locating-lip engagement: `3.0 mm`;
- mating clearance: `0.35 mm` per side;
- eight exterior M4 button-head screws;
- cover clearance bores: `4.5 mm`;
- captive brass inserts in fixed ASA bosses;
- locating lip carries shear; screws provide clamp;
- no gasket, sealing, or drainage features.

### Cable provision

- reserve mirrored drill zones near local `X +/-55`, `V -15`;
- keep both zones clear during structural design;
- select the actual side only after the bike cable/steering/lamp mockup;
- use the side with greater clearance, with right side as the tie-breaker;
- nominal final cable-only plate hole: `12 mm`, with split abrasion grommet;
- minimum cable bend radius: `12 mm`;
- provide strain relief within `25 mm` of the hole;
- if a complete connector rather than cable must pass through, stop and revise
  the contract before drilling.

## Required interactive implementation sequence

1. Verify the active FCStd hash and confirm it is the intended whole-head
   baseline candidate.
2. Capture opaque front, rear, left, right, top, and bottom screenshots with
   all intended production/working objects visible.
3. Save their paths and hashes in a V2 baseline manifest and obtain explicit
   user approval. Until then, geometry mutation remains blocked.
4. In FreeCAD, select the right-upper and right-lower rear-facing owner faces
   intended to receive the three right-side pad/web roots, plus the relevant
   rear-cover perimeter edges.
5. Record object internal name and label, sub-element ID, centroid, normal,
   bounding box, area/length, and owning part. Highlight the anchors and obtain
   explicit user approval.
6. Write one V2 mutation contract for one right-side working target. Keep the
   proposed plate, pads, hardware, and tool envelopes in separate
   `PROPOSED__` review objects; do not union them to working owners.
7. Prove the shared construction/finalization tooling with deterministic tests
   and a pinned-runtime, disposable, unsaved FreeCAD construction preflight.
8. In a fresh candidate chat, generate exactly one persisted right-side
   candidate through `run_iteration_v2.py`, then run preservation and bounded
   pre-visual validation.
9. Present the complete opaque six-view pack, anchor view, dimensions,
   interior/section hardware view, isolated proposal, insertion sweep, and
   validation table. Stop for explicit approval.
10. Mirror, integrate, export, slice, fabricate, and promote only after their
    separate approvals.

## Validation contract

The isolated proposal must prove:

- exact preservation of every frozen object and all rail/metal datums;
- widened plate valid and contained behind the preserved rear ASA form;
- complete metal/rail insertion, seating, fastening, and removal sweeps;
- all M5 and M4 hardware, washer, nut/insert, driver, and straight-tool paths;
- each pad and web is a valid closed solid with the required owner engagement;
- zero collision with frozen shells, rails, angles, crossbolts, adapter,
  sockets, eyes, ears, lighting, and reserved cable zones;
- zero unintended exterior protrusion;
- rear cover installs and removes by rear translation without cutting,
  bending, or separating the permanent shells;
- removing the cover exposes all six structural M5 fasteners;
- modified owner parts remain one connected printable component;
- Prusa MK4S support/brim orientation retains at least `10 mm` XY margin.

Physical release remains gated by:

- one right-side pad/root/captive-nut coupon;
- one M4 insert/locating-lip coupon;
- at least 20 cover service cycles without cracking, insert rotation, or
  looseness;
- a 60-second stationary proof load in forward, rearward, upward, downward,
  lateral, and torsional directions to the greater of `60 N` or five times
  completed-head weight;
- zero slip, cracking, creep, permanent deformation, or fastener movement;
- independent metal safety tether, vibration inspection, steering/lamp/cable
  clearance, and progressive low-speed ride tests.

## Rejected or prohibited variants

- moving either rail, its target, socket, cap station, or crossbolt datum;
- attaching the primary aluminum load path to the removable cover;
- deep rear undercut flanges that block insertion or removal;
- inaccessible loose internal nuts;
- placing new M5 paths at the old concentrated V0.5 centers;
- cutting accepted exterior skin to recover pad placement;
- adding a cable hole before its zone clears every structural and tool
  envelope;
- mirroring or integrating the right-side proposal before explicit approval;
- treating a successful slicer repair or overlapping compound as proof of a
  monolithic structural solid.

## Current validation performed

- Read-only FreeCAD connection check passed on 2026-08-22:
  FreeCAD `1.1.3`, GUI instance available.
- Current working FCStd and active lower STL hashes were recorded above.
- V0.5 shared-interface SHA-256:
  `6326b211e4eef8c87a2b17687e2d68406682d21a6fa7c81ad52c8a1b9e713c79`.
- The plate/hole margins above are analytic preflight values only; exact CAD,
  insertion, owner engagement, and hardware access remain unvalidated.

## Exact next user action

Start a clear Codex chat in the repository and provide this checkpoint path.
Keep `RIGHT_UPPER_AS_PRINTED_WORKING_ASSEMBLY_V2.FCStd` open. The new chat must
verify the file hash, capture the six opaque baseline views, and ask for their
explicit approval before requesting the right-side rear owner-face selections.

Suggested starter prompt:

```text
Resume the approved rear-interface V0.6 plan from
hardware/mechanical/fabrication/3d-print/cat-head-full-size-v1/REAR_INTERFACE_V06_WIDER_PLATE_IMPLEMENTATION_CHECKPOINT_2026-08-22.md.
Work interactively in the exact RIGHT_UPPER_AS_PRINTED_WORKING_ASSEMBLY_V2.FCStd
listed there. Keep every rail datum frozen. First verify the FCStd hash and
capture the six-view opaque V2 baseline pack; do not create geometry until I
approve that baseline and the selected right-side rear owner faces.
```

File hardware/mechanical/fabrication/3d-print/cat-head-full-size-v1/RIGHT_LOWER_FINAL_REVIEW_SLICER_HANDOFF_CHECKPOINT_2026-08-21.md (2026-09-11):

# Right lower final-review slicer handoff checkpoint

Date: 2026-08-21

## Review artifact loaded in PrusaSlicer

`hardware/mechanical/fabrication/3d-print/cat-head-full-size-v1/working/right-lower/right-lower-final-review-voxel-union-025mm.stl`

## Observed slicer setup

- Printer: Original Prusa MK4 Input Shaper, 0.4 mm nozzle
- Filament: Prusament ASA
- Profile: 0.20 mm Structural
- Infill: 15%
- Brim: enabled
- Supports: none
- Displayed model size: 215.28 x 175.92 x 150.53 mm

## Handoff result and limitation

PrusaSlicer loaded the model as a single print job and displayed 27 shells. It
reported that it auto-repaired 8 errors. The source mesh therefore remains a
review/print-test artifact rather than verified one-piece structural geometry.
If physical-load performance matters, inspect the previewed toolpaths and
layers around every intended bridge before committing the print.

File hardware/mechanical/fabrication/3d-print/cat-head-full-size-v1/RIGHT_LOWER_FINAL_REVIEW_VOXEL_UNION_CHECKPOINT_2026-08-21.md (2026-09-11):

# Right lower final-review voxel-union checkpoint

Date: 2026-08-21

## Working FreeCAD derivative

`output/70-freecad-pilots/opposite-side-flange-pilot-v1/right-upper-as-printed-working-assembly-v1/RIGHT_UPPER_AS_PRINTED_WORKING_ASSEMBLY_V2.FCStd`

## In-document source collection

`RIGHT_LOWER_PRINT_SOURCE_COMPOUND` was created from 32 authorized mutable
working objects:

- `WORKING_RIGHT_LOWER_STRUCTURAL_V1`
- all available `RIGHT_LOWER_3MM_INWARD_PREVIEW*` objects
- `Cut001`
- `PROPOSED_RIGHT_LOWER_OUTBOARD_FACE_THICKEN_2MM`

Frozen context was excluded. This compound is an in-document source collection,
not a successful OCCT/BRep Boolean fusion.

## Review artifacts

- Input STL: `hardware/mechanical/fabrication/3d-print/cat-head-full-size-v1/working/right-lower/input-overlap-compound.stl`
- Voxel-union STL: `hardware/mechanical/fabrication/3d-print/cat-head-full-size-v1/working/right-lower/right-lower-final-review-voxel-union-025mm.stl`
- Health report: `hardware/mechanical/fabrication/3d-print/cat-head-full-size-v1/working/right-lower/mesh-health.json`
- Union resolution: 0.25 mm

## Validation result

- boundary edges: 0
- non-manifold edges: 0
- wire edges: 0
- connected components: 27
- `watertight_single_component`: false

The exported review STL is watertight but remains a 27-shell mesh. It must not
be treated as one connected printable structural solid until the remaining
shell-to-shell bridges are designed, reviewed, and rerun through this pipeline.

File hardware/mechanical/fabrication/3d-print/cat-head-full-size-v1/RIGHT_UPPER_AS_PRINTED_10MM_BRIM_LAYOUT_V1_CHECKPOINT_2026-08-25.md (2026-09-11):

# Right Upper As-Printed 10 mm Brim Layout V1 Checkpoint — 2026-08-25

## Status

`PASS_LAYOUT__HOLD_SOURCE_MESH_AND_PHYSICAL_FIRST_LAYER`

The user approved `RIGHT-UPPER 10MM BRIM LAYOUT V1` on 2026-08-25. The
approved slicer placement and 10 mm outer brim fit the Original Prusa MK4 bed.
No CAD object, STL triangle, scale, FreeCAD file, or source 3MF was changed.

This is a slicer-layout pass, not an unconditional print release. The frozen
source is non-manifold, and the full first layer still requires direct physical
observation before committing to the approximately 16-hour ASA job.

## Current review and output files

- PrusaSlicer project:
  `output/50-slicer-projects/right-upper-as-printed-10mm-brim-layout-v1/CAT_HEAD_RIGHT_UPPER_AS_PRINTED_10MM_BRIM_LAYOUT_V1.3mf`
- Diagnostic G-code, not release-approved:
  `output/50-slicer-projects/right-upper-as-printed-10mm-brim-layout-v1/CAT_HEAD_RIGHT_UPPER_AS_PRINTED_10MM_BRIM_LAYOUT_V1.gcode`
- First-layer review evidence:
  `output/50-slicer-projects/right-upper-as-printed-10mm-brim-layout-v1/first-layer-brim-support-evidence-v1.png`
- Vector evidence:
  `output/50-slicer-projects/right-upper-as-printed-10mm-brim-layout-v1/first-layer-brim-support-evidence-v1.svg`
- Validation:
  `output/50-slicer-projects/right-upper-as-printed-10mm-brim-layout-v1/validation-v1.json`
- Numeric contract:
  `config/right-upper-as-printed-10mm-brim-layout-v1.json`
- Deterministic generator:
  `source/create_right_upper_as_printed_10mm_brim_layout_v1.py`
- Independent validator and evidence renderer:
  `source/validate_right_upper_as_printed_10mm_brim_layout_v1.py`

## Frozen sources

- Source `assembly.3mf` SHA-256:
  `ac800ac7470c61cf4d640af6d652b25ac080142826aaadb4d24842bb9440720b`
- Source `assembly.stl` SHA-256:
  `6b7ced6a6cb86e5d7635f622f6e18df53bf616a378823443f98dd8aa1e4c2f4d`
- Review 3MF SHA-256:
  `8b2efa7a9d77a46f7fe0a82187518ffebf55d02b86a6eeb080362611293b2c4a`
- Diagnostic G-code SHA-256:
  `c55b2455556b814c166e98b1ef7d6679641cc40c193c8eff15360c8346e29509`

Archive comparison proves that only `3D/3dmodel.model` and
`Metadata/Slic3r_PE.config` changed. Within those members, only the single
build-item transform plus `brim_type` and `brim_width` changed. The 5,036 mesh
vertices, 9,556 triangles, all other archive members, and scale `1.0` are
unchanged.

## Accepted placement and process contract

- Additional world-X tilt: `+22.0 deg`.
- Additional world-Z rotation: `-9.0 deg`.
- Bed center: `X 125.0 mm`, `Y 105.0 mm`.
- Lowest mesh point: `Z 0.0 mm`.
- Final 3MF transform:
  `[-0.362612279462, -0.819482334334, 0.443802927262, -0.664989563555, 0.561156369453, 0.492841160774, -0.652917464179, -0.116414057070, -0.748429390465, 116.437612950, 110.220650427, 58.350728023]`.
- Outer-only brim: `10.0 mm`, separation `0.1 mm`.
- Retained profile: Prusament ASA, MK4IS 0.4 mm nozzle, `0.20 mm` layers,
  `25%` grid infill, three perimeters, automatic snug supports at `40 deg`.

## Validation performed

- Generator source/hash/topology checks: `PASS`.
- Source preservation and exact permitted archive-difference check: `PASS`.
- Transform, orthonormal scale, determinant, and centered bounds: `PASS`.
- PrusaSlicer 2.7.4 diagnostic slice: `PASS`.
- Actual first-layer extrusion bed margin gate, required `>=5 mm`: `PASS`.
- Actual margins left/right/front/rear:
  `14.891 / 14.304 / 10.759 / 15.375 mm`.
- Brim path found: `PASS`, outer-only `10 mm`.
- First-layer support paths found: `PASS`, automatic snug support retained.
- Estimated print time: `16h 12m 34s`.
- Estimated filament: `91,082.53 mm`, `219.08 cm3`, `234.41 g`.

## Rejected or unsafe variants

- Frozen source placement: approximately `214.0 x 201.9 mm`; rejected for a
  10 mm perimeter allowance because front/rear clearance is insufficient.
- Z rotation alone: best observed footprint approximately
  `214.83 x 198.96 mm`; rejected because it still cannot provide the approved
  10 mm allowance.
- `+15 deg` X tilt: only approximately `0.15 mm` reserve outside the
  conservative 10 mm envelope; rejected as too tight.
- Printing without a brim: physically failed in the user-provided print.
- Unattended full print from the diagnostic G-code: held because the source
  mesh remains non-manifold and the support islands require first-layer
  physical confirmation.

PrusaSlicer `--info` reports the unchanged source as: 9,556 facets,
non-manifold, 75 open edges, 16 reversed facets, 48 backwards edges, and 166
parts. Slicing completes, but slicer repair is not proof of a structurally
valid CAD owner.

## Exact regeneration

From the repository root:

```bash
python3 hardware/mechanical/fabrication/3d-print/cat-head-full-size-v1/source/create_right_upper_as_printed_10mm_brim_layout_v1.py \
  hardware/mechanical/fabrication/3d-print/cat-head-full-size-v1/output/70-freecad-pilots/opposite-side-flange-pilot-v1/right-upper-as-printed-working-assembly-v1/assembly.3mf \
  hardware/mechanical/fabrication/3d-print/cat-head-full-size-v1/output/70-freecad-pilots/opposite-side-flange-pilot-v1/right-upper-as-printed-working-assembly-v1/assembly.stl \
  hardware/mechanical/fabrication/3d-print/cat-head-full-size-v1/output/50-slicer-projects/right-upper-as-printed-10mm-brim-layout-v1/CAT_HEAD_RIGHT_UPPER_AS_PRINTED_10MM_BRIM_LAYOUT_V1.3mf
```

```bash
prusa-slicer --dont-arrange --export-gcode \
  --output hardware/mechanical/fabrication/3d-print/cat-head-full-size-v1/output/50-slicer-projects/right-upper-as-printed-10mm-brim-layout-v1/CAT_HEAD_RIGHT_UPPER_AS_PRINTED_10MM_BRIM_LAYOUT_V1.gcode \
  hardware/mechanical/fabrication/3d-print/cat-head-full-size-v1/output/50-slicer-projects/right-upper-as-printed-10mm-brim-layout-v1/CAT_HEAD_RIGHT_UPPER_AS_PRINTED_10MM_BRIM_LAYOUT_V1.3mf
```

```bash
python3 hardware/mechanical/fabrication/3d-print/cat-head-full-size-v1/source/validate_right_upper_as_printed_10mm_brim_layout_v1.py \
  --contract hardware/mechanical/fabrication/3d-print/cat-head-full-size-v1/config/right-upper-as-printed-10mm-brim-layout-v1.json \
  --source-project hardware/mechanical/fabrication/3d-print/cat-head-full-size-v1/output/70-freecad-pilots/opposite-side-flange-pilot-v1/right-upper-as-printed-working-assembly-v1/assembly.3mf \
  --source-stl hardware/mechanical/fabrication/3d-print/cat-head-full-size-v1/output/70-freecad-pilots/opposite-side-flange-pilot-v1/right-upper-as-printed-working-assembly-v1/assembly.stl \
  --review-project hardware/mechanical/fabrication/3d-print/cat-head-full-size-v1/output/50-slicer-projects/right-upper-as-printed-10mm-brim-layout-v1/CAT_HEAD_RIGHT_UPPER_AS_PRINTED_10MM_BRIM_LAYOUT_V1.3mf \
  --gcode hardware/mechanical/fabrication/3d-print/cat-head-full-size-v1/output/50-slicer-projects/right-upper-as-printed-10mm-brim-layout-v1/CAT_HEAD_RIGHT_UPPER_AS_PRINTED_10MM_BRIM_LAYOUT_V1.gcode \
  --report hardware/mechanical/fabrication/3d-print/cat-head-full-size-v1/output/50-slicer-projects/right-upper-as-printed-10mm-brim-layout-v1/validation-v1.json \
  --evidence-svg hardware/mechanical/fabrication/3d-print/cat-head-full-size-v1/output/50-slicer-projects/right-upper-as-printed-10mm-brim-layout-v1/first-layer-brim-support-evidence-v1.svg
```

## Next physical-review steps

1. Open the review 3MF and inspect layer 1. Orange is the 10 mm model brim;
   the broad blue/cyan regions are separate support first-layer paths.
2. Clean the satin sheet with the preparation appropriate for ASA and verify
   the enclosure is at the intended temperature.
3. Start the print while present and observe the entire first layer.
4. Stop immediately if the central brim or any separate support island curls,
   gaps, or lifts. Do not let a detached island turn into another spaghetti
   failure.
5. If every island remains bonded, record a photograph before authorizing the
   remainder of the print or treating this layout as physically proven.

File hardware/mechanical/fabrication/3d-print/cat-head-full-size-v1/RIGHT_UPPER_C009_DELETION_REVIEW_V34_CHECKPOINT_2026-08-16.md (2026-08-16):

# Right Upper C009 Deletion Review V34 Checkpoint — 2026-08-16

## Status

`PASS__REVIEW_ONLY_ONE_SIDED_C009_DELETION`

V34 is ready for visual review. It is not a production owner, STL, slicer
project, G-code, or ASA print release.

## Approved scope

- Start from the accepted pre-V33 V25 right-upper component manifest.
- Delete/exclude only the separate right-upper C009 component.
- Do not move or resize C009.
- Add no replacement member, support, reinforcement, or filler.
- Do not mirror, production-union, export, slice, or release ASA geometry.
- Show the retained right upper head with the repaired right eye, right lower
  face, right primary ear, and translucent under-ear A/B panel.

The rejected V33 reposition remains historical evidence only. It placed C009
through the translucent under-ear panel region; V34 intentionally uses the
simpler approved deletion instead.

## Current review files

- FreeCAD review:
  `output/70-freecad-pilots/opposite-side-flange-pilot-v1/right-upper-c009-deletion-review-v34/CAT_HEAD_RIGHT_UPPER_C009_DELETION_REVIEW_V34.FCStd`
- Validation:
  `output/70-freecad-pilots/opposite-side-flange-pilot-v1/right-upper-c009-deletion-review-v34/validation-v34.json`
- Change contract:
  `source/cad-change-control/pilot/right-upper-c009-deletion-review-v34.json`
- Generator:
  `source/cad-change-control/generate_right_upper_c009_deletion_review_v34.py`

## Output hashes

- FreeCAD review SHA-256:
  `2ff90641bf13ecebbd5ab7b5d388dd511b2577b0cc38df73030c7c77b83fad2b`
- Validation SHA-256:
  `c2e49a2c6f448a5690ba600cb3c27ca1e210d36d165236031fdc5c732ce56d4b`
- Contract SHA-256:
  `d4c4c91ccf9df5d26c0866f25f7be50da54f8fff0ebbc10b1c09de2d0064d2a2`
- Generator SHA-256:
  `05f9316136efc605fecbe104aba8bf0e6b08a7788687a23a485aa16a634a67ba`

## Validation performed

| Gate | Result |
| --- | --- |
| All hash-pinned inputs match | PASS |
| Source manifest is exactly C001 through C042 | PASS |
| Retained manifest is exactly V25 minus C009 | PASS |
| Retained component count | PASS — 41 |
| Every retained component copy is exact | PASS |
| Retained compound | PASS — valid, closed, 41 solids |
| C009 objects in review | PASS — 0 |
| Added/replacement/support geometry | PASS — 0 |
| Subtractive cut | PASS — none |
| Full-context copies are exact | PASS |
| Repaired eye | PASS — valid, closed, one solid |
| Mirror, production union, or export | PASS — none performed |

The removed C009 volume is `227.92119760049138 mm3`; its recorded repaired-eye
intersection was `27.728296869034583 mm3`. The retained source component sum is
`150217.21686335685 mm3`. The review compound contains all 41 retained solids.

FreeCAD 1.1.1 was used once after headless generation to show both review groups
and save the presentation state. That save changed no geometry. The final
FreeCAD hash above is the post-presentation file.

Two fail-closed preflight attempts produced no saved CAD: the first exposed an
exact V25 status-string mismatch; the second exposed a harmless approximately
`0.002 mm3` OCCT compound-order volume difference. The final preservation gate
compares the exact sum of the 41 individually copied components.

## Exact regeneration command

From the repository root:

```bash
env PYTHONPATH=/tmp/freecad-1.1.3-extract/squashfs-root/usr/lib \
  /tmp/freecad-1.1.3-extract/squashfs-root/AppRun python \
  hardware/mechanical/fabrication/3d-print/cat-head-full-size-v1/source/cad-change-control/generate_right_upper_c009_deletion_review_v34.py \
  --contract hardware/mechanical/fabrication/3d-print/cat-head-full-size-v1/source/cad-change-control/pilot/right-upper-c009-deletion-review-v34.json \
  --overwrite-review-output
```

After regeneration, open the generated FCStd in FreeCAD, show
`RETAINED_RIGHT_UPPER_V34` and `FROZEN_FULL_CONTEXT_V34`, and save only the GUI
visibility state. Recompute the FCStd and validation hashes if that presentation
save changes the archive bytes.

## Next physical/visual review

Open the V34 FreeCAD review and confirm:

1. C009 is completely absent; there is no orange member, remnant, or replacement.
2. Deleting it did not create an unintended exterior hole, disconnected shell
   residue, or unsupported visible fragment.
3. The repaired eye, primary ear, and translucent under-ear A/B panel remain
   unobstructed in full right-side context.

Do not use V34 to judge or approve the separate residual C001-to-eye
intersection (`100.59904449678196 mm3`). That remains a held follow-up. Bilateral
validation, production-owner unification, STL export, slicing, G-code, and ASA
printing remain blocked pending later gates.

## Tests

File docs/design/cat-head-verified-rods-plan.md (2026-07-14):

# Cat Head Wireframe and Cardboard Prototype Plan

## Current Status

The cat head wireframe has moved from source-reconstruction work into a shape-approved prototype baseline.

Completed:

- Manual projection/node mapping workflow established from the Gemini ORX reference material.
- Iterative 3D wireframe edited in Onshape/OBJ review until the cat-head proportions looked acceptable.
- Side-only and mirrored backside nodes added where projection constraints were weak.
- Review rods were added/removed by mapped physical node IDs after visual inspection.
- Main node/rod geometry was slimmed for inspection: node radius 1.6 mm, rod radius 0.9 mm.
- Active workspace was renamed to:
  - `hardware/mechanical/fabrication/templates/cat-head-wireframe-prototype/`
- V1 baseline was frozen at:
  - `hardware/mechanical/fabrication/templates/cat-head-wireframe-prototype/versions/v1-shape-approved-cardboard-prototype/`

V1 snapshot contents:

- `cad/`: OBJ, STL, HTML preview, PNG, and review marker exports.
- `data/`: node CSV, rod CSV, residual/skipped-edge reports, part map, and generated report.
- `source/`: generator scripts and trace/mapping CSVs needed to reproduce the V1 model.

Current V1 model count:

- 72 nodes
- 166 rods

## Current Fabrication Direction

The next build should be a fast cardboard prototype, not final material fabrication.

Preferred near-term approach:

1. Use the V1 wireframe as the shape/topology baseline.
2. Define flat triangular/quadrilateral panel faces from the rod graph.
3. Generate labeled cardboard panel templates.
4. Cut/tape a faceted shell prototype to validate silhouette, scale, and assembly logic.
5. Only after the cardboard shell looks right, choose final panel materials and mounting details.

Preferred final-direction options remain open:

- Rod skeleton plus panels.
- Rod skeleton plus 3D-printed hubs.
- Flat cut panels with tabs.
- Full 3D-printed shell, only if later worth the complexity.

For now, the rod skeleton plus flat panels path preserves the most optionality.

## Material Direction Captured

Likely main finish:

- Thin flat panels wrapped in gold mirror vinyl.
- Alternative: gold mirrored acrylic/polycarbonate/PETG if durability and sourcing work out.

Likely glow/translucent areas:

- Frosted or smoked acrylic/polycarbonate panels.
- Optional two-way mirror or reflective film over clear/frosted plastic for panels that look reflective when off and glow when lit.

## Next Implementation Steps

1. Create a panel-face definition file.
   - Input: V1 `data/gemini_3d_plus_symmetry_nodes.csv` and `data/gemini_3d_plus_symmetry_rods.csv`.
   - Output: a CSV or JSON listing panel IDs and corner node IDs.

2. Start with a small number of high-confidence visible faces.
   - Prioritize large front/cheek/forehead facets.
   - Avoid dense/uncertain backside details until the main silhouette is validated.

3. Generate panel templates.
   - For each panel, output edge lengths and a flat 2D polygon.
   - Label every panel and every edge with adjacent node IDs.
   - Add simple assembly notes and neighbor references.

4. Build a taped cardboard prototype.
   - Use cardstock/cereal-box cardboard first if small scale.
   - Use foamcore or corrugated cardboard if full-scale stiffness is needed.
   - Tape first; glue only after shape is visually accepted.

5. Review prototype against desired cat-head read.
   - Check front silhouette.
   - Check side depth and muzzle/ear proportions.
   - Check whether rods/panel seams support the intended low-poly visual.
   - Mark edits as node moves, rod changes, or panel-face changes.

6. Branch after cardboard validation.
   - If shape is good: create final panel material plan and mount integration.
   - If shape is close: edit the V1 graph and freeze V2.
   - If assembly is confusing: simplify panel topology before final material work.

## Verification Gates

- Gate A: V1 wireframe snapshot exists and can be reopened in Onshape/FreeCAD.
- Gate B: panel-face list covers the main visible shell without obvious gaps.
- Gate C: generated cardboard templates have labels, edge lengths, and neighbor references.
- Gate D: cardboard prototype is physically assembled and photographed from front/side/back.
- Gate E: steering/mount envelope is checked against the bike before final material fabrication.

## Notes

- V1 is a shape-approved prototype baseline, not a final fabrication CAD model.
- Weakly constrained nodes are acceptable for cardboard testing as long as they are visibly marked in the source data.
- Do not generate final cut lengths, hub sockets, or production panel tabs until the cardboard prototype confirms the shape.

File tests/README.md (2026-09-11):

# Tests

Use this area for verification.

- `manual/` - checklists for bench tests, bike installation checks, night tests, and playa readiness.
- `automated/` - tests for any scripts, pattern transforms, generated files, or configuration validators.

Use `manual/cat-head-lighting-gates.md` for physical coupon and integration gates.

Document the exact hardware setup used for manual tests.

## Retained-build checks

From the repository root, with the retained Git LFS files downloaded:

```bash
PYTHONDONTWRITEBYTECODE=1 python3 -m unittest \
  tests.automated.test_bilateral_eye_carrier_corner_clearance_v3_print_release_v1 \
  tests.automated.test_right_eye_front_rear_print_packaging_v1 \
  tests.automated.test_small_v1_final_user_cutter_holes_rev112_contract \
  tests.automated.test_small_v1_merged_mouth_pane_rev113_contract \
  tests.automated.test_cat_head_visible_freecad_review_copy
node tests/automated/validate_mvp_bike_patterns.js
```

On 2026-09-10 these ran 35 passing Python tests and passed the mapper and all
10 lighting patterns. They check retained contracts/tooling, not physical fit,
structural strength, new geometry, or a new print release.

## Historical CAD checks and known limits

The user authorized deleting or committing the 29 previously untracked test
files on 2026-09-10. Twenty-four were retained unchanged because their matching
source/contracts are already tracked and they retain release, numeric-regression,
or safety-check coverage. Being retained does not make an old design approved.

Removed from that untracked set:

- `test_lower_front_bilateral_feedback_cleanup_review_v3.py`: byte-for-byte
  duplicate of the retained V2 test, including its V2 paths and assertions.
- `test_right_eye_serviceable_fit_tooling_v4.py`, `..._v5.py`, `..._v6.py`, and
  `..._v6_attempt_002.py`: stale version-specific acceptance snapshots that still
  assert those designs are not rejected. The rejection registry now rejects them.
- The root `tmp_eye_audit_probe_marker.txt`, containing only `temporary`.

The CAD source, rejection registry, numeric gates, approval fields, hash pins and
all retained test bytes were left unchanged. No CAD runtime or generator ran.
The obsolete untracked tests were deleted, not committed as another archive;
the duplicate content remains in the retained V2 test.

The complete historical suite is still not all green:

```bash
env -u CAT_HEAD_FREECAD_APPDIR PYTHONDONTWRITEBYTECODE=1 \
  python3 -m unittest discover -s tests/automated -p 'test_*.py'
```

Fresh-process result after this triage: 280 tests, 1 failure, 4 errors and 36
skip events. Remaining problems are two lower-C001 modules importing unavailable
FreeCAD, the retired eye-validator candidate fixture, an eye-validator iteration-ID
mismatch during combined discovery, and the old cat-head lighting test expecting
the absent `glow_pairs` field. CAD-only tests skip without their runtime; some also
require retired fixtures even when FreeCAD is available. Do not infer a runtime
pass from a skip, recreate rejected candidates, repin evidence, or relax guards
to make these tests green. Their supported future scope is a separate review.

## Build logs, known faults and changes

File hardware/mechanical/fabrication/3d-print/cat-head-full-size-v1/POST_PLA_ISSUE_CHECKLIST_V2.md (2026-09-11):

# Post-PLA issue closure checklist V2

This is the execution checklist for the physical problems reported after the
full-size PLA assembly. It preserves the original `F-01` through `F-29` IDs
from `hardware/mechanical/CAT_HEAD_MOUNT_AND_SHELL_PHYSICAL_FIT_REVIEW_2026-07-28.md`.

**Release state: HOLD.** No unchecked item is implied to be fixed by an old
isolated review, a numerical pass, or a visually reasonable V34 baseline.

## Controlled baseline

- Canonical recovery assembly: V34.
- Baseline manifest:
  `source/cad-change-control/v2/approved-baseline-v34.json`.
- V34 is a recovery baseline, not print-ready geometry.
- Previous review files are evidence only. Do not copy their objects into V34.
  Reproduce an accepted correction as a bounded V2 operation on the current
  canonical baseline.

## How to close one item

For the one active finding, complete every applicable step before checking its
top-level box:

- [ ] Confirm the failure, or the accepted correction, in the current canonical
      assembly using fixed whole-assembly and focused views.
- [ ] Identify one exact FreeCAD target object and one exact operation.
- [ ] Approve a V2 iteration contract with a unique iteration ID.
- [ ] Generate one candidate from the canonical baseline; do not retry or repair.
- [ ] Pass independent non-target preservation comparison.
- [ ] Receive explicit user visual approval of the candidate hash.
- [ ] Pass the applicable independent geometry, topology, assembly, and slicer
      checks.
- [ ] Pass the applicable real hardware, hand-fit, service, or structural test.
- [ ] Record the evidence and only then check the finding below.

If a finding needs several object changes, use several serial V2 iterations.
The finding remains unchecked until the complete physical acceptance condition
passes.

## A. Rear shell and aluminum interface

- [ ] **F-01 — Rail path blocked by shell.** Prior digital route is frozen;
      V34 presence and real insertion are unproven. Close with A-05, A-38, and
      A-39.
- [ ] **F-02 — Portal axis does not match the rail axis.** Pitch, yaw, roll, and
      targets have prior digital evidence; verify the same revision in V34 and
      with actual 19.05 mm rails. Close with A-05 and A-38.
- [ ] **F-03 — Existing lamp/steering interference.** Still open because the
      measured lamp, beam, cable, and steering envelopes are missing. Close
      with A-06.
- [ ] **F-04 — Rear base cannot install without cutting.** Lossless rear-cassette
      V5 was an accepted direction only. Integrate a rear-loaded cassette around
      the aluminum envelope and close with A-01, A-02, and A-39.
- [ ] **F-05 — Backplate holes too close to corners.** Inward hole placement has
      digital evidence; real bolt, washer, nut, finger, and tool access remain
      unproven. Close with A-03 and A-39.
- [ ] **F-06 — Rear mounting flanges too small/flimsy.** Final cassette-owned M5
      structural pads are not complete. Close with A-04 and A-39.

## B. Under-ear insert and ear attachment

- [ ] **F-07 — Under-ear insert upper-corner collisions.** V3 relief direction
      was accepted digitally; verify it exists in V34/future canonical geometry
      and pass the real hand-fit test. Close with A-07.
- [ ] **F-08 — Under-ear insert lower-center collision.** Prior insertion-path
      evidence exists, but final reinforced-shell fit is open. Close with A-07.
- [ ] **F-09 — Under-ear insert globally too snug.** Prior deep-body/cap clearance
      direction exists; final material tolerance and hand fit are open. Close
      with A-07 and A-08.
- [ ] **F-10 — Plane mismatch and lateral sliding under clamp load.** Bilateral
      A/B owner reviews were accepted, but presence in V34 and physical seating
      behavior must be confirmed. Close with A-08 and A-09.
- [ ] **F-11 — One long connector over-constrains the insert.** Separated A/B
      retention direction was accepted; full-context and physical retention are
      open. Close with A-10.
- [ ] **F-12 — Under-ear flange access and weakness.** Hole/tool paths and broad
      roots have accepted digital evidence; exact production orientation,
      hardware installation, and strength remain open. Close with A-18.
- [ ] **F-13 — Outer ear flaps.** Anti-flap layout direction exists, but the final
      full-context joint and physical hand-load result are open. Close with A-11.
- [ ] **F-14 — Outer ear grounding point through the insert.** Accepted direction
      must be verified in the canonical assembly and tested without loading the
      diffuser skin as a primary structure. Close with A-11 and A-12.
- [ ] **F-22 — Ear interface has pin against pin.** The bilateral two-bolt
      round-hole/slot CAD was visually approved in primary-ear V2 and HS-09, but
      it must be confirmed in the canonical full context and physically mated
      with specified M3 hardware. Close with A-27.

## C. Central, nose, and side glow panels

- [ ] **F-15 — Central-panel back skirt collides internally.** Exact V34 owner and
      collision faces are still unidentified. Preserve the continuous skirt,
      add only local relief, and close with A-13 and A-14.
- [ ] **F-16 — Central panel flaps with only two upper connectors.** Add a broad,
      lower retention point on the correct vertical nose-side owner after exact
      owner selection. Close with A-15, A-16, and A-17.
- [ ] **F-17 — Front nose-panel skirt interferes and connector detached.** Exact
      owner selection remains open. Keep the skirt non-structural and use two
      broad-rooted connectors. Close with A-19 and A-20.
- [ ] **F-18 — Side-panel skirt collides and single connector is weak.** Confirm
      the side and exact owner first; relieve all affected corners and use two
      broad-rooted connectors. Close with A-21 and A-22.

## D. Eye socket, module, and cap

- [ ] **F-19 — Eye collides with multiple internal elements.** V34 visibly has a
      known eye/shell conflict. Audit the complete insertion and seated envelope
      before choosing the first target. Close with A-23 and A-31.
- [ ] **F-20 — Eye-to-head retention lacks an upper connection.** Prior flange
      layouts exist, but final head-owner integration, access, and strength are
      open. Close with A-24 and A-25.
- [ ] **F-21 — Both eye rear-cap connectors were lower.** Bilateral V9 records an
      accepted upper/lower layout; confirm it is present in the canonical
      geometry and physically serviceable. Close with A-26.
- [ ] **F-23 — Eye front frame was a disconnected floating island.** Prior V9
      one-solid bucket evidence is accepted, while the canonical and eventual
      production export must independently pass connected-body and slicer-layer
      checks. Close with A-28 and A-29.
- [ ] **F-24 — Eye head-mount tab was a fragile interfering cantilever.** A broad
      base direction was accepted and C002 remains rejected; final canonical
      integration and service testing are open. Close with A-31 and A-32.
- [ ] **F-28 — Eye bezel separated from the chamber.** Prior full-thickness wall
      continuation evidence exists; verify the canonical owner, true union, and
      physical joint strength. Close with A-30.

## E. Whole-shell systemic failures and fabrication

- [ ] **F-25 — Internal features protrude through the exterior.** Run an exterior
      deviation audit on every canonical shell owner, then correct one offending
      target per iteration. Close with A-33 and A-36.
- [ ] **F-26 — Shell exports contain many disconnected parts.** Build explicit
      production owners without loose or duplicate solids. Close with A-34.
- [ ] **F-27 — Opposing reinforcements collide across seams.** Assign
      complementary seam ownership and validate real assembly paths. Close with
      A-35.
- [ ] **F-29 — Lower shells lack usable build-plate margin.** Repartition without
      changing the approved exterior scale and validate the actual brim/support
      job. Close with A-37.

## Recommended execution order

1. Audit V34 object ownership and the exact presence of previously accepted
   ear and eye corrections; do not mutate geometry.
2. Close the eye workstream one finding at a time, beginning with F-19's visible
   eye/shell interference.
3. In parallel, perform read-only aluminum/rear measurements for F-01 through
   F-06; integrate those geometry changes serially.
4. Verify and finish the ear/under-ear findings, reusing old reviews only as
   dimensional and visual evidence.
5. Resolve F-15 through F-18 after selecting the exact panel owners and
   collision regions.
6. Close the systemic owner, exterior, seam, and bed-fit findings F-25 through
   F-27 and F-29.
7. Run the full physical acceptance set before any structural ASA release.

## Active item

- [ ] **Current:** F-19 read-only V34 eye/socket conflict audit.
- [ ] Exact target object selected.
- [ ] First mutation contract approved.

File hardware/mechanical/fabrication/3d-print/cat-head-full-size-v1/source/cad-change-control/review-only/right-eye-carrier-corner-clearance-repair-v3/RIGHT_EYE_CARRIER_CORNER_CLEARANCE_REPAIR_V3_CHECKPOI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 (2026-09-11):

# Right Eye Carrier Corner-Clearance Repair V3 Checkpoint — 2026-08-19

## Status

`REVIEW_ONLY_READY__AWAITING_CORNER_CLEARANCE_LGTM`

This is review evidence only. It is not a print source and no STL, 3MF, G-code,
mirror, production candidate, or canonical geometry was created or replaced.

## User-reported defect and disposition

The V2 full-depth outer seam visibly conflicted with the lower shell corner. V2
is withdrawn. An independent exact contact measurement confirmed that this was
not merely a display artifact:

- exact shell owner: `FROZEN_RIGHT_LOWER_MAIN_V34`
- V2 new-material distance: `0.0 mm`
- positive common volume: `0.0 mm3`
- contact section: `14 edges / 10 vertices`
- section AABB minimum: `[33.616827841961644, 50.10706152387267, 125.15017980822562] mm`
- section AABB maximum: `[34.97628050201239, 52.03217039868513, 126.15882478700713] mm`

Attribution showed that only the V2 outer spine contacted the shell. The V2
structural backing remained `0.5628441175178516 mm` clear, and the unchanged
source carrier remained `0.35665372063694045 mm` clear.

## V3 correction

V3 preserves the source carrier, user manual flange, and exact V2 structural
backing. It changes only the V2 outer spine by subtracting the measured contact
AABB expanded `1.50 mm` on all sides.

Two smaller tooling preflights were rejected before review output:

- `0.75 mm` padding -> `0.2501749889 mm` clearance: FAIL
- `1.10 mm` padding -> `0.3867824984 mm` clearance: FAIL
- `1.50 mm` padding -> `0.5628441175178516 mm` clearance: PASS

## Passing evidence

- new-material clearance to the corner owner: `0.5628441175178516 mm`
- minimum new-material clearance to every shell owner: `0.5628441175178516 mm`
- shell contact-section edges/vertices: `0 / 0`
- positive shell overlap: `0.0 mm3`
- source carrier removed: `0.0 mm3`
- V2 structural backing missing: `0.0 mm3`
- V2 outer-spine material removed by the notch: `12.209215069951282 mm3`
- global full-depth span retained: `4.200000017484356 mm`
- final carrier: valid, closed, one solid, deep-OCCT clean
- final mesh audit: one component; zero boundary, nonmanifold, degenerate,
  duplicate, and self-intersecting facets; outward normals
- lens, rear plate, screws, LEDs, and wire intersections from added material:
  all `0.0 mm3`

Positive structural roots remain:

- backing-to-transition: `27.027802073044768 mm3`
- backing-to-walls: `319.96119527609505 mm3`
- spine-to-backing: `180.60258687447262 mm3`
- spine-to-bezel: `58.95666393814595 mm3`
- spine-to-front-filler: `103.71263446972283 mm3`
- spine-to-lens-surround: `132.46014817716522 mm3`
- spine-to-opening-connector: `125.4632670382928 mm3`

## Pinned files

- contract SHA-256: `ce445a115941fd4ecb39633515a1eb5b126c7cadbd29a3ad3ca8c007e177b315`
- generator SHA-256: `a0a5e8c8ee55f889673ee7d412c37cd578fe28c52bbacdab572a9dce7bd35a29`
- contact-measurement script SHA-256: `1a19bda51ab4197ed4d1529c9885ae71cdf5f94c52576f47696b98733e04c5c8`
- feasibility report SHA-256: `f2fda661a0371820b8970e386f7b26ca3f213444218246e1bb07289cd67a2e70`
- review FCStd SHA-256: `22dca83ac335ad9277ec89bd248f65c3646af4c6d5945b1e28367dfcee7ba94f`
- validation SHA-256: `52170ecd6b2b0e8d3d299cb254eb997956c229c2462db645b24d44eb5d88108f`

## Review pack

Directory:

`output/70-freecad-pilots/review-only/right-eye-carrier-corner-clearance-repair-v3/`

Primary model:

`RIGHT_EYE_CARRIER_CORNER_CLEARANCE_REPAIR_REVIEW_ONLY_V3.FCStd`

Fixed views:

- `assembled-context.png`
- `corner-shell-clearance-closeup.png`
- `repair-only-corner-closeup.png`
- `left-seam.png`
- `right-seam.png`

All five fixed views were inspected. In the exact before/after corner view, the
withdrawn V2 repair touches the gray shell while V3 has a visible gap. The seam
views show a continuous replacement chain. The cyan box in the repair-only view
is a review reference for the clearance cut; it is not printable carrier material.

## Commands used

Feasibility:

```bash
timeout 300s env PYTHONPATH=/tmp/freecad-1.1.3-extract/squashfs-root/usr/lib /tmp/freecad-1.1.3-extract/squashfs-root/AppRun python -B hardware/mechanical/fabrication/3d-print/cat-head-full-size-v1/source/cad-change-control/review-only/right-eye-carrier-corner-clearance-repair-v3/generate_review.py --mode feasibility --report /tmp/right-eye-carrier-corner-clearance-repair-v3-feasibility.json
```

Review generation:

```bash
timeout 420s env PYTHONPATH=/tmp/freecad-1.1.3-extract/squashfs-root/usr/lib /tmp/freecad-1.1.3-extract/squashfs-root/AppRun python -B hardware/mechanical/fabrication/3d-print/cat-head-full-size-v1/source/cad-change-control/review-only/right-eye-carrier-corner-clearance-repair-v3/generate_review.py --mode review --feasibility-report /tmp/right-eye-carrier-corner-clearance-repair-v3-feasibility.json --feasibility-sha256 f2fda661a0371820b8970e386f7b26ca3f213444218246e1bb07289cd67a2e70
```

## Next authorized boundary

The user must visually review the exact corner in the V3 FCStd or
`corner-shell-clearance-closeup.png`. A separate explicit approval is required
before producing any print-authoritative model, mirror, STL, 3MF, or G-code.

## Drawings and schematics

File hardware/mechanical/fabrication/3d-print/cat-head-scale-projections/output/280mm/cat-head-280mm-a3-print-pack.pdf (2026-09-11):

# CAT HEAD 280 mm — FRONT PROJECTION

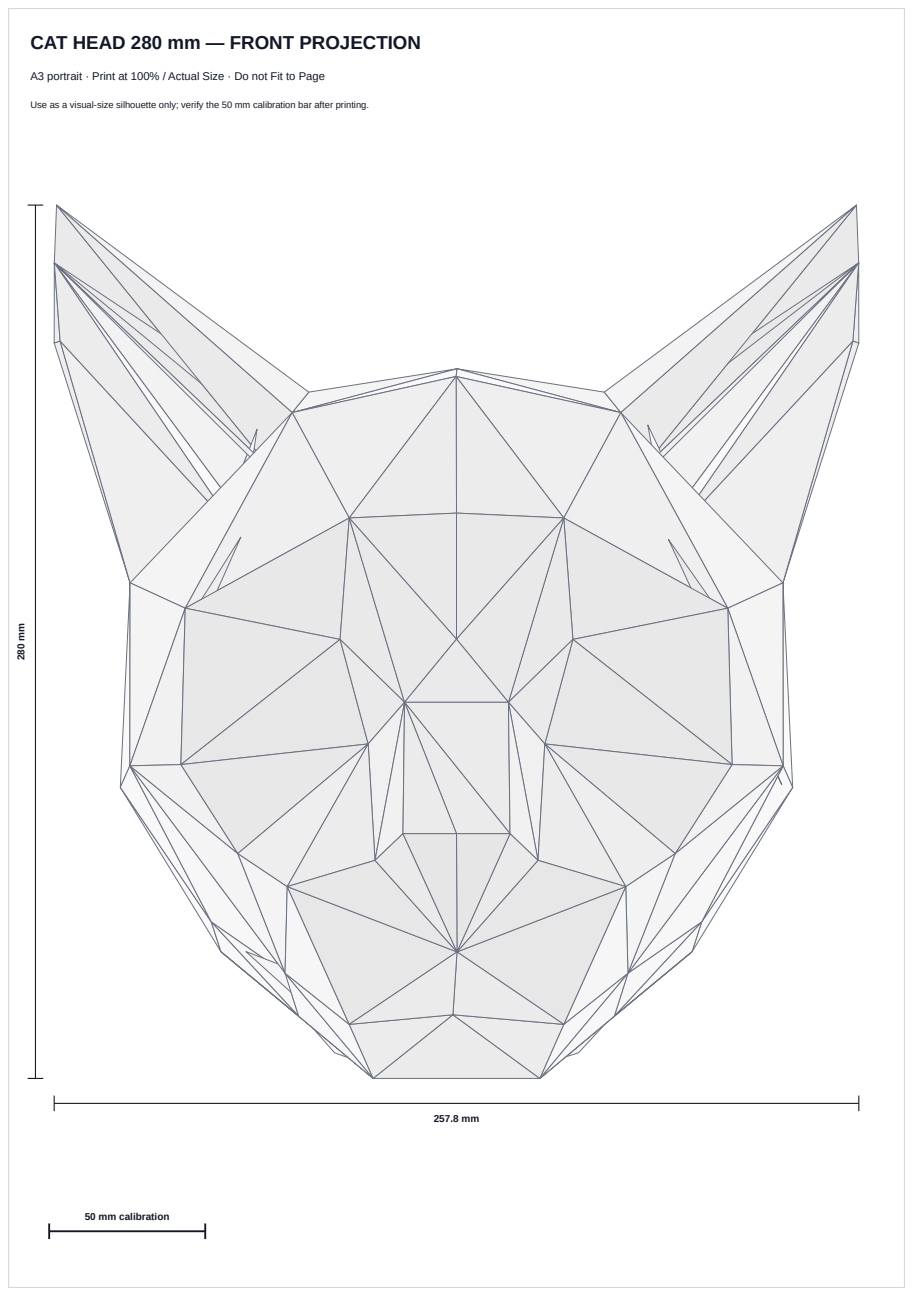
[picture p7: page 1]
50 mm calibration

A3 portrait · Print at 100% / Actual Size · Do not Fit to Page

Use as a visual-size silhouette only; verify the 50 mm calibration bar after printing.

# CAT HEAD 280 mm — SIDE PROJECTION

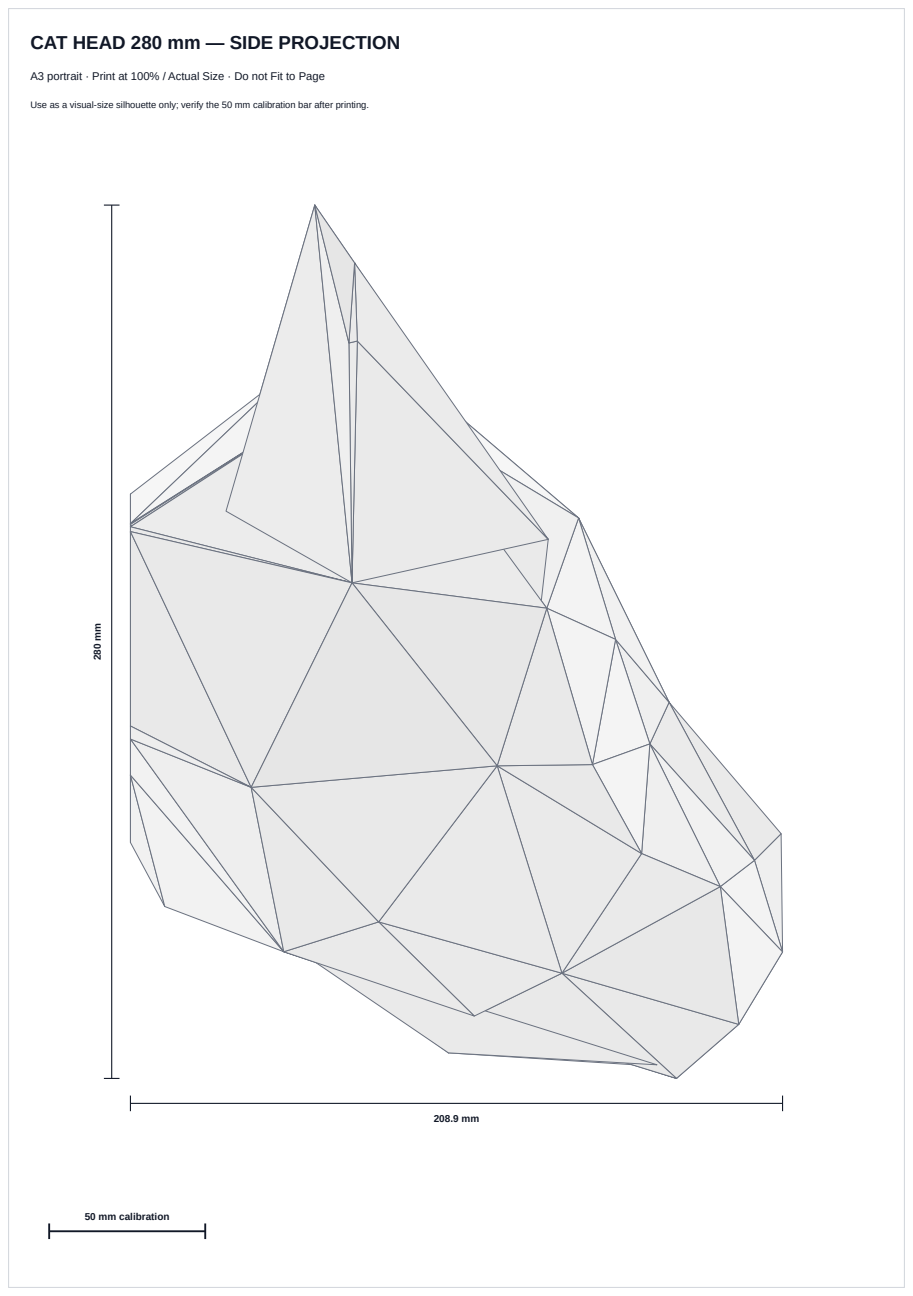
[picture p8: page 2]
50 mm calibration

A3 portrait · Print at 100% / Actual Size · Do not Fit to Page

Use as a visual-size silhouette only; verify the 50 mm calibration bar after printing. 280 mm

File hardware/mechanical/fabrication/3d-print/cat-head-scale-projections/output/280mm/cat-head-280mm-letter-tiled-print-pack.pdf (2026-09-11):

# CAT HEAD 280 mm — FRONT — TOP

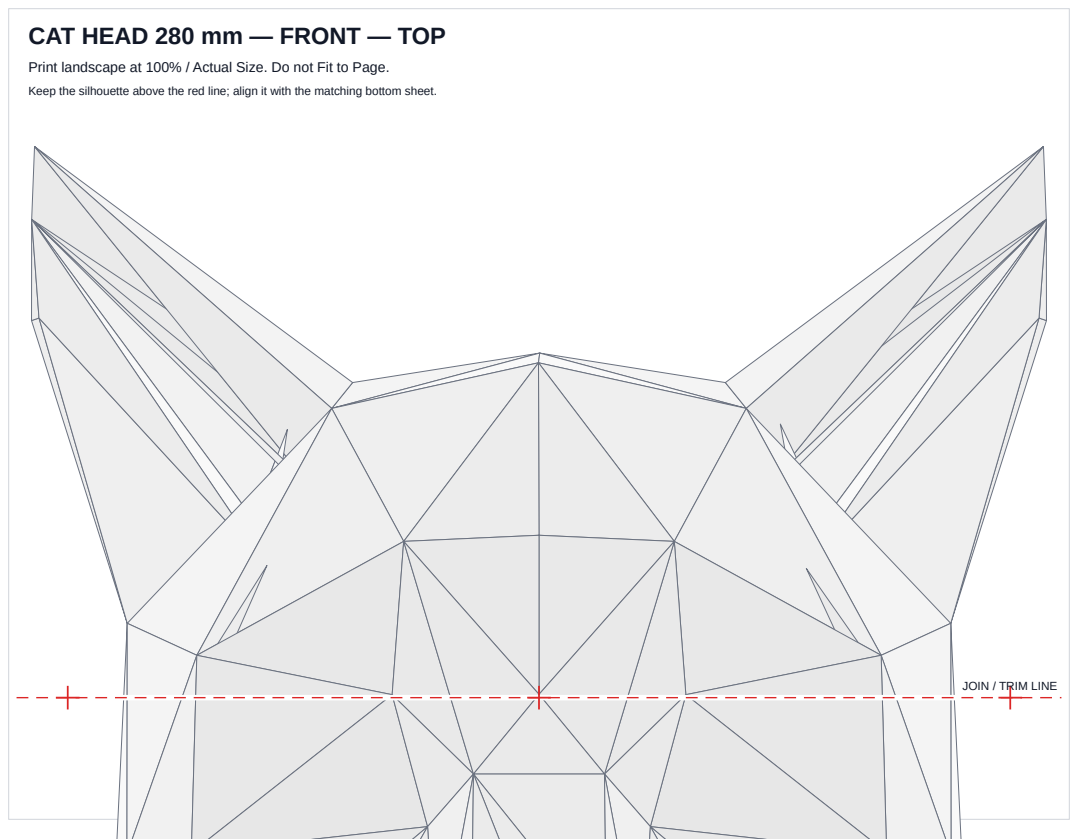
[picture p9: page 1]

Print landscape at 100% / Actual Size. Do not Fit to Page.

Keep the silhouette above the red line; align it with the matching bottom sheet.

JOIN / TRIM LINE

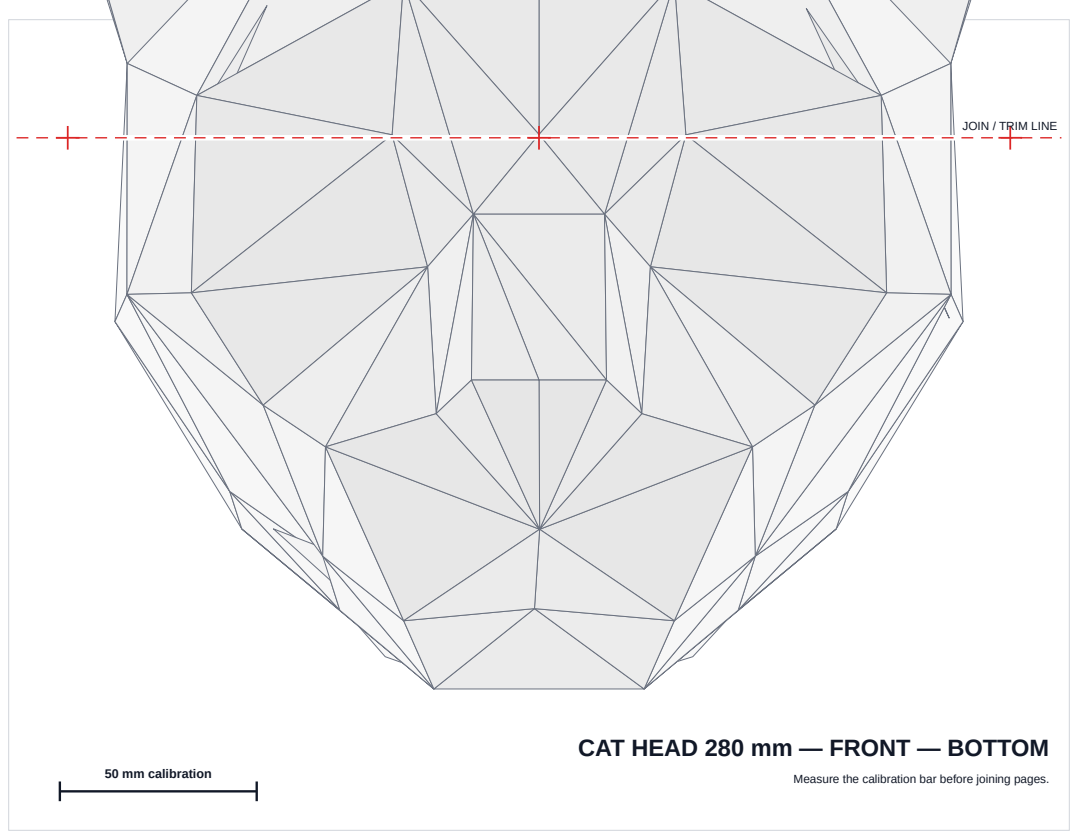
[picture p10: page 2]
50 mm calibration

JOIN / TRIM LINE

CAT HEAD 280 mm — FRONT — BOTTOM

Measure the calibration bar before joining pages.

# CAT HEAD 280 mm — SIDE — TOP

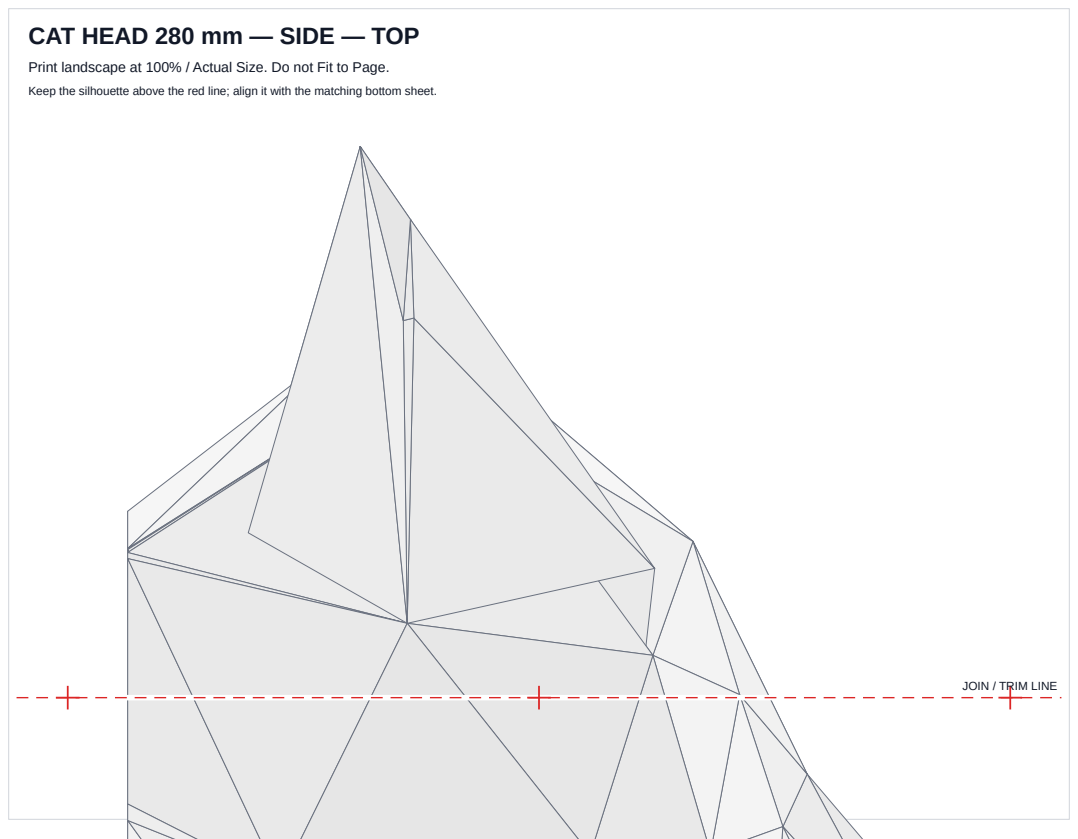
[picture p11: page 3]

Print landscape at 100% / Actual Size. Do not Fit to Page.

Keep the silhouette above the red line; align it with the matching bottom sheet.

JOIN / TRIM LINE

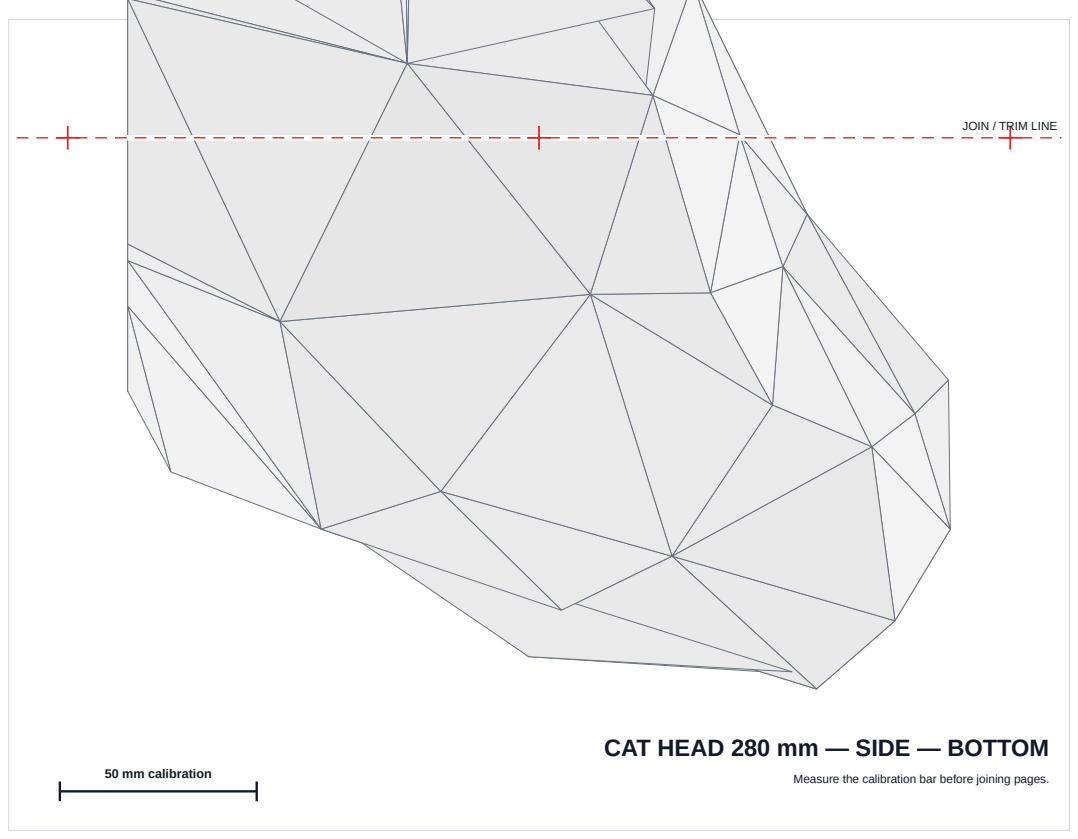
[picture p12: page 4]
50 mm calibration

JOIN / TRIM LINE

CAT HEAD 280 mm — SIDE — BOTTOM

Measure the calibration bar before joining pages.

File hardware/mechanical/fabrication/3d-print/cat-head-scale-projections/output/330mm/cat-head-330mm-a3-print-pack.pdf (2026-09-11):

# CAT HEAD 330 mm — FRONT PROJECTION

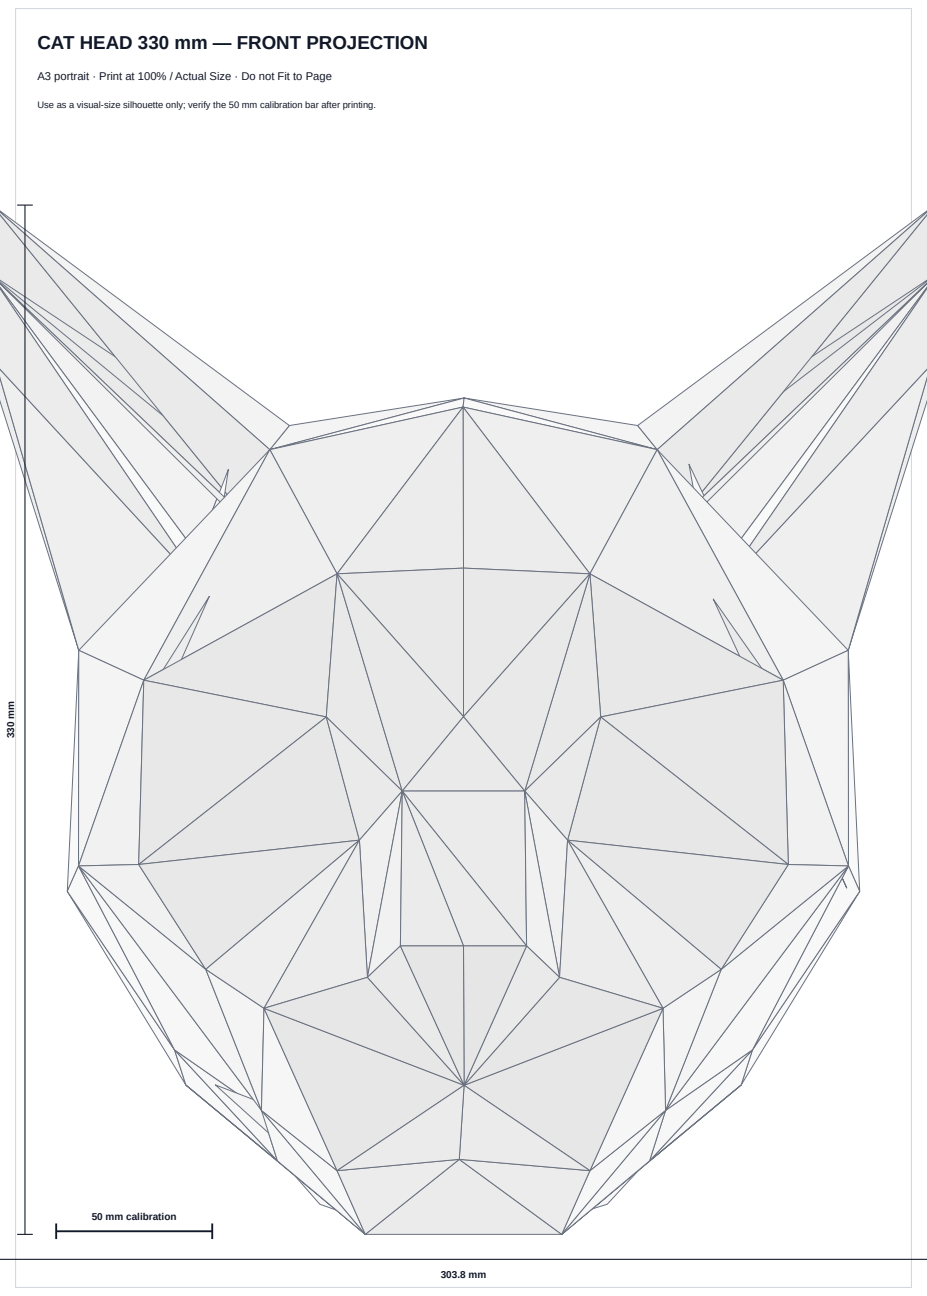
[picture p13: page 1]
50 mm calibration

A3 portrait · Print at 100% / Actual Size · Do not Fit to Page

Use as a visual-size silhouette only; verify the 50 mm calibration bar after printing.

# CAT HEAD 330 mm — SIDE PROJECTION

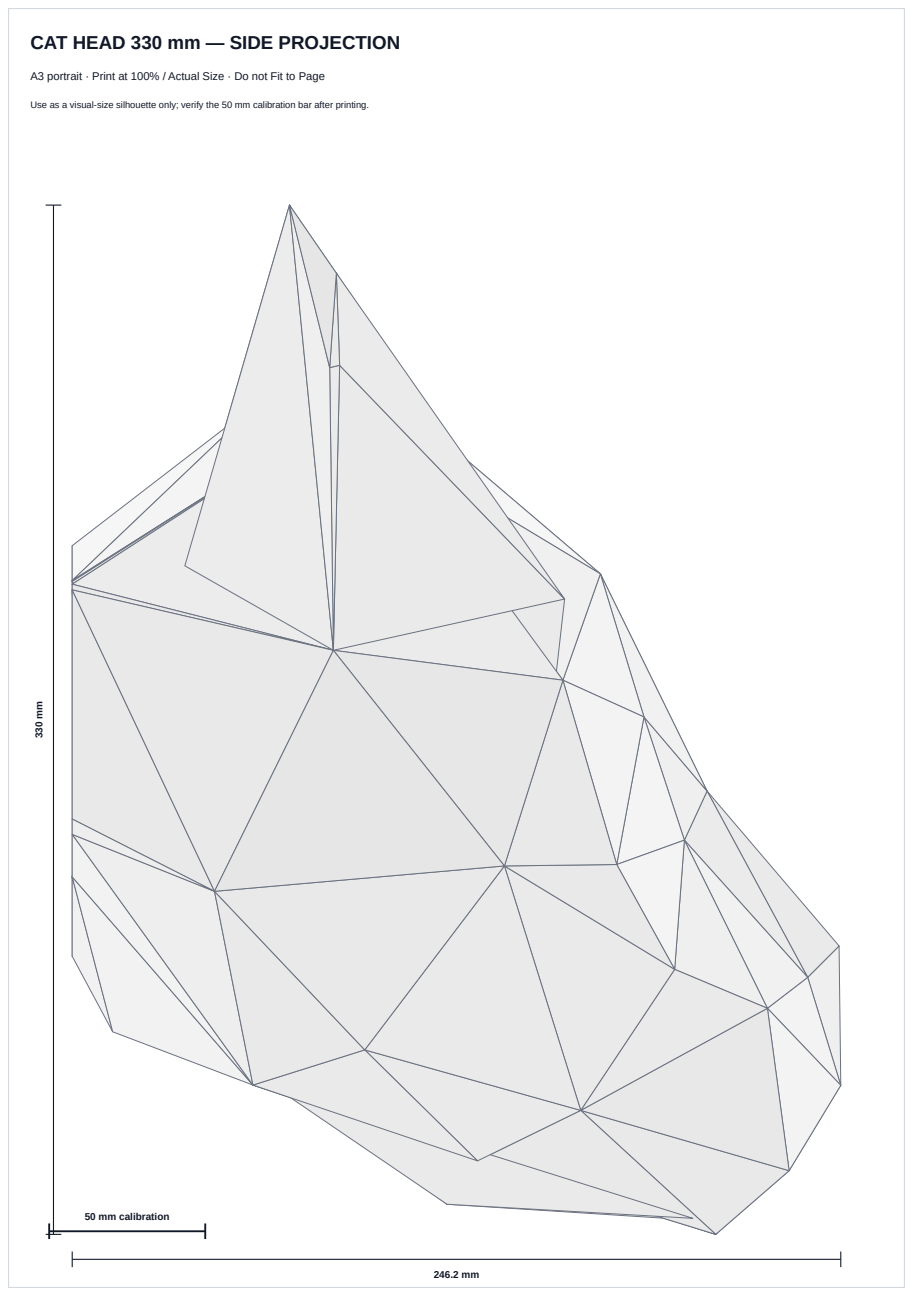
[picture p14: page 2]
50 mm calibration

A3 portrait · Print at 100% / Actual Size · Do not Fit to Page

Use as a visual-size silhouette only; verify the 50 mm calibration bar after printing. 330 mm

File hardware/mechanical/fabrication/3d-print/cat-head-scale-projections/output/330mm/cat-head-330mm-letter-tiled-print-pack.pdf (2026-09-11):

# CAT HEAD 330 mm — FRONT — TOP

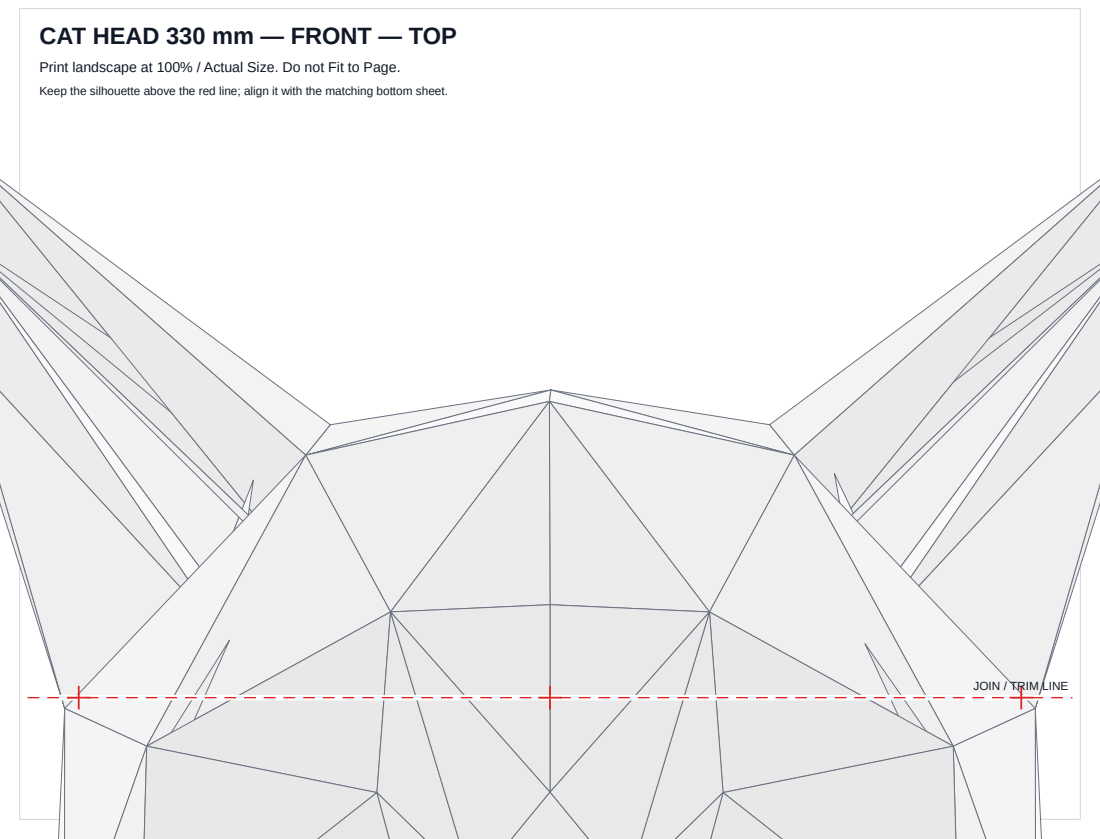
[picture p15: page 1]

Print landscape at 100% / Actual Size. Do not Fit to Page.

Keep the silhouette above the red line; align it with the matching bottom sheet.

JOIN / TRIM LINE

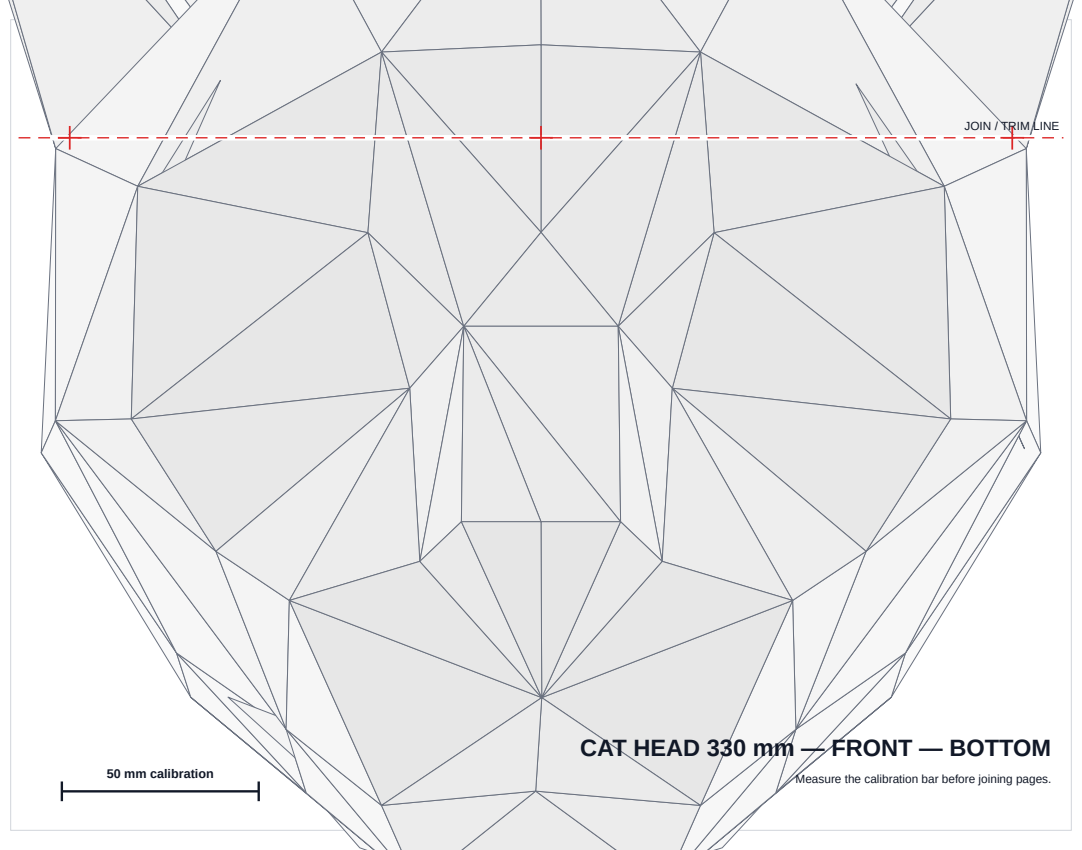
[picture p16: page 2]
50 mm calibration

JOIN / TRIM LINE

CAT HEAD 330 mm — FRONT — BOTTOM

Measure the calibration bar before joining pages.

# CAT HEAD 330 mm — SIDE — TOP

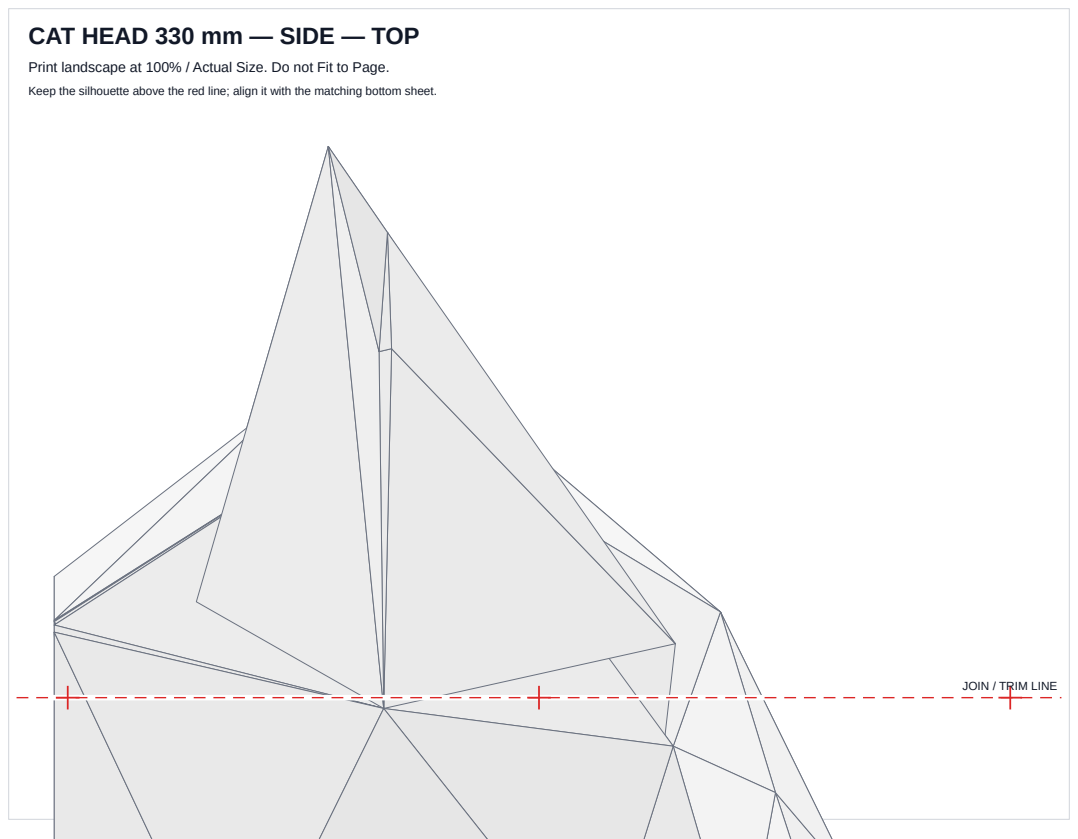
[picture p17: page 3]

Print landscape at 100% / Actual Size. Do not Fit to Page.

Keep the silhouette above the red line; align it with the matching bottom sheet.

JOIN / TRIM LINE

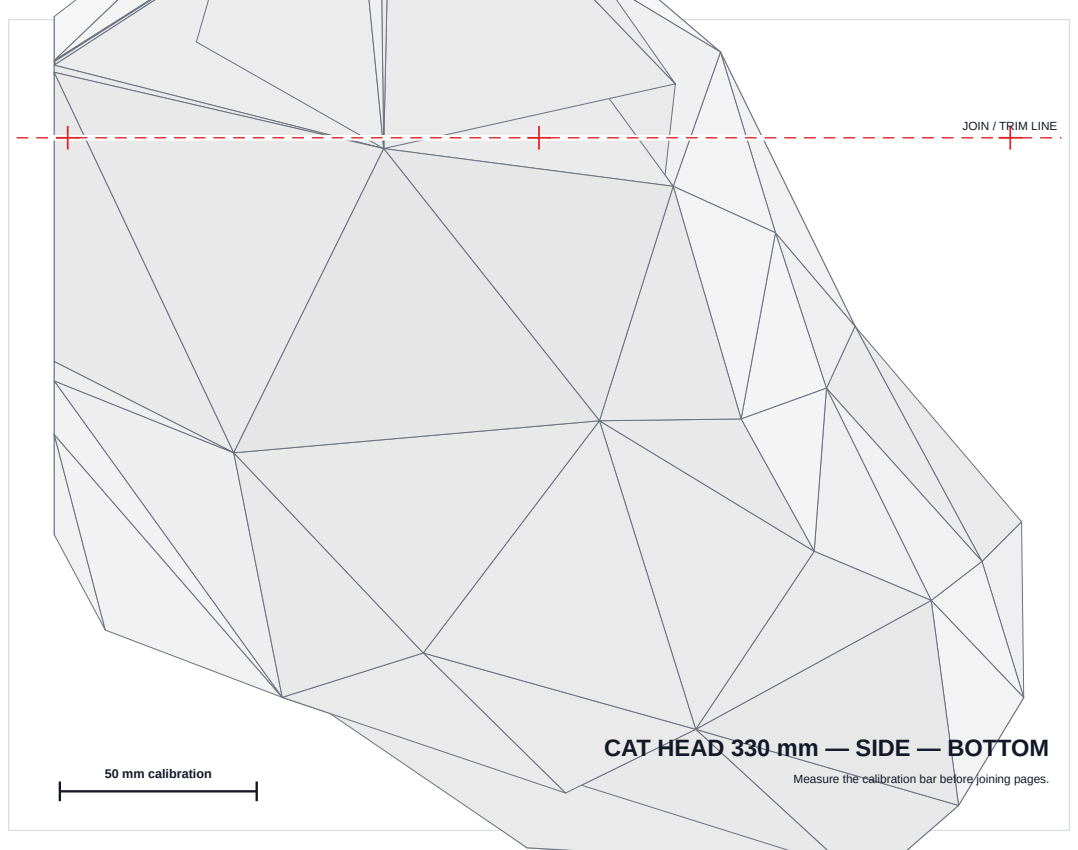
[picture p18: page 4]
50 mm calibration

JOIN / TRIM LINE

CAT HEAD 330 mm — SIDE — BOTTOM

Measure the calibration bar before joining pages.

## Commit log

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2026-07-14 Add cat head fabrication checkpoint
    [accepted-panels-3d.obj, candidate-panels-3d.obj, candidate-panels-combined.obj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]
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2026-07-31 Complete under-ear insert and anti-flap redesign
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2026-08-05 Revert "Cut rear facets from lower-face review"
    This reverts commit 9be17c120205c9057edf3ae6e079e641386cc12e.
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2026-08-12 Checkpoint approved primary ear interface
    [CAT_HEAD_RIGHT_PRIMARY_EAR_INTEGRATED_THROUGH_CHANNEL_REVIEW_V3.FCStd]
2026-08-12 Add bilateral primary ear review
    [CAT_HEAD_PRIMARY_EAR_BILATERAL_THROUGH_CHANNEL_REVIEW_V1.FCStd]
2026-08-12 Add exact mirrored primary-ear bilateral review V2
    [CAT_HEAD_PRIMARY_EAR_BILATERAL_EXACT_MIRROR_REVIEW_V2.FCStd]
2026-08-12 Add right eye cap anchor audit
    [CAT_HEAD_RIGHT_EYE_BUCKET_CAP_ANCHOR_AUDIT_V1.FCStd]
2026-08-12 Correct right eye connector identification
    [CAT_HEAD_RIGHT_EYE_BUCKET_CAP_ANCHOR_AUDIT_V1.FCStd, CAT_HEAD_RIGHT_EYE_EXISTING_CONNECTOR_PAIR_IDENTIFICATION_V1.FCStd]
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2026-08-12 Add right eye connector relocation review
    [CAT_HEAD_RIGHT_EYE_UPPER_PERIMETER_CONNECTOR_PAIR_RELOCATION_REVIEW_V1.FCStd]
2026-08-12 Clean obsolete right eye connector loop
    [CAT_HEAD_RIGHT_EYE_UPPER_PERIMETER_CONNECTOR_PAIR_CLEAN_REVIEW_V2.FCStd]
2026-08-12 Build one-body right eye module review
    [CAT_HEAD_RIGHT_EYE_ONE_BODY_SERVICEABLE_MODULE_REVIEW_V1.FCStd]
2026-08-12 Join right eye upper rim to bucket
    [CAT_HEAD_RIGHT_EYE_UPPER_RIM_STRUCTURAL_ROOT_REVIEW_V1.FCStd]
2026-08-12 Document cat-head source integrity audit
    [CAT_HEAD_RIGHT_EYE_UPPER_RIM_SOURCE_INTEGRITY_AUDIT_V1.FCStd]
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2026-08-12 Rebuild right eye from six source solids
    [CAT_HEAD_RIGHT_EYE_SIX_SOURCE_REBUILD_REVIEW_V1.FCStd]
2026-08-12 Add exact right-eye wall-plane review
    [CAT_HEAD_RIGHT_EYE_EXACT_FACE_PAIRS_CORE_REVIEW_V4.FCStd, right-eye-exact-three-plane-chamber-v4.blend, right-eye-exact-three-plane-chamber-v4.stl]
2026-08-12 Add additive right eye wall continuation review
    [CAT_HEAD_RIGHT_EYE_ADDITIVE_WALL_CONTINUATION_REVIEW_V5.FCStd, right-eye-additive-wall-continuations-v5.blend]
2026-08-12 Extend right eye walls to front plane
    [CAT_HEAD_RIGHT_EYE_DELETE_STRIPS_EXTEND_WALLS_REVIEW_V6.FCStd, right-eye-delete-strips-extend-walls-v6.blend]
2026-08-12 Remove right eye rear-cap posts
    [CAT_HEAD_RIGHT_EYE_REMOVE_CAP_POSTS_REVIEW_V7.FCStd]
2026-08-13 Promote validated right eye production owners
    [CAT_HEAD_RIGHT_EYE_PRODUCTION_OWNER_REVIEW_V8.FCStd, right_eye_bucket_production_owner_v8.step, right_eye_rear_cap_production_owner_v8.step]
2026-08-13 Add bilateral eye mirror review V9
    [CAT_HEAD_EYE_BILATERAL_EXACT_MIRROR_REVIEW_V9.FCStd, CAT_HEAD_EYE_BILATERAL_EXACT_MIRROR_REVIEW_V9.blend, left_eye_bucket_exact_x0_mirror_v9.step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]
2026-08-13 Approve bilateral eye owners V9
    [left_eye_bucket_production_owner_v9.step, left_eye_rear_cap_production_owner_v9.step, right_eye_bucket_production_owner_v9.step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]
2026-08-13 Add right eye flange owner alignment review
    [CAT_HEAD_RIGHT_EYE_FLANGE_OWNER_ALIGNMENT_REVIEW_V1.FCStd, CAT_HEAD_RIGHT_EYE_FLANGE_OWNER_ALIGNMENT_REVIEW_V1.blend]
2026-08-13 Add right eye C048 clearance review
    [CAT_HEAD_RIGHT_EYE_C048_CLEARANCE_REVIEW_V1.FCStd, CAT_HEAD_RIGHT_EYE_C048_CLEARANCE_REVIEW_V1.blend]
2026-08-13 Add wider right eye reinforcement clearance
    [CAT_HEAD_RIGHT_EYE_REINFORCEMENT_CLEARANCE_REVIEW_V2.FCStd, CAT_HEAD_RIGHT_EYE_REINFORCEMENT_CLEARANCE_REVIEW_V2.blend]
2026-08-13 Audit right eye owner integration
    [CAT_HEAD_RIGHT_EYE_FLANGE_REINFORCEMENT_OWNER_INTEGRATION_AUDIT_V1.FCStd, CAT_HEAD_RIGHT_EYE_FLANGE_REINFORCEMENT_OWNER_INTEGRATION_REVIEW_V1.blend]
2026-08-13 Add right eye internal root review
    [CAT_HEAD_RIGHT_EYE_INTERNAL_ROOT_EMBED_REVIEW_V1.FCStd, CAT_HEAD_RIGHT_EYE_INTERNAL_ROOT_EMBED_REVIEW_V1.blend, approved_lower_head_flange.obj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]
2026-08-13 Replace protruding eye roots with rectangular bases
    [CAT_HEAD_RIGHT_EYE_RECTANGULAR_ROOT_REVIEW_V2.FCStd, CAT_HEAD_RIGHT_EYE_RECTANGULAR_ROOT_REVIEW_V2.blend, approved_lower_head_flange.obj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]
2026-08-14 Add direct eye flange depth extension review
    [CAT_HEAD_RIGHT_EYE_OUTER_PAIR_FACE879_DEPTH_EXTENSION_REVIEW_V3.FCStd, CAT_HEAD_RIGHT_EYE_OUTER_PAIR_FACE879_DEPTH_EXTENSION_REVIEW_V3.blend]
2026-08-14 Add radial eye flange thickness review
    [CAT_HEAD_RIGHT_EYE_OUTER_PAIR_RADIAL_THICKNESS_REVIEW_V4.FCStd, CAT_HEAD_RIGHT_EYE_OUTER_PAIR_RADIAL_THICKNESS_REVIEW_V4.blend]
2026-08-14 Build all four thickened right eye flanges
    [CAT_HEAD_RIGHT_EYE_ALL_FOUR_PLAIN_FLANGE_THICKNESS_REVIEW_V5.FCStd, CAT_HEAD_RIGHT_EYE_ALL_FOUR_PLAIN_FLANGE_THICKNESS_REVIEW_V5.blend]
2026-08-14 Clip right eye head flanges to shell
    [CAT_HEAD_RIGHT_EYE_HEAD_FLANGE_EXTERIOR_CLIP_REVIEW_V6.FCStd, CAT_HEAD_RIGHT_EYE_HEAD_FLANGE_EXTERIOR_CLIP_REVIEW_V6.blend, lower_eye_v6.obj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]
2026-08-14 Clip right eye flanges inside shell skins
    [CAT_HEAD_RIGHT_EYE_ALL_FOUR_FLANGE_LOCAL_SKIN_CLIP_REVIEW_V7.FCStd, CAT_HEAD_RIGHT_EYE_ALL_FOUR_FLANGE_LOCAL_SKIN_CLIP_REVIEW_V7.blend, lower_eye_v7.obj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]
2026-08-14 Correct right eye flange ownership
    [CAT_HEAD_RIGHT_EYE_UPPER_HEAD_ONLY_DUAL_PAIR_REVIEW_V8.FCStd, CAT_HEAD_RIGHT_EYE_UPPER_HEAD_ONLY_DUAL_PAIR_REVIEW_V8.blend, inner_upper_eye_v8.obj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]
2026-08-14 Reject duplicate right eye flange pair
    [CAT_HEAD_RIGHT_EYE_UPPER_HEAD_ONLY_DUAL_PAIR_REVIEW_V8.FCStd]
2026-08-14 Remove obsolete right eye flange neck
    [CAT_HEAD_RIGHT_EYE_SECOND_PAIR_NECK_REMOVAL_REVIEW_V9.FCStd, CAT_HEAD_RIGHT_EYE_SECOND_PAIR_NECK_REMOVAL_REVIEW_V9.blend, outer_eye_unchanged_v9.obj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]
2026-08-14 Correct right eye outer neck ownership review
    [CAT_HEAD_RIGHT_EYE_OUTER_NECK_REMOVAL_UPPER_HEAD_OWNER_REVIEW_V10.FCStd, CAT_HEAD_RIGHT_EYE_OUTER_NECK_REMOVAL_UPPER_HEAD_OWNER_REVIEW_V10.blend, outer_eye_unc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]
2026-08-14 Restore approved right-eye reinforcement clearance
    [CAT_HEAD_RIGHT_EYE_NECK_REMOVAL_CLEARANCE_REGRESSION_FIX_REVIEW_V11.FCStd, CAT_HEAD_RIGHT_EYE_NECK_REMOVAL_CLEARANCE_REGRESSION_FIX_REVIEW_V11.blend, outer_eye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]
2026-08-14 Checkpoint head topology and print orientation reviews
    [CAT_HEAD_RIGHT_AB_OWNER_INTEGRATION_REVIEW_V1.FCStd, CAT_HEAD_RIGHT_LOWER_FACE_COMPONENT_001_SELF_UNION_REVIEW_V12.blend, right-ab-print-orientation-review-v1.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]
2026-08-14 Add under-ear print orientation review
    [right-ab-under-ear-opening-print-orientation-review-v2.blend]
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2026-08-15 Add C027 eye clearance review
    [CAT_HEAD_RIGHT_UPPER_C027_EYE_CLEARANCE_REVIEW_V19.FCStd]
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2026-08-15 Add upper-eye collision localization review
    [CAT_HEAD_RIGHT_UPPER_EYE_RESIDUAL_COLLISION_LOCALIZATION_REVIEW_V21.FCStd]
2026-08-15 Add corrected C001 anchor review
    [CAT_HEAD_RIGHT_UPPER_EYE_C001_EXACT_ANCHOR_REVIEW_V22.FCStd]
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2026-08-15 Add upper C012 eye clearance review
    [CAT_HEAD_RIGHT_UPPER_C012_EYE_CLEARANCE_REVIEW_V24.FCStd]
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2026-08-16 Preserve C001 eye-clearance rail review
    [CAT_HEAD_RIGHT_UPPER_C001_EYE_CLEARANCE_REVIEW_V26.FCStd, CAT_HEAD_RIGHT_UPPER_C001_PRESERVED_RAIL_ROOT_REVIEW_V27.FCStd]
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2026-08-16 Make CAD OCCT audit fail closed
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2026-09-11 Preserve retained BM build files with Git LFS
    [Both_eyes_PRINT_V1.3mf, CAT_HEAD_EYE_BILATERAL_EXACT_MIRROR_REVIEW_V9.FCStd, CAT_HEAD_EYE_BILATERAL_EXACT_MIRROR_REVIEW_V9.blend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]
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
